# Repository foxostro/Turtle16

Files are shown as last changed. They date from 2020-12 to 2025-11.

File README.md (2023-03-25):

# Turtle16

Turtle16 is a sixteen-bit microcomputer built from discrete logic ICs and other simple parts. This repo contains the Kicad project, and other files necesary to build the hardware, as well as the simulator, assembler, and compiler.

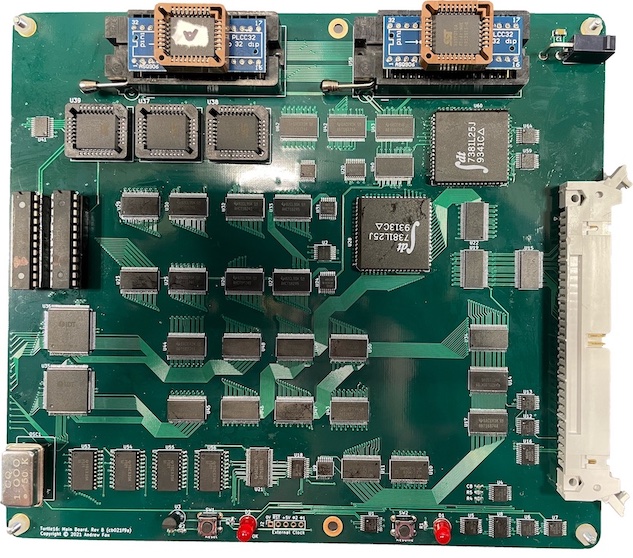
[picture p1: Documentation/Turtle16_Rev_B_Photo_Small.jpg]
Photo of Turtle16 CPU


## Computer Specifications

* Sixteen-bit homebrew CPU
* Five stage classic RISC pipeline, executing one instruction per clock cycle
* Eight general-purpose registers
* Operand forwarding to automatically resolve read-after-write hazards
* Pipeline stalls to automatically resolve other sorts of hazards
* No branch delay slots
* Primitive branch prediction, always predicting the branch is not taken

## Why did you do this?

I find computer architecture to be very interesting. Having already built a couple of homebrew breadboard computers in the style of the SAP-1, I wanted to do something more advanced. This an opportunity to learn how the classic five stage RISC pipeline works. While it would also be possible to build something like this in an FPGA, or even just an HDL simulator, I appreciate the physical reality of building an actual thing. At the same time, I've been learning so much about PCB layout, circuit design, circuit assembly and construction, and debugging, much of which seems broadly applicable to any electronics project.

Careful self-imposed limitations are important for a successful project. Limitation breeds creativity. For this project, the implementation of the CPU itself has been constrained to use only simple 7400-style parts. This means sticking to discrete logic and other medium-scale integration parts. Microprocessors and advanced FPGAs have been avoided. An exception has been made for primitive GALs as these fit the retro computer aesthetic.

For the computer's peripherals, I might relax these limitations in favor of getting something working. For example, I'm considering using an Arduino to interface with a PC. The sound hardware could be built around a retro-style audio IC such as one of the Yamaha OPL series chips or the Phillips SAA1099.

The danger of relaxing limitations is that it raises the question, why not go further? If I decide it's fine to implement graphics using a retro-style chip like the TMS9918A then why not use a Raspberry Pi, or the Gameduino 3X Dazzler? Why not simply implement the entire computer in an emulator running on a Raspberry Pi? Once placed in an enclosure, it won't look any different. The answer is that the project is not about the goal of building a working computer, or the goal of playing some games. This project is centered around learning how computers work.

## Getting Started

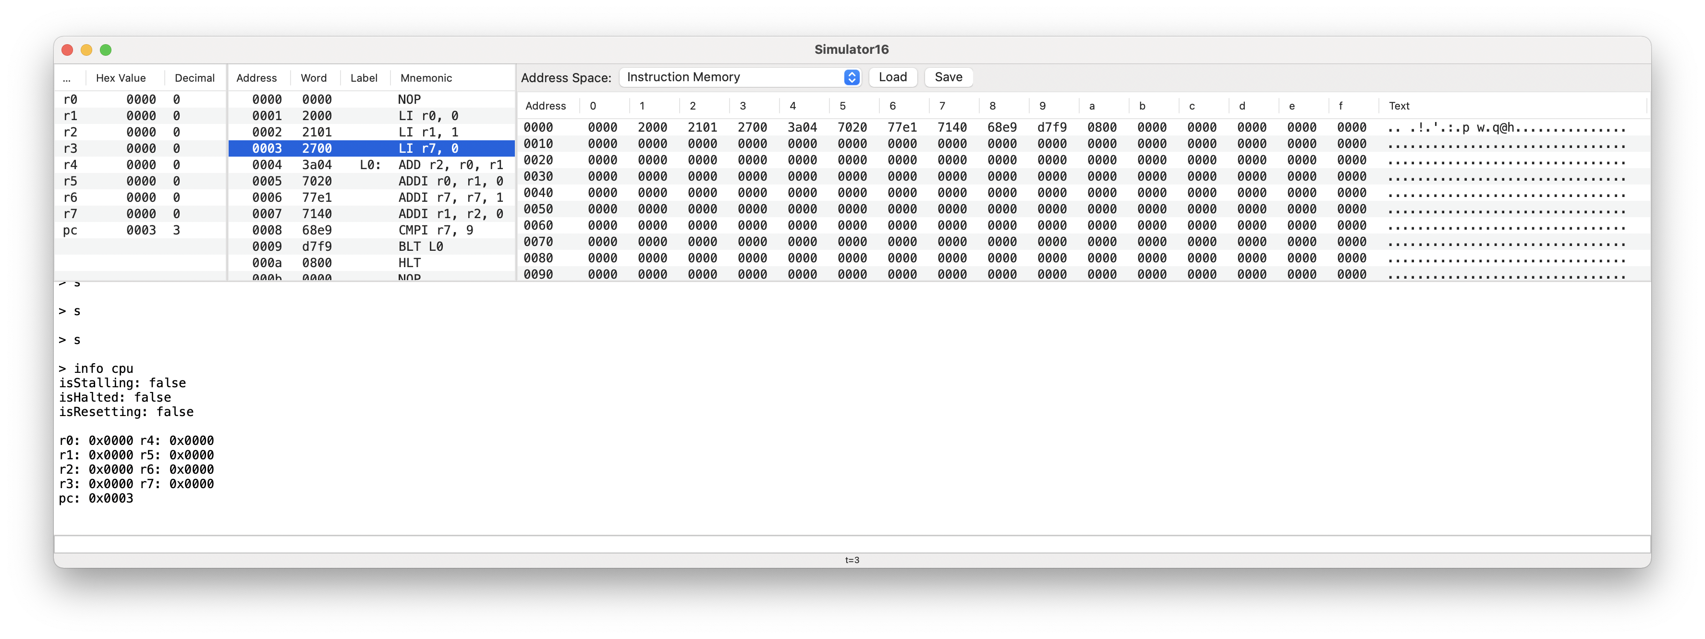
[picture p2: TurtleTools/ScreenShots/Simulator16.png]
Simulator16 Screen Shot


The simulator app can be used to simulate the computer and run example programs without having to build the hardware. The interactive debugger can be used to inspect the state of the computer. Several example saved simulator sessions are available in the TurtleTools/Examples/ directory. (At some point, I should add some better demoes. These are mostly just programs that I used in hardware verification.)

To run the simulator, open the TurtleTools Xcode project and run the Simulator16 scheme. Refer to the [Tool Chain](Documentation/TurtleTools.md) page for more details.

## Documentation

* [Architecture Overview](Documentation/Architecture.md)
* [Instruction Set Architecture](Documentation/ISA.md)
* [Programming](Documentation/Programming.md)
* [Tool Chain](Documentation/TurtleTools.md)
* [Bugs](Documentation/Bugs.md)
* [Future Work](Documentation/Future.md)

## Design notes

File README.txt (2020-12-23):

Turtle16 is a sixteen-bit microcomputer built from discrete logic ICs and other simple parts. This repo contains the Kicad project and other files necesary to build the hardware. The toolchain and software is provided in a separate repo.

Project Constraints
-------------------
Microprocessors and programmable hardware such as CPLDs and FPGAs have been avoided. An exception has been made for primitive GALs as these fit the retro computer aesthetic.

Architecture Overview
---------------------
The CPU uses a Load/Store architecture based on the classic RISC pipeline. There are eight general-purpose registers, each sixteen bits wide. The load/store unit fetches sixteen-bit words from a sixteen-bit address space. Instructions and Data are split into two separate address spaces, avoiding any possible structural hazard from accessing instructions and data simultaneously.

Pipeline Stages:
1. IF — Fetch an instruction from Instruction Memory via the Program Counter
2. ID — Decode instruction and read the register file. This also performs hazard control on decoding the instruction.
3. EX — Marshal operands and perform a computation
4. MEM — Either read or write to memory
5. WB — Write results back to the register file

The control unit implements primitive branch prediction which always predicts the branch is not taken and then flushes the pipeline when it ever actually is, thus avoiding the need for branch delay slots. A delay slot between the ALU's computation of flags and the Instruction Decode stage's use of flags is avoided by having the control unit stall the CPU for one cycle. Read-After-Write hazards are also avoided by stalling the CPU until the hazard has passed.

The register file is implemented in two dual port SRAMs operating in parallel. This allows for a triple-port register file with one write port and two read ports. With careful design, a write in the write-back stage can be assured to be committed before a register file read in the same cycle. Due to space limitations in the instruction word, only three bits can be devoted to the register index. The register can only provide eight homogeneous, general-purpose registers.

The ALU is built around an IDT 7831. This is a monolithic, sixteen-bit ALU IC that was produced in the early 90's.

Peripheral devices may halt the CPU by pulling the shared RDY signal low using an open-drain buffer such as 74AHCT07A. While halted this way, the CPU disconnects from the bus so that peripheral devices may drive the bus as they see fit. The CPU's Phi1 clock immediately drops to zero and stops. The CPU's Phi2 clock is unaffected, and this is the one exposed to peripheral devices.

The clock module ensures /RDY only takes affect on the clock edge so devices may acquire and release /RDY at any time.

The main board does not include RAM or peripherals. The intention is that these devices would be implemented on separate boards and connected to the main board through an external peripheral connector.

Control Signals
---------------
The instruction decoder in the ID stage of the CPU pipeline decode the five-bit opcode into twenty one control signals which control subsequent pipeline stages.

0. /HLT — Halt the clock
1. SelStoreOpA — Select the source of the Store operand
2. SelStoreOpB — "
3. SelRightOpA — Select the source of the Right operand
4. SelRightOpB — "
5. /FI — Update the flags register
6. ALU C0 — ALU carry-in
7. ALU I0 — ALU function bit 0
8. ALU I1 — ALU function bit 1
9. ALU I2 — ALU function bit 2
10. ALU RS0 — ALU RS0 operand mux control
11. ALU RS1 — ALU RS1 operand mux control
12. /J — Instruct the program counter to add the specified offset to itself.
13. /JABS — Absolute jump
14. /MemLoad — Drive /MemLoad onto the bus, instructing peripheral device to Load
15. /MemStore — Drive /MemStore onto the bus, instructing peripheral device to Store
16. /AssertStoreOp — Drive the Store operand onto the bus I/O lines
17. WriteBackSrc — Select the source to write back to the register file
18. /WRL — Write the lower upper byte in the register file's write port
19. /WRH — Write the upper byte in the register file's write port
20. /WBEN — Enable write back to register file

The ID stage contains hazard control logic which additionally produces signals for stalling and flushing the pipeline:

STALL_PC -- Stalls the Program Counter in the IF stage.
/STALL_IF -- Stalls the Instruction Fetch unit in the IF stage.

Opcodes
-------
The ID stage uses a ROM to decode a five-bit opcode into an array of control signals. The opcodes are as follows. Though, this is definitely something that can be redefined by flashing different data to the chips.

0. nop
1. hlt
2. load
3. store
4. li
5. lui
6. cmp
7. add
8. adc
9. sub
10. sbc
11. and
12. or
13. xor
14. not
15. cmpi
16. addi
17. subi
18. andi
19. ori
20. xori
21. noti
22. jmp
23. jr
24. jalr
25. beq
26. bne
27. blt
28. bge
29. bltu
30. bgeu
31. unused

Instruction Encoding
--------------------
At the top-level instructions have the following forms...

RRR — 0bkkkk'kccc'aaab'bbxx
RRI — 0bkkkk'kccc'aaai'iiii
RII — 0bkkkk'kccc'iiii'iiii
IRI — 0bkkkk'kiii'aaai'iiii
IRR — 0bkkkk'kiii'aaab'bbii
III — 0bkkkk'kiii'iiii'iiii
X   — 0bkkkk'kxxx'xxxx'xxxx

where 'k' is a 5-bit opcode, 'c' is the index of the register to select in the write back stage, 'a' is the index of the register to select for the ALU left operand, 'b' is the index of the register to select for the ALU right operand, and 'i' is an immediate value.

More generally, there is a field for an opcode and the fields for a, b, and c. Some instructions are able to use unused bits from the latter three fields to form an immediate value. The final two bits may also contribute to an immediate value.

NOP (X-format)
--------------
The NOP instruction specifically has all zero instruction bits. The decoded control signals do not assert any control signals at all. The instruction does nothing.

HLT (X-format)
--------------
The HLT instruction halts the CPU clock. There will be a button to resume execution.

LOAD (RRI-format)
-----------------
0bkkkk'kccc'aaai'iiii

Loads a sixteen-bit word from memory at the address given by Ra + Imm and writes that value to the register Rc.

	Rc := mem[Ra + Imm]

STORE (IRR-format)
------------------
0bkkkk'kiii'aaab'bbii

Stores the contents of the register Rc to memory at the address given by Ra + Imm.

	mem[Ra + Imm] := Rc

LI (RII-format)
---------------
0bkkkk'kccc'iiii'iiii

Takes the immediate value, sign-extends it from eight to sixteen bits, and writes it to the register Rc.

	Rc := Imm

LUI (RII-format)
----------------
0bkkkk'kccc'iiii'iiii

Takes the immediate value, shifts it left by eight, and writes it to the upper eight bits of the register Rc. (The lower eight bits are unchanged.)

	Rc[8:15] := Imm

ALU instructions (RRR-format and RRI-format)

The ALU operands are selected by an array of multiplexer circuitry.

The Store Operand may be one of the following...
1. Rb
2. Rb << 8
3. PC+1
4. Eight-bit immediate value

The Right Operand may be one of the following...
1. Rb
2. The five-bit immediate value, ins[4:0]
3. The five-bit immediate value, ins[10:8, 1:0]
4. The eight-bit immediate value, ins[10:8, 4:0]

The Left Operand is always Ra.

The instruction decode stage provides control signals to choose the ALU function and set the carry input. The result feeds back to the program counter as well as feeding into the ALU result interstage register. Condition codes produced by the ALU go into a flags register and may be latched if the appropriate control signal is asserted.

JMP (III-format)
----------------
0bkkkk'kiii'iiii'iiii

Perform an unconditional pc-relative jump by the eleven-bit offset given in Imm:

	NPC := PC + Imm

JR (IRI-format)
---------------
0bkkkk'kiii'aaai'iiii

Perform an unconditional absolute jump, computing Ra + Imm and setting PC to the result:

	NPC := Ra + Imm

JALR (RRI-format)
-----------------
0bkkkk'kccc'aaai'iiii

Perform an unconditional absolute jump, computing Ra + Imm and setting PC to the result. Store the return address in the register Rc.

	NPC := Ra + Imm
	Rc := PC+1
	
As this instruction uses a five-bit immediate value, it is expected that most procedure calls will involve a couple of instructions to fill a register with the absolute jump target. The five-bit immediate value is so small that it isn't even expected to be particularly useful, but that removing it entirely is more complicated than leaving it in.

BEQ (III-format)
----------------
0bkkkk'kiii'iiii'iiii

Perform a conditional pc-relative jump when the Z flag is set:

	NPC := PC + Imm

BNE (III-format)
----------------
0bkkkk'kiii'iiii'iiii

Perform a conditional pc-relative jump when the Z flag is not set:

	NPC := PC + Imm

BLT (III-format)
----------------
0bkkkk'kiii'iiii'iiii

Perform a conditional pc-relative jump when the OVF flag is set, performing a signed less-than comparison:

	NPC := PC + Imm

BGE (III-format)
----------------
0bkkkk'kiii'iiii'iiii

Perform a conditional pc-relative jump when the OVF flag is not set, performing a signed great-than-or-equal-to comparison:

	NPC := PC + Imm

BLTU (III-format)
-----------------
0bkkkk'kiii'iiii'iiii

Perform a conditional pc-relative jump when the Carry flag is set, performing an unsigned less-than comparison:

	NPC := PC + Imm

BGEU (III-format)
------------------
0bkkkk'kiii'iiii'iiii

Perform a conditional pc-relative jump when the Carry flag is not set, performing an unsigned great-than-or-equal-to comparison:

	NPC := PC + Imm

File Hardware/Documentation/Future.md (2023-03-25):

# Turtle16: Future Work

## Interrupts

The Turtle16 CPU lacks interrupts and exceptions entirely. While I have a plan to implement these, it does require changes across the entire CPU and will not come sooner than Rev D. It requires extensive changes to the ID stage and Register File too. In short, new CSRs can be added to record the exception cause, the PC of the interrupted instruction, the address of the exception handler, and a status register to enable/disable interrupts. New instructions can be added to store and load these registers from a program and they are intrinsically accessible within the ID stage. A new instruction must be added to return from an exception, re-enabling interrupts and jumping to the address of the exception handler. New shared, open-collector IRQ lines must be added to the system memory bus, possibly by rearranging pins and replacing some of the ground pins. The ID stage will detect that an IRQ line has been asserted and respond by interrupting the current instruction, recording CPU state in the CSRs, disabling interrupts, and jumping to the address of the exception handler.

## Virtual Memory and Larger Amounts of RAM

The The memory banking system allows different memory mappings to be applied under different banking configurations. One idea I've considered is always mapping built-in instruction RAM into the upper half of the address space, and having peripherals such as Video and Audio devices map into the lower half of the address space in different banks. It would also be possible to add a MMU peripheral where the lower half of the address space is an MMU which mediates access to peripherals by way of a page table in memory. However, 32K of address space does not leave room for many pages of memory.

One of the memory-mapped peripherals could be a large RAM. Say, a 128MB DRAM SIMM. The lower fixteen bits of the memory address are specified on the memory bus. The upper twelve bits of the address space are specified by a memory-mapped page register. A running program must be aware of the page register and many memory accesses will require several instructions. A compiler could help to make this transparent to the programmer.

## Bit Shifter

Bit shifting with the ALU today is very difficult and expensive, especially shifting right. Fortunately, this complexity can mostly be hidden by the compiler which provides LSL and LSR instructions in the intermediate representation ISA and compiles to long sequences of native instructions to implement the operation. Adding hardware support for bit shifting would provide a massive performance improvement. Even a bit shifter which only shifts one bit to the right would be a massive improvement.

With additional control lines, and additional circuitry in the EX stage, it would be possible to implement a full sixteen-bit one-cycle shifter. Though, this will require a lot of additional logic and PCB real estate.

The SelRightOp signal can expanded from two bits to three bits with one additional control signal going into the EX stage. The SelectRightOperand unit can accept the three bit input and has four unused outputs on the decoder (U40) which can be used to control shifting modes. One additional 74AHCT16245 bus transceiver in this unit can provide the ability to perform logical and arithmetic shifts to the right by one bit. This will surely provide massive imnprovements to performance with minimal additional logic and minimal additional area.

## Branch Prediction

It would be possible to implement branch prediction in the CPU. The possible benefit of this is to eliminate the two cycle stall after a branch in correctly predicted branches.

One of the simplest possible improvements would be to predict that backwards branches are taken. More complicated branch predictors are also possible but require additonal logic and a lot of PCB real estate.

## Superscalar

Quad pumped memory would allow the instruction fetch stage to fetch two instructions each cycle and perform two memory accesses in the MEM stage each cycle. The pipeline can be duplicated so that we execute two instructions at the same time. This may involve some restrictions on which instructions may be placed in the even and odd positions, similar to what we see on the original Pentium processor. This definitely will involve a lot of additional logic in the ID stage for hazard control.

## Two-address Instructions

The sixteen-bit instructions of the Turtle16 ISA do not leave many bits to encode registers. The current compromise is to support only eight GPRs. It would be possible to move to an ISA with two operands to allow for a four-bit register index and up to sixteen GPRs. This, of course, requires extensive changes across the CPU, Simulator, and tool chain.

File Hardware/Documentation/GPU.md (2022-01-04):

# Crush, a pipelined multithreaded GPU for Turtle16

## Specifications

Crush is a CPU designed for graphics applications and so will also be referred to as a GPU in this document. It has thirty-two sixteen-bit general purpose registers, a six stage pipeline, and a separate 64K address space for instruction memory and RAM. While the data memory bus and eah register is sixteen-bits wide, the instruction word itself is 32-bits wide.

An additional 64K address space is available for RAM which is shared with the controlling CPU. This is accessed with a separate set of load/store instructions. Fast copies between address spaces are possible with a special blit instruction.

The pipeline implements fine-grained multithreading. Each clock the CPU will switch to a different hardware thread, maintaining a separate register file and program counter per thread. This avoids the need for hardware interlocks and pipeline hazard control. There are no stalls. Branch prediction and branch delay slots are not necessary in this scheme. Since the register file is built from an SRAM, this may be implemented by putting the Thread ID into the upper bits of the memory's address input.

A memory-mapped control register will allow the controlling CPU to set the number of threads to execute, with a special value of zero meaning that the entire GPU is to be halted. Typically, the CPU will operate with a number of threads equal to the number of tiles in the frame buffer.

The CPU has special address decoding hardware in the MEM stage to allow each thread to retrieve it's Thread ID from a special memory-mapped register.

The EX stage of the pipeline includes a 16-bit ALU for basic arithmetic operations, and also a barrel shifter for performing a logical bit shift in one clock cycle. (Aside: the render kernel discussed below only uses left shifts by three and by eight. So we could get away with implementing a bit shifter which provides this functionality and not a full barrel shifter.)

The GPU-side memory bank swaps between two 256x256 frame buffers according to a memory-mapped control register which is used to select the current page and flip pages. The RAMDAC operates on the opposite bank of memory as the GPU at all times. The RAMDAC will generate a video signal using a 200x150 window in the frame buffer which can be moved with a pair of memory-mapped scrolling control registers. 

Image data is always assumed to be in power-of-two sizes. Images in memory and in the frame buffer are assumed to be addressable with simple bit shift and bitwise-or so as to reduce the amount of arithmetic needed to index into the bitmaps. Like so: `addr = ((y << 8) | x)`. This leads to behavior where sprites always wrap around the edges of the frame buffer. Use the scrolling registers to move this wrapping behavior off screen if this is undesirable.

The first version of Crush will probably have a single execution core. However, it seems at this stage that most pipeline stages will be able to operate twice in one clock, with the exception perhaps of control logic and the ALU. Specifically, it may be possible to perform two instruction fetches and two memory accesses (per bank) in one clock cycle. A dual-core processor implementation is therefore a possibility which would immediately double the performance of the GPU.

## Pipeline

1. IF -- Instruction Fetch
2. ID -- Instruction Decode
3. EX -- Execute
4. MEMA -- Access the first address space, shared with CPU
5. MEMB -- Access the second address space, shared with RAMDAC
6. WB -- Write back

### Instruction Formats

Instructions may take one of the following formats:

Format | Encoding scheme
------ | ------------------------------------------------
I      | `0bkkkk'kkcc'ccca'aaaa'iiii'iiii'iiii'iiii'iiii`
R      | `0bkkkk'kkcc'ccca'aaaa'bbbb'bbxx'xxxx'xxxx'xxxx`
X      | `0bkkkk'kkxx'xxxx'xxxx'xxxx'xxxx'xxxx'xxxx'xxxx`

The `k' field is a 6-bit opcode.
The `c' field is a 5-bit index to specify the destination register.
The `a' field is a 5-bit index to specify the left operand register.
The `b' field is a 5-bit index to specify the right operand register.
The `i` field is a 16-bit immediate value.

### Opcodes

0. nop
1. hlt
2. lw
3. sw
4. lw2
5. sw2
6. bitblt
7. li
8. add
9. addi
10. sub
11. subi
12. and
13. andi
14. or
15. ori
16. xor
17. xori
18. lsl
19. lsli
20. lsr
21. lsri
22. not
23. jmp
24. jr
25. jalr
26. beq
27. bne
28. blt
29. bge
30. ble
31. bgt
32. bltu
33. bgeu
34. bleu
35. bgtu

Remaining opcodes are reserved for future expansion.

#### NOP (X-format)

The NOP instruction does nothing. An instruction word which contains all zeroes is always a NOP.

#### HLT (X-format)

The HLT instruction halts the CPU clock. There will be a button to resume execution.

#### LW (R-format)

Loads a sixteen-bit word from memory address space 1 at the address given by Ra and writes that value to the register Rc. The immediate value allows the program to specify a static offset into memory.

```
Rc := mem1[Ra + Imm]
```

#### SW (I-format)

Stores the contents of the register Rc to memory in memory address space 1 at the address given by Ra. The immediate value allows the program to specify a static offset into memory.

```
mem1[Ra + Imm] := Rc
```

#### LW2 (I-format)

Loads a sixteen-bit word from memory address space 2 at the address given by Ra and writes that value to the register Rc. The immediate value allows the program to specify a static offset into memory.

```
Rc := mem2[Ra + Imm]
```

#### SW2 (I-format)

Stores the contents of the register Rc to memory in memory address space 2 at the address given by Ra. The immediate value allows the program to specify a static offset into memory.

```
mem2[Ra + Imm] := Rc
```

#### BITBLT (I-format)

Reads a value from memory address A at the address given by Ra. If the Alpha bit is set then the value is stored to memory address space B at the address given by Ra. This permits the GPU to implement screen door transparency. The immediate value allows the program to specify a static offset into memory.

```
mem2[Ra + Imm] := mem1[Ra + Imm]
```

#### LI (I-format)

Takes the 16-bit immediate value and writes it to the register Rc.

```
Rc := Imm
```

#### ADD (R-format)

Adds the values of the two register operands and writes the result to register Rc.

```
Rc := Ra + Rb
```

#### ADDI (I-format)

Adds the values of the register operand to the immediate value and writes the result to register Rc.

```
Rc := Ra + Imm
```

#### SUB (R-format)

Subtracts the values of the two register operands and writes the result to register Rc.

```
Rc := Ra + Rb
```

#### SUBI (I-format)

Subtracts the immediate value from the register operand and writes the result to register Rc.

```
Rc := Ra - Imm
```

#### AND (R-format)

Computes the bitwise AND of the values of the two register operands and writes the result to register Rc.

```
Rc := Ra & Rb
```

#### ANDI (I-format)

Computes the bitwise AND the values of the register operand and the immediate value and writes the result to register Rc.

```
Rc := Ra & Imm
```

#### OR (R-format)

Computes the bitwise OR of the values of the two register operands and writes the result to register Rc.

```
Rc := Ra | Rb
```

#### ORI (I-format)

Computes the bitwise OR the values of the register operand and the immediate value and writes the result to register Rc.

```
Rc := Ra | Imm
```

#### XOR (R-format)

Computes the bitwise XOR of the values of the two register operands and writes the result to register Rc.

```
Rc := Ra ^ Rb
```

#### XORI (I-format)

Computes the bitwise XOR the values of the register operand and the immediate value and writes the result to register Rc.

```
Rc := Ra ^ Imm
```

#### LSL (R-format)

Computes the logical left shift of the two register operands and writes the result to register Rc.

```
Rc := Ra << Rb
```

#### LSLI (I-format)

Computes the logical left shift of the register operand and the immediate value and writes the result to register Rc.

```
Rc := Ra << Imm
```

#### LSR (R-format)

Computes the logical right shift of the two register operands and writes the result to register Rc.

```
Rc := Ra >> Rb
```

#### LSRI (I-format)

Computes the logical right shift of the register operand and the immediate value and writes the result to register Rc.

```
Rc := Ra >> Imm
```

#### NOT (I-format)

Computes the bitwise negation of the register operand and writes the result to register Rc.

```
Rc := ~Ra
```

#### JMP (I-format)

Perform an unconditional pc-relative jump by the offset specified in the 16-bit immediate value.

```
NPC := PC + Imm
```

#### JR (R-format)

Perform an unconditional absolute jump, computing Ra + Imm and setting PC to the result:

```
NPC := Ra + Imm
```

#### JALR (I-format)

Perform an unconditional absolute jump to the branch target specified by Ra + Imm. Store the return address in the register Rc.

```
NPC := Ra + Imm
Rc := PC
```

#### BEQ (I-format)

Compare the values of the two register operands. If Ra == Rb then perform a pc-relative jump by the offset specified in the immediate value.

```
NPC := PC + Imm
```

#### BNE (I-format)

Compare the values of the two register operands. If Ra != Rb then perform a pc-relative jump by the offset specified in the immediate value.

```
NPC := PC + Imm
```

#### BLT (I-format)

Compare the values of the two register operands. If Ra < Rb then perform a pc-relative jump by the offset specified in the immediate value.

```
NPC := PC + Imm
```

#### BGE (I-format)

Compare the values of the two register operands. If Ra >= Rb then perform a pc-relative jump by the offset specified in the immediate value.

```
NPC := PC + Imm
```

#### BLTE (I-format)

Compare the values of the two register operands. If Ra <= Rb then perform a pc-relative jump by the offset specified in the immediate value.

```
NPC := PC + Imm
```

#### BGT (I-format)

Compare the values of the two register operands. If Ra > Rb then perform a pc-relative jump by the offset specified in the immediate value.

```
NPC := PC + Imm
```

#### BLTU (I-format)

Compare the values of the two register operands. If Ra < Rb then perform a pc-relative jump by the offset specified in the immediate value. This is an unsigned comparison.

```
NPC := PC + Imm
```

#### BGEU (I-format)

Compare the values of the two register operands. If Ra >= Rb then perform a pc-relative jump by the offset specified in the immediate value. This is an unsigned comparison.

```
NPC := PC + Imm
```

#### BLTEU (I-format)

Compare the values of the two register operands. If Ra <= Rb then perform a pc-relative jump by the offset specified in the immediate value. This is an unsigned comparison.

```
NPC := PC + Imm
```

#### BGTU (I-format)

Compare the values of the two register operands. If Ra > Rb then perform a pc-relative jump by the offset specified in the immediate value. This is an unsigned comparison.

```
NPC := PC + Imm
```

### Render Kernel

The general algorithm for rendering a tile is as follows. This assumes all sprites are 16x16 so we don’t need to consider the overhead of a dynamic loop or loading the width from memory. Also, the number of virtual sprites is fixed at compile time.

```
struct Sprite {
    srcX: u16
    srcY: u16
    dstX: u16
    dstY: u16
}

let spriteList: [numSprites ; Sprite]
let rasterY: Int = gThreadID
let dst0 = rasterY << 8

while true {
	// Draw the background tile layer
	for tileX in 0..<kTileMapWidth {
		let tileId = tileMap[rasterY + tileX]
		let tilePixel = tileImageData[tileId]
		let dst = dst0 + (tileX * 8)
		bitblit(dst, tilePixel, 0)
		bitblit(dst, tilePixel, 1)
		bitblit(dst, tilePixel, 2)
		bitblit(dst, tilePixel, 3)
		bitblit(dst, tilePixel, 4)
		bitblit(dst, tilePixel, 5)
		bitblit(dst, tilePixel, 6)
		bitblit(dst, tilePixel, 7)
	}

	for i in 0..kNumberOfSprites {
		let srcY = spriteList[i].srcY
		let y = srcY - rasterY
  	if y > 0 && y < kSpriteHeight {
	    let srcX = spriteList[i].srcX
	    let src = (y << 8) | srcX
    	let dst = dst0 | dstX

    	bitblit(dst, src, 0)
    	bitblit(dst, src, 1)
    	bitblit(dst, src, 2)
    	bitblit(dst, src, 3)
    	bitblit(dst, src, 4)
    	bitblit(dst, src, 5)
    	bitblit(dst, src, 6)
    	bitblit(dst, src, 7)
    	bitblit(dst, src, 8)
    	bitblit(dst, src, 9)
    	bitblit(dst, src, 10)
    	bitblit(dst, src, 11)
    	bitblit(dst, src, 12)
    	bitblit(dst, src, 13)
    	bitblit(dst, src, 14)
    	bitblit(dst, src, 15)
    } // if
	} // for

	if rasterY == kFrameBufferHeight-1 {
		flipPage()
	} else {
		waitForPageFlip()
	}
} // while true
```

Manually compile to assembly code. Use readable names instead of register names. There are less than 32 unique names here so there won't be any register spilling:

```
# let rasterY: Int = gThreadID
LI tid, &gThreadID

LI zero, 0
LI currentPage, &gCurrentPage

# let dst0 = rasterY << 8
LSLI dst0, rasterY, 8

LI spriteAddr, &gSpriteList

LI tileMapAddr0, &gTileMap
ADD tileMapAddr0, tileMapAddr0, rasterY

LI tileImageDataAddr, &gTileImageData

# while true {
MainLoop:

# Optimized code to draw the tile map on this row...
# This takes 12*25=300 cycles
for tileX in 0..<32 {
	LW tile, tileMapAddr0, tileX
	LSLI tile, 3
	ADD tile, tileImageDataAddr, tile
	ADDI tileDst, dst0, tileX
	BITBLIT tileDst, tile, 0
	BITBLIT tileDst, tile, 1
	BITBLIT tileDst, tile, 2
	BITBLIT tileDst, tile, 3
	BITBLIT tileDst, tile, 4
	BITBLIT tileDst, tile, 5
	BITBLIT tileDst, tile, 6
	BITBLIT tileDst, tile, 7
}

# for i in 0..<kNumberOfSprites {
SpriteLoop:
LI i, kNumberOfSprites

# let srcY = spriteList[i].srcY
LW srcY, spriteAddr, offsetof(srcY)

# var height = spriteList[i].height
LW height, spriteAddr, offsetof(height)

# let y = srcY - rasterY
SUB y, srcY, rasterY

# if y > 0 && y < height {
BLE y, zero, NotInBounds
BGE y, height, NotInBounds

# let srcX = spriteList[i].srcX
LW srcX, spriteAddr, offsetof(srcX)

# let src = (y << 8) | srcX
LSLI src, y, 8
OR src, src, srcX

# let dst = dst0 | dstX
OR dst, dst0, dstX

BITBLIT dst, src, 0
BITBLIT dst, src, 1
BITBLIT dst, src, 2
BITBLIT dst, src, 3
BITBLIT dst, src, 4
BITBLIT dst, src, 5
BITBLIT dst, src, 6
BITBLIT dst, src, 7
BITBLIT dst, src, 8
BITBLIT dst, src, 9
BITBLIT dst, src, 10
BITBLIT dst, src, 11
BITBLIT dst, src, 12
BITBLIT dst, src, 13
BITBLIT dst, src, 14
BITBLIT dst, src, 15

# } // if
NotInBounds:

# } // for
ADDI spriteAddr, sizeof(Sprite)
SUBI i, 1
BNZ SpriteLoop

# if rasterY == kFrameBufferHeight-1 {
LI10 currentPageAddr, &gCurrentPage
LI10 frameBufferHeightMinusOne, kFrameBufferHeight-1
BEQ rasterY, frameBufferHeightMinusOne, WaitForPageFlip
# Flip the page
LW currentPage, currentPageAddr
XOR currentPage, 1 # Toggle the LSB to swap the page
SW currentPageAddr, currentPage
JMP endIf
WaitForPageFlip:
LOAD nextPage, currentPageAddr
BEQ currentPage, nextPage, WaitForPageFlip
endIf:

# } // while true
JMP MainLoop
```

### Render Kernel Performance

The render kernel can operate on an unlimited number of 16x16 sprites. However, at a certain point, performance will degrade and we'll be unable to meet the frame time budget. Let's make some assumptions and then calculate a rough estimate of the time needed to render a frame.

The tile map is a 32x32 map and each tile is 8x8 in size. We only render 25 tiles because those are the ones that are visible on screen. We support three tile map layers.

Assume there are N sprites in the sprite list. Assume a 20MHz clock cycle (50ns). Assume the machine supports up to 256 threads, and that we'll be using 150 of those to render the 150 visible rows of the frame buffer.

In 32ms, there are 640,000 clock cycles. We divide those cycles between 150 threads to get a budget of 4266 cycles per thread.

Manually counting the cycles in the above program, we express the number of clock cycles in terms of the number of sprites N, considering only the main loop:

```
SpriteLoop = N * 29
PageFlip = 7
MainLoop = 300*3 + 4 + SpriteLoop + PageFlip
4266 = 300*3 + 4 + N*29 + 7
N = (4266 - (300*3 + 4 + 7)) / 19
N = 176.6
```

A maximum of 176 sprites is great! I'd probably cap it at 128 to provide some slack.

Possibly, there's enough free cycles to add additional features such as adding fine scrolling to the tile map layers.

If we add a second thread to the GPU then performance greatly improves. Each core can operate on one half of the frame buffer. Each thread would then immediately have double the amount of time to complete it's work:

```
SpriteLoop = N * 29
PageFlip = 7
MainLoop = 300*3 + 4 + SpriteLoop + PageFlip
8533 = 300*3 + 4 + N*29 + 7
N = (8533 - (300*3 + 4 + 7)) / 19
N = 401
```

A maximum of 401 sprites is more than enough. So we could consider instead adding new features such as sprites of different sizes and additional scrolling capabilities. Transparency with blending might be possible if it's used for a small number of on-screen sprites.

I'm fairly certain there isn't going to be enough cycles to implement sprite scaling or rotation.

The CPU can change the program on the GPU to change it's capabilities to suit the needs of the current app. For example, one game could use blending transparency and another uses lots of sprites. Some apps may want to proceed at a lower frame rate and use the cycles for something like line drawing, or raw pixel access, in a paint program.

Using eight bits of the register file address lines for a thread ID means we cannot use 4K x 16 dual port SRAMS here. So if 256 threads is too many then we consider chaning the kernel to have it handle multiple scanlines ever frame. (Unroll the loop at the expense of additional instruction memory.) The 4K x 16 SRAMs have 12 address lines. We need 5 for the register IDs which leaves 7 for a thread ID. That allows for up to 127 threads. So, we can run with 75 threads and have each one handle two rows.

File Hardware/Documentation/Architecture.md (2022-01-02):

# Turtle16: Architecture Overview

Turtle16 is a sixteen-bit microcomputer built from discrete logic ICs and other simple parts.

The CPU is a sixteen-bit, in-order, scalar processor that provides a five stage pipeline. It implements a custom Turtle16 ISA reminiscent of other RISC ISAs. There are eight general-purpose registers, each sixteen bits wide. The load/store unit fetches sixteen-bit words from a sixteen-bit address space. Instructions and Data are split into two separate address spaces, avoiding any possible structural hazard from accessing instructions and data simultaneously.

CPU block diagram CPU Block Diagram

Pipeline Stages:

1. IF — Fetch an instruction from Instruction Memory via the Program Counter. This stage is split into a Program Counter part and an Instruction Memory part and takes two clock cycles to complete. This is sometimes written in diagrams as two pipeline stages, PC and IF.
2. ID — Decode instruction and read the register file. This also performs hazard control on decoding the instruction, and operand forwarding / bypassing.
3. EX — Marshal operands and perform a computation
4. MEM — Either read or write to memory
5. WB — Write results back to the register file

## Clock

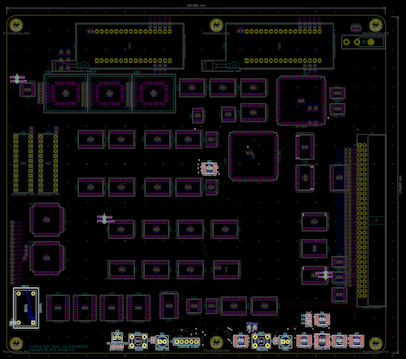
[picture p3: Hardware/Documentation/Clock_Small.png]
Clock Clock module


On paper, I estimate the CPU clock can run at speeds up to 12MHz. This has not yet been tested.

Peripheral devices may halt the CPU by pulling the shared RDY signal low using an open-drain buffer such as 74AHCT07A. While halted this way, the CPU disconnects from the bus so that peripheral devices may drive the bus as they see fit. The CPU's Phi1 and Phi2 clocks immediately drop to zero and stop. The CPU's Phi2 is exposed on the bus to peripheral devices and so these will stop operating as well.

The clock module ensures /RDY only takes affect on the clock edge so devices may acquire and release /RDY at any time.

The HLT instruction will halt the clock. Pressing the resume button permits execution for one clock cycle, giving the CPU enough time to clear the HLT and continue execution. This allows programs to have breakpoints in them for debugging.

## Instruction Fetch (IF)

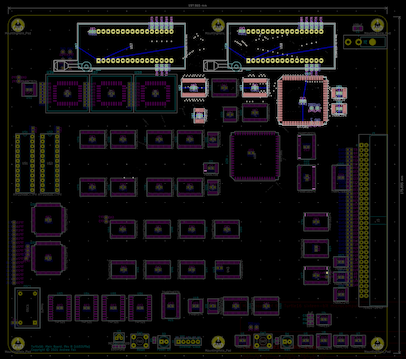
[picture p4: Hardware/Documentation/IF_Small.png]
Instruction Fetch Instruction Fetch pipeline stage


The Program Counter uses the IDT 7381. This is configured in various modes of operation to implement functionality for increment, reset, jump to an absolute branch target, or jump to a relative branch target.

## Instruction Decode (ID)

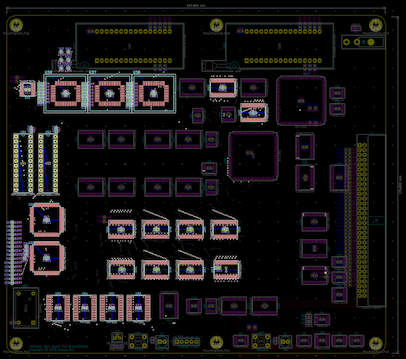
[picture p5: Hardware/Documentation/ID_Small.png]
Instruction Decode Instruction Decode pipeline stage


The ID stage uses a ROM to decode a five-bit opcode in the instruction word to a set of twenty one control signals.

Control Signals:

0. /HLT — Halt the clock
1. SelStoreOpA — Select the source of the Store operand
2. SelStoreOpB — "
3. SelRightOpA — Select the source of the Right operand
4. SelRightOpB — "
5. /FI — Update the flags register
6. ALU C0 — ALU carry-in
7. ALU I0 — ALU function bit 0
8. ALU I1 — ALU function bit 1
9. ALU I2 — ALU function bit 2
10. ALU RS0 — ALU RS0 operand mux control
11. ALU RS1 — ALU RS1 operand mux control
12. /J — Instruct the program counter to add the specified offset to itself.
13. /JABS — Absolute jump
14. /MemLoad — Drive /MemLoad onto the bus, instructing peripheral device to Load
15. /MemStore — Drive /MemStore onto the bus, instructing peripheral device to Store
16. /AssertStoreOp — Drive the Store operand onto the bus I/O lines
17. WriteBackSrc — Select the source to write back to the register file
18. /WRL — Write the lower upper byte in the register file's write port
19. /WRH — Write the upper byte in the register file's write port
20. /WBEN — Enable write back to register file

The control unit implements primitive branch prediction which always predicts the branch is not taken and then flushes the pipeline when it ever actually is, thus avoiding the need for branch delay slots.

The control unit will take care to resolve various hazards automatically. Hazards involving CPU Flags are resolved by stalling the CPU until the hazard has passed. Several types of Read-after-write hazards are resolved by forwarding the desired operand from a subsequent pipeline stage back into Instruction Decode. If the desired result is in the store operand then this is not possible and the pipeline stalls.

(Forwarding of the store operand is left as a possible improvement for a future hardware revision.)

The register file is implemented in two dual port SRAMs operating in parallel. This allows for a triple-port register file with one write port and two read ports. With careful design, a write in the write-back stage can be assured to be committed before a register file read in the same cycle. Due to space limitations in the instruction word, only three bits can be devoted to the register index. The register file can only provide eight homogeneous, general-purpose registers.

## Execute (EX)

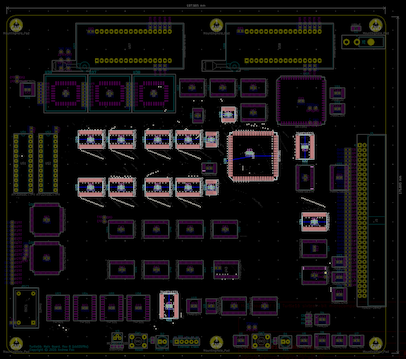
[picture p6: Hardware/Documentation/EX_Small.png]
Execute Execute pipeline stage


The ALU is built around an IDT 7381. This is a monolithic, sixteen-bit ALU IC that was produced in the early 90's. This IC is slightly easier to work with than the venerable 74x181 used in other "7400-series computer" designs.

Operand selection is implemented by using banks of bus transceivers to select one of several sources as input to the ALU. The result is latched in an inter-stage pipeline register. The flags are latched in their own register which feeds back into the ID stage.

The ALU result feeds back into the IF stage to allow it to be used by the program counter on a branch.

## Memory (MEM)

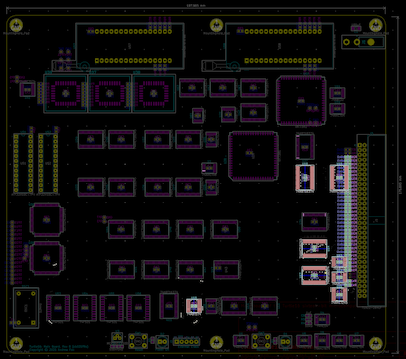
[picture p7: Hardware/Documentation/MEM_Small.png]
Memory Memory pipeline stage


The MEM stage accesses memory. If the CPU is in the halted state then it does not assert signals on the address or data lines, instead effectively disconnecting by putting a bus transceiver into a high impedence state.

## Writeback (WB)

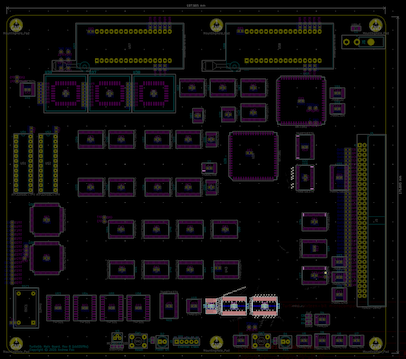
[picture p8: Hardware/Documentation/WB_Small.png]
Writeback Writeback pipeline stage


The WB stage writes a result back to the register file. This must be done in time to read that same value from the register file in the same clock cycle.

## Peripherals

The main board does not include RAM or peripherals. The intention is that these devices would be implemented on separate boards and connected to the main board through an external peripheral connector.

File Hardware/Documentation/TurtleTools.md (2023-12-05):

# Turtle16: TurtleTools

TurtleTools is a toolchain for the Turtle16 microcomputer hardware. This includes a computer Simulator, Assembler, and a Compiler for a new high-level language targeting the hardware.

# Simulator16

Simulator16 Screen Shot

The Simulator app allows simulation of program execution. The interactive debugger allows careful inspection of computer state at each clock tick. There is a view to show disassembly of code in instruction memory. There are views to display the contents of memory in the computer's various address spaces.

The current implementation of the Simulator app attempts to accurately model all the individual pieces of hardware, including compiling and emulating GAL HDL code. The implementation sacrifices performance in favor of a model which will be useful in debugging the actual hardware. A faster interpreter, or even a JIT, is a project that could be attempted in the future.

Please refer to the TurtleTools/Examples/ directory for examples of saved simulator sessions.

# TurtleAssembler

```
usage: TurtleAssembler <INPUT> <OUTPUT>
```

The TurtleAssembler command line tool compiles a single file of assembly source code to a single instruction memory image.

Example assembly program:
```
# Turtle16 program to compute fibonacci numbers.
NOP # We must start a program with a single NOP instruction.
LI r0, 0
LI r1, 1
LI r7, 0
loop:
ADD r2, r0, r1
ADDI r0, r1, 0
ADDI r7, r7, 1
ADDI r1, r2, 0
CMPI r7, 9
BLT loop
HLT
```

Please refer to the TurtleTools/Examples/ directory for more example code.

# Snap

There is also a compiler for a new high-level language called Snap which is covered in more detail [here](Snap.md). Programs written in this language are compiled to machine code which can execute in the simulator app and flashed to instruction EEPROM to be run on real hardware.

```
USAGE:
Snap [test] [options] file...

OPTIONS:
	test       Compile the program for testing and run immediately in a VM.
	-h         Display available options
	-o <file>  Specify the output filename
	-S         Output assembly code
	-ir        Output intermediate representation
	-ast-dump  Print the abstract syntax tree to stdout
	-q         Quiet. Do not print progress to stdout
	-O0        Disable optimizations
```

There is also a compiler for a new high-level language called Snap.

Example Snap program:
```
var a = 1
var b = 1
for i in 0..10 {
	var fib = b + a
	a = b
	b = fib
}
```

Another, slightly more complex example:
```
import audio
import serial

func main() {
	let noteLength = 2
	setMasterAudioGain(0x80)
	serialInit()
	serialPuts("Piano\n")
	while true {
		while serialCount() == 0 {}
		let character = serialGet()
		if character == 'a' {
			serialPuts("A3\n")
			playNote(noteA3, noteLength)
		}
		else if character == 's' {
			serialPuts("B3\n")
			playNote(noteB3, noteLength)
		}
		else if character == 'd' {
			serialPuts("C4\n")
			playNote(noteC4, noteLength)
		}
		else if character == 'f' {
			serialPuts("D4\n")
			playNote(noteD4, noteLength)
		}
		else if character == 'g' {
			serialPuts("E4\n")
			playNote(noteE4, noteLength)
		}
		else if character == 'h' {
			serialPuts("F4\n")
			playNote(noteF4, noteLength)
		}
		else if character == 'j' {
			serialPuts("G4\n")
			playNote(noteG4, noteLength)
		}
		else if character == 'k' {
			serialPuts("A4\n")
			playNote(noteA4, noteLength)
		}
		else if character == 'l' {
			serialPuts("B4\n")
			playNote(noteB4, noteLength)
		}
	}
}

```

Please refer to the TurtleTools/Examples/ directory for more example code. The [ReceiveFile.snap](../TurtleTools/Examples/ReceiveFile.snap) program show cases structs, traits, dynamic dispatch, unit tests, and other language features.

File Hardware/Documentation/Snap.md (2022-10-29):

# Introduction

Snap is a statically typed, natively compiled high-level language designed for programming the Turtle16 computer system. The Snap language draws heavy influences from Swift, Rust, Zig, C, and other languages.

# Getting Started

## Building and Installing Snap

To build the Snap command line tool, open the TurtleTools Xcode project, and from the menu select Product > Archive. This will build the simulator app and the tool chain, including the Snap compiler. Select the archive and choose Distribute Content > Build Products. Choose a directory in which to save the build products and click Export. Then, use Finder to drag Simulator16.app into /Applications.

The Snap command line tool is found at Simulator16.app/Contents/Frameworks/Snap so may be run by invoking /Applications/Simulator16.app/Contents/Frameworks/Snap on the command line. You may find it convenient to create a symlink to this tool in a directory in your $PATH.

## Hello, World!

The Snap command line tool can be used to build a program whose binary image may be flashed to to EEPROM and executed on hardware, or executed in the simulator app. The program may also be built and run locally for testing.

```
USAGE:
Snap [test] [options] file...

OPTIONS:
	run        Compile the program and run immediately in a VM.
	test       Compile the program for testing and run immediately in a VM.
	-t <test>  The test suite only runs the specified test
	-h         Display available options
	-o <file>  Specify the output filename
	-S         Output assembly code
	-ir        Output intermediate representation
	-ast-dump  Print the abstract syntax tree to stdout
	-q         Quiet. Do not print progress to stdout
	-O0        Disable optimizations
```

Save this simple Hello, World! program to a text file, hello.snap:
```
puts("Hello, World!\n")
```

Build this with the following command to compile it and produce hello.program:
```
% Snap hello.snap
```

The hello.program binary image may be executed in the simulator app by running the following commands in the debugger command line:
```
load program
reset
continue
```

Please note that while you will be able to see register and memory values changing over time, Simulator support for the serial output device is incomplete and you will not see the words "Hello, World!" appear anywhere. This is a work in progress.

The compiler can build and run the program in a VM which directs serial output to standard out: Run it on the command line like so:
```
% Snap run hello.snap
instruction words used: 646
Hello, World!
cpu is halted
```

# Syntax

## Comments
```
// Comments in Snap are preceded by "//" and end at the newline.
// There are no multi-line comments in Snap.
```

## Variables
```
// Immutable variables are declared with the let keyword.
// It is not necessary to use a semicolon to end a statement
let foo: u8 = 1

// The type annotation may be omitted and the compiler will automatically deduce
// the type.
let bar = 2

// Mutable variables are declared with the var keyword.
var baz = 3
baz = 4

// Variables may be left undefined at time of declaration. In this case, the
// type annotation is necessary.
var qux: [32]bool = undefined
```

## Primitive Types
```
// A variable with a boolean type is declared using bool. Valid values are true
// and false.
var myBool: bool = true
myBool = false

// An unsigned eight-bit integer type is provided.
let myUInt8: u8 = 255

// As is an unsigned sixteen-bit integer type matching the native word size of
// the Turtle16 CPU.
let myUInt16: u16 = 65535

// A signed eight-bit integer type is provided.
let myInt8: i8 = -128

// A signed sixteen-bit integer type is provided.
let myInt16: i16 = -32768

// Integers of larger widths are not yet implemented.
```

## Literals
### Unsigned Integer Literal
```
let a = 128
assert(a is u8)

let b = 40000
assert(b is u16)

// Hexadecimal numbers
let c = 0xabcd

// Binary numbers
let d = 0b101010
```

### Unicode Scalar Literal
```
// Unicode scalar
let a = 'a'
assert(a is u8)
assert(a == 97)

let b = '\n'
assert(b is u8)
assert(b == 10)
```

### Signed Integer Literal
```
let a = -1000
assert(a is i16)
assert(a == -1000)

let b = -1
assert(b is i8)
assert(b == -1)
```

## Operators
Overflow and underflow are well-defined for both signed and unsigned integers to wrap around the range of values for the type. For example, 0-1 is 65535 for a u16 value, and 32767+1 is -32768 for a i16 value.

Signed types are guaranteed to be implemented as twos-complement with well-defined overflow and underflow behavior.

The Snap programming language does not include in-place arithmetic operators such as +=, -=, &c found in other languages such as C. Nor does it support increment and decrement with ++ and -- operators.

### Binary Operators: u16
```
let p: u16 = 0xabab
let q: u16 = 0xcdcd
var a: u16 = undefined
a = p + q  // addition
a = p - q  // subtraction
a = p * q  // multiplication
a = p / q  // division
a = p % q  // modulus
a = p & q  // bitwise and
a = p | q  // bitwise or
a = p ^ q  // bitwise xor

var b: bool = undefined
b = p == q // equal
b = p != q // not equal
b = p > q  // greater than
b = p < q  // less than
b = p >= q // greater than or equal to
b = p <= q // less than or equal to
```

### Binary Operators: u8
```
let p: u8 = 0xab
let q: u8 = 0xcd
var a: u8 = undefined
a = p + q  // addition
a = p - q  // subtraction
a = p * q  // multiplication
a = p / q  // division
a = p % q  // modulus
a = p & q  // bitwise and
a = p | q  // bitwise or
a = p ^ q  // bitwise xor

var b: bool = undefined
b = p == q // equal
b = p != q // not equal
b = p > q  // greater than
b = p < q  // less than
b = p >= q // greater than or equal to
b = p <= q // less than or equal to
```

### Binary Operators: i16
```
let p: i16 = -1000
let q: i16 = -1000
var a: i16 = undefined
a = p + q  // addition
a = p - q  // subtraction
a = p * q  // multiplication
a = p / q  // division
a = p % q  // modulus
a = p & q  // bitwise and
a = p | q  // bitwise or
a = p ^ q  // bitwise xor

var b: bool = undefined
b = p == q // equal
b = p != q // not equal
b = p > q  // greater than
b = p < q  // less than
b = p >= q // greater than or equal to
b = p <= q // less than or equal to
```

### Binary Operators: i8
```
let p: i8 = -1
let q: i8 = -1
var a: i8 = undefined
a = p + q  // addition
a = p - q  // subtraction
a = p * q  // multiplication
a = p / q  // division
a = p % q  // modulus
a = p & q  // bitwise and
a = p | q  // bitwise or
a = p ^ q  // bitwise xor

var b: bool = undefined
b = p == q // equal
b = p != q // not equal
b = p > q  // greater than
b = p < q  // less than
b = p >= q // greater than or equal to
b = p <= q // less than or equal to
```

### Binary Operators: bool
```
let p: bool = true
let q: bool = false
var a: bool = undefined
a = p && q // and (with short-circuiting evaluation)
a = p || q // or  (with short-circuiting evaluation)
a = p == q // equal
a = p != q // not equal
```

### Unary Operators: u16
```
let p: u16 = 0xf0f0
var a: u16 = undefined
a = -p // negation
a = ~p // bitwise negation
```

### Unary Operators: u8
```
let p: u8 = 0xf0
var a: u8 = undefined
a = -p // negation
a = ~p // bitwise negation
```

### Unary Operators: i16
```
let p: i16 = -1000
var a: i16 = undefined
a = -p // negation
a = ~p // bitwise negation
```

### Unary Operators: i8
```
let p: i8 = -1
var a: i8 = undefined
a = -p // negation
a = ~p // bitwise negation
```

### Unary Operators: bool
```
let p: bool = true
var a: bool = undefined
a = !p // not
```

### Unsigned Arithmetic Overflow and Underflow
```
let a: u8 = 255
assert((a+1) == 0)

let b: u8 = 0
assert((b-1) == 255)

let c: u16 = 65535
assert((c+1) == 0)

let d: u16 = 0
assert((d-1) == 65535)
```

### Signed Arithmetic Overflow and Underflow
```
let a: i8 = 127
assert((a+1) == -128)

let b: i8 = -128
assert((b-1) == 127)

let c: i16 = 32767
assert((c+1) == -32768)

let d: i16 = -32768
assert((d-1) == 32767)
```

## Pointers
```
// The unary & operator may be used to produce a pointer.
var a: u16 = 1
let ptr = &a

// Or a pointer may be produced through automatic type conversion. The pointer
// type expression prefixes the pointee type with an asterisk.
var ptr2: *u16 = a

// Rebind the pointer by reassigning it
ptr2 = ptr

// Modify the pointee with using "pointee"
ptr2.pointee = 2

// Use const to create a pointer which cannot be used to mutate the pointee.
// This pointer may itself be mutable.
var ptr3: *const u16 = a
```

There is no pointer arithmetic in the Snap programming language. For example, the following is never permitted.
```
ptr3 = ptr3 + 1 // not valid
```

## Ranges
A range may be declared with special .. syntax. The left number is the beginning and the right is the limit. The limit must be the greater of the two, and both must be a positive u16 value. The range is defined to include all values x where begin <= x < limit. In the following example, the value 1000 is not included in the range. Ranges are commonly used in array slicing and loops.
```
// Declare a range
let range: Range = 0..1000

// It's also possible to get the begin and limit of a range like so
let rangeBegin = range.begin
let rangeLimit = range.limit
```

## Arrays
```
// Define an array with a size determined at compile time
let a = [_]u8{1, 2, 3, 4, 5, 6, 7, 8, 9}
let b = [9]u8{1, 2, 3, 4, 5, 6, 7, 8, 9}

// Copy an array
var c: [9]u8 = a

// Access a single element of an array
let c0 = c[0]
c[0] = 42

// Get the number of elements in an array
let n = a.count

// A string literal is syntax sugar for an [_]u8 array literal where the
// elements of the array are the UTF-8 encoded bytes of the string.
let s0 = "a UTF-8 string is an array of bytes"
let d: u8 = s[0]

// A multiline string literal is also possible
let s1 = """
    a UTF-8 string is an array of bytes
    """
```

Additionally, a string may contain any of several escape sequences:
* '\t' -- Tab character
* '\n' -- Newline
* '\r' -- Carriage return
* '\"' -- Double quote
* '\'' -- Single quote
* '\\' -- Backslash
* '\0' -- Nul character

## Array Slices
```
// An array slice is a pointer and a length determined at runtime. Create a
// slice from an array by subscripting the array with a value of a Range type.
let str = "Hello, World!"
let slice1 = str[0..6] // "Hello,"
let slice2 = slice1[0..5] // "Hello"

// Get the number of elements in a slice
let n = slice2.count
```

## Casting and Conversions
```
// Convert a value to a different type with the as keyword
let a: u8 = 1
let b = a as u16

// Converting an array will copy the array and convert each element individually
let c = [_]u8{1, 2, 3}
let d = c as [_]u16
```

## Automatic type conversions
Some type conversions are automatic.
```
// Automatic conversions in integer arithmetic will convert one side of a binary
// expression to the wider of the two types
let a = 1 + 50000 // a is u16

// Automatic conversions between integer types are only permitted when the
// values representable by the source type is a complete subset of the values
// representable by the destination type.
let b: u8 = 1
let c: i16 = b // permitted because all values of u8 are reprentable in i16

// The address of a value is automatically taken to convert to a pointer.
let d: *u16 = a

// Arrays are automatically converted to array slices
let arr = [_]u8{1, 2, 3}
let slice: []u8 = arr
```

## Unsafe Bitcast
```
// It's occasionally useful to perform an unsafe cast to reinterpret the
// in-memory representation of a value as a different type. For example,
// hardware may provide a memory-mapped register at an particular address and it
// would be useful to have a pointer to that address.
let ptr: *u16 = 0xabcd bitcastAs *u16
```

## Structs
```
// Declare a struct like so
struct Point {
	x: u16,
	y: u16
}

// Declare an instance of a struct
let p1 = Point {
	.x = 1,
	.y = 2
}

// Declare a struct with undefined contents and set the values of members later.
var p2: Point = undefined
p2.x = 1
p2.y = 2

// Declare a struct with some fields left undefined
let p3 = Point { .x = 1 }

// It is not necessary to use a special operator or syntax to access struct
// members through a pointer. Use the standard dot syntax.
let p4: *Point = p2
p4.x = 3
p4.y = 4
```

## Unions and Is
```
// Define a tagged union using the | operator in a type annotation.
let q: u8 | bool = false

// Test the type of a union value at runtime.
assert(!(q is u8))

// Use the "is" keyword to test the type of any other value too.
let p = true
assert(p is bool)
assert(!(p is *bool))
```

## Typealias
```
// Create a type alias to create more convenient names for awkward types.
typealias Foo = u8 | bool
let a: Foo = false
```

## If
```
// If is a statement. Parentheses are not required. The curly braces are always
// required, however.
if 1 + 1 == 2 {
	// then branch
} else {
	// else branch
}
```

## While
```
// While loops don't require parentheses either and also require curly braces.
var i = 0
while i < 10 {
	i = i + 1
}
```

## For
```
// For loops can iterate over the elements of a range
// The curly braces are always required.
let begin = 1
let limit = 3
for i in begin..limit {

}

// They can also iterate over the elements of an array
let arr = [_]u8{1, 2, 3, 4, 5, 6, 7, 8, 9}
for i in arr {

}

// Or of an array slice
for i in arr[0..3] {

}

// C-style for loops are not supported in Snap.
```

## Match
```
// The match statement allows convenient type testing of union values
var r: u8 = 0
var a: u8 | bool = 0
match a {
    (foo: u8) -> {
		r = 1
    },
    (bar: bool) -> {
		r = 2
    }
}
assert(r == 1)
```

## Functions
```
// Create a function with no return value or parameters.
func foo() {
	puts("hello")
}

// Specify the return value with an arrow at the end of the signature.
func bar() -> bool {
	return true
}

// Specify parameters in parentheses with labels and type annotations.
func baz(aa: u8, bb: u16) -> u16 {
	return aa + bb
}

// The labels are not used at the function call site.
let r1 = baz(1, 1000)
assert(r1 == 1001)

// Functions may be nested. These inner functions have access to the enclosing
// lexical scopes.
func qux(aa: u8, bb: u16) -> u16 {
	let c = 1
	func quux(aa: u8) -> u8 {
		return aa + c
	}
	return quux(aa) + bb
}
let r2 = qux(1, 1000)
assert(r2 == 1002)

// Record a function pointer and use the pointer to invoke the function later.
var fnptr: func(u8, u16) -> u16 = undefined
fnptr = &baz
let r3 = fnptr(1, 1)

// Proper closures and lambda expressions are not yet implemented.
```

## Generic Functions
```
// Declare generic functions with type arguments listed in angle brackets
// after the function name.
func myGenericFn[T](a: T) -> T {
	return a
}

// The generic function must be instantiated in order to use it. This may
// require providing explicit concrete types in angle brackets at the call
// site.
let fnptr: func(u8) -> u8 = &myGenericFn@[u8]
let r1 = fnptr(255)
assert(r1 == 255)

// These explicit type arguments can be passed in a Call expression too.
let r2: u16 = myGenericFn@[u16](1000)
assert(r2 == 1000)

// The compiler is able to infer the type arguments from context in a Call
// expression in many situations.
let r3: i16 = myGenericFn(-1000)
assert(r3 == -1000)

// Generic functions which are never instantiated are never compiled at all.
// Compiler errors in these unused functions will never be detected.
// This is a work-in-progress and there are plans to allow the type
// arguments of a generic function to include trait-based constraints so
// that it is possible to type check the function before instantiation time.
func myGenericFn2[T](a: T) -> T {
	blah // This actually will NOT cause a compile error right now.
}
```

## Struct Methods
```
struct Point {
	x: u16,
	y: u16
}

// It is possible to add methods to a struct type using the "impl" keyword.
// These are added to the namespace of the struct itself.
impl Point {
	func add(p1: *Point, p2: *Point) -> Point {
		return Point {
			.x = p1.x + p2.x,
			.y = p1.y + p2.y
		}
	}
}

// Possibly across more than one impl block.
impl Point {
	func sub(p1: *Point, p2: *Point) -> Point {
		return Point {
			.x = p1.x - p2.x,
			.y = p1.y - p2.y
		}
	}
}

let p1 = Point { .x = 1, .y = 1 }
let p2 = Point { .x = 1, .y = 1 }
let p3 = Point.add(p1, p2)
let p4 = Point.sub(p1, p2)
```

## Traits
A trait defines an abstract protocol or interface for interacting with a struct type. Currently, traits provide dynamic dispatch through a vtable. In the future, the compiler will use traits as constraints on generic type parameters.

The first parameter of each function in the interface may optionally be a pointer to the trait type. In this case, a conforming implementation method is one that has a type that's either a pointer to the trait type or has a type that's a pointer to the concrete struct instance.

TODO: This is confusing. The compiler should be changed to use a special Self keyword as a placeholder in this case.
```
// Define a trait and the collection of functions that make up its interface.
trait Serial {
	func write(self: *Serial, bytes: []u8)
	func read(self: *Serial) -> []u8
}
```

Any struct may implement a trait by defining an impl-for block with definitions of required methods.
```
struct SerialFake {
	cannedData: []u8
}

impl Serial for SerialFake {
	func write(self: *SerialFake, bytes: []u8) {
		puts(bytes)
	}

	func read(self: *SerialFake) -> []u8 {
		return self.cannedData
	}
}
```

Trait objects have their own set of rules about automatic type conversions. A concrete struct conforming to a trait may be seamlessly and automatically converted to the representing trait object.
```
let concreteObject = SerialFake {}
let traitObject: Serial = concreteObject
```

It is possible to declare a Generic Trait. This defines defines a template for an interface. The actual, concrete interface depends on type arguments which have yet to be specified.
```
trait Adder[T] {
    func add(self: *Adder@[T], amount: T) -> T
}
```

Instantiate a concrete instance of the generic trait with the @[] syntax for a generic type application. Here, MyAdder@[T] promises conforms to the trait Serial@[T] when instantiated with a concrete type "T".
```
struct MyAdder[T] {
    val: T
}

impl[T] Adder@[T] for MyAdder@[T] {
    func add(self: *MyAdder@[T], amount: T) -> T {
        self.val = self.val + amount
        return self.val
    }
}
```

There's no type argument deduction for generic traits. (TODO: yet) The program must explicitly specify a conforming concrete trait in an expression to convert to a trait object.
```
var myAdder = MyAdder@[u16] { .val = 41 }
let adder: Adder@[u16] = &myAdder
let a = adder.add(1)
assert(a == 42)
```

## Modules and Import
Code may be written across multiple source files. Use the import keyword to instruct the compiler to import another source file as a module. Public symbols found in the module are imported into the global namespace. Private symbols (the default) are not imported.
```
// Import a module defined in a file named MyModule.snap
import MyModule

// Mark a variable as public
public let myVariable = 0xabcd

// Mark a type as public
public struct MyStruct {

}

// Mark a function as public
public func foo() {

}

// It's possible to mark a symbol as private too.
// This is not often necesary as private is the default.
private let myPrivateVar = 0xbeef
```

## Assert
The assert statement asserts that an expression evaluates to true. If at runtime, the expression does not evaluate to true then the program halts with an appropriate diagnostic message.
```
assert(1 + 1 == 2) // passes
assert(2 + 2 == 5) // trips the assert
```

## Test Declarations
Unit tests may be declared using the test keyword. These tests are executed when invoking the compiler with the "test" verb. In this mode, a failed assertion produces a diagnostic message and halts the test.

A program always executes the statements in the top-level body of the main source file and then executes either the testMain() or main() function. The main() function is optional and may be omitted. The testMain() function is automatically generated by the compiler and contains the test suite runner.
```
// Declare a unit test.
test "A test name goes here" {
	assert(1 + 1 == 2)
}

// Declare a main function to execute when not running tests.
func main() {
	puts("not running for testing right now\n")
}
```

## Compiler Intrinsics
```
// Halt execution immediately
hlt()
```

## Runtime support
The `None` type is an empty placeholder that may be used in a union to form a sort of optional type. The value `none` has this type.
```
import stdlib

var maybeSerial: Serial | None = none

match maybeSerial {
    (serial: Serial) -> {
		// something
    },
    (none: None) -> {
		// something else
    }
} 
```

Put a single byte from an UTF-8 encoded string to the output device.
```
func putc(c: u8)
```

Put a a UTF-8 encoded string to the output device.
```
func puts(s: []const u8)
```

Print the specified diagnostic message and terminate the program.
```
func panic(message: []const u8)
```

It's possible to directly insert assembly code into the compiled program too. (inline assembly) This is an escape hatch which allows interacting with hardware features which are not readily exposed in the Snap programming language.
```
asm("NOP")
```

Use sizeof() to determine the size of an object. This accepts and expression. The type of the expression is evaluated and sizeof() evaluates to the size of that type.
```
let sizeOfU8 = sizeof(u8)
assert(sizeOfU8 == 1)

let sizeOfVar = sizeof(sizeOfU8)
assert(sizeOfVar == 1)

let sizeOfString = sizeof("test")
assert(sizeOfString == 4)
```

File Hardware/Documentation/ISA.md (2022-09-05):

# Turtle16 ISA

This document describes the Instruction Set Architecture of the Turtle16 CPU, a sixteen-bit RISC CPU with eight general-purpose registers. The CPU has been designed to avoid delay slots, a classic RISC pitfall.

## Opcodes

The ID stage uses a ROM to decode a five-bit opcode into an array of control signals. The opcodes are as follows.

0. nop
1. hlt
2. load
3. store
4. li
5. lui
6. cmp
7. add
8. sub
9. and
10. or
11. xor
12. not
13. cmpi
14. addi
15. subi
16. andi
17. ori
18. xori
19. *unused*
20. jmp
21. jr
22. jalr
23. *unused*
24. beq
25. bne
26. blt
27. bgt
28. bltu
29. bgtu
30. adc
31. sbc

## Condition Codes

The CPU uses an internal register to record four condition codes, used in conditional instructions BEQ, BNE, BLT, BGT, BLTU, BGTU, ADC, and SBC. The condition codes are...
* C -- Carry. The ALU computation cannot fit in the result and carries out a bit.
* Z -- Zero. The result is zero.
* V -- Overflow. The ALU computation results in twos complement signed overflow.
* N -- Negative. The most significant bit of the result is set.

## Instruction Encoding

At the top-level instructions have the following forms...

Format | Encoding scheme
------ | ---------------
RRR    | `0bkkkk'kccc'aaab'bbxx`
RRI    | `0bkkkk'kccc'aaai'iiii`
RII    | `0bkkkk'kccc'iiii'iiii`
XRI    | `0bkkkk'kxxx'aaai'iiii`
IRR    | `0bkkkk'kiii'aaab'bbii`
III    | `0bkkkk'kiii'iiii'iiii`
X      | `0bkkkk'kxxx'xxxx'xxxx`

where 'k' is a 5-bit opcode, 'c' is the index of the register to select in the write back stage, 'a' is the index of the register to select for the ALU left operand, 'b' is the index of the register to select for the ALU right operand, and 'i' is an immediate value.

More generally, there is a field for an opcode and the fields for a, b, and c. Some instructions are able to use unused bits from the latter three fields to form an immediate value. The final two bits may also contribute to an immediate value.

### NOP (X-format)

The NOP instruction specifically has all zero instruction bits. The decoded control signals do not assert any control signals at all. The instruction does nothing.

### HLT (X-format)

The HLT instruction halts the CPU clock. There will be a button to resume execution.

### LOAD (RRI-format)

`0bkkkk'kccc'aaai'iiii`

Loads a sixteen-bit word from memory at the address given by Ra + Imm and writes that value to the register Rc.

```
Rc := mem[Ra + Imm]
```

### STORE (IRR-format)

`0bkkkk'kiii'aaab'bbii`

Stores the contents of the register Rb to memory at the address given by Ra + Imm.

```
mem[Ra + Imm] := Rb
```

### LI (RII-format)

`0bkkkk'kccc'iiii'iiii`

Takes the immediate value, sign-extends it from eight to sixteen bits, and writes it to the register Rc.

```
Rc := Imm
```

### LUI (RII-format)

`0bkkkk'kccc'iiii'iiii`

Takes the immediate value, shifts it left by eight, and writes it to the upper eight bits of the register Rc. (The lower eight bits are unchanged.)

```
Rc[8:15] := Imm
```

### ALU instructions (RRR-format and RRI-format)

The ALU operands are selected by an array of multiplexer circuitry.

The Store Operand may be one of the following...
1. Rb
2. PC + 1
3. Eight-bit immediate value
4. (Eight-bit immediate value) << 8

The Right Operand may be one of the following...
1. Rb
2. The five-bit immediate value, ins[4:0]
3. The five-bit immediate value, ins[10:8, 1:0]
4. The eight-bit immediate value, ins[10:0]

The Left Operand is always Ra.

The instruction decode stage provides control signals to choose the ALU function and set the carry input. The result feeds back to the program counter as well as feeding into the ALU result interstage register. Condition codes produced by the ALU go into an internal flags register and may be latched if the appropriate control signal is asserted.

### JMP (III-format)

`0bkkkk'kiii'iiii'iiii`

Perform an unconditional pc-relative jump by the eleven-bit offset given in Imm:

```
NPC := PC + Imm
```

### JR (XRI-format)

`0bkkkk'k000'aaai'iiii`

Perform an unconditional absolute jump, computing Ra + Imm and setting PC to the result:

```
NPC := Ra + Imm
```

### JALR (RRI-format)

`0bkkkk'kccc'aaai'iiii`

Perform an unconditional absolute jump, computing Ra + Imm and setting PC to the result. Store the return address in the register Rc.

```
NPC := Ra + Imm
Rc := PC+1
```
	
As this instruction uses a five-bit immediate value, it is expected that most procedure calls will involve a couple of instructions to fill a register with the absolute jump target. The five-bit immediate value is so small that it isn't even expected to be particularly useful, but that removing it entirely is more complicated than leaving it in.

### BEQ (III-format)

`0bkkkk'kiii'iiii'iiii`

Perform a conditional pc-relative jump when Z==1:

```
NPC := PC + Imm
```

### BNE (III-format)

`0bkkkk'kiii'iiii'iiii`

Perform a conditional pc-relative jump when Z==0:

```
NPC := PC + Imm
```

### BLT (III-format)

`0bkkkk'kiii'iiii'iiii`

Perform a conditional pc-relative jump when N!=V, performing a signed less-than comparison:

```
NPC := PC + Imm
```

### BGT (III-format)

`0bkkkk'kiii'iiii'iiii`

Perform a conditional pc-relative jump when (Z==0) && (N==V), performing a signed greater-than comparison:

```
NPC := PC + Imm
```

### BLTU (III-format)

`0bkkkk'kiii'iiii'iiii`

Perform a conditional pc-relative jump when C==0, performing an unsigned less-than comparison:

```
NPC := PC + Imm
```

### BGTU (III-format)

`0bkkkk'kiii'iiii'iiii`

Perform a conditional pc-relative jump when C==1 && Z==0, performing an unsigned greater-than comparison:

```
NPC := PC + Imm
```

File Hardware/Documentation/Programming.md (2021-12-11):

# Turtle16: Programming the EEPROMs and GALs

There are three EEPROMs used for decoding instructions in the ID stage, two EEPROMs containing instruction memory for the IF stage, and two ATF22V10 GALs used in the Hazard Control unit.

Flash the contents of the EEPROMs using `minipro` like so:
```
% minipro -p 'SST39SF010A@PLCC32' -y -w contents.bin
```

Ideally, you could also program the GALs using `minipro` on Mac and Linux. Unfortunately, I've only ever been able to program an ATF22V10 with Xgpro on Windows.

## Which chips?

* Instruction Memory (Lower eight bits) --> U57
* Instruction Memory (Upper eight bits) --> U58
* OpcodeDecodeROM1.bin --> U37
* OpcodeDecodeROM2.bin --> U38
* OpcodeDecodeROM3.bin --> U39
* HazardControl1.jed --> U51
* HazardControl2.jed --> U52

## Using what firmware?

The contents of the decoder EEPROMs are included in the repo under the Generated/ directory. Ditto the .jed files for the Hazard Control GALs.

Alternatively, use the Simulator16 app to dump the contents of the simulated computer's EEPROMs to file.

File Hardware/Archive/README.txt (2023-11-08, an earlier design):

This is a collection of products archived for each PCB I've had manufactured.

So, this will include the exact Gerbers that I submitted to the PCB board house for each revision, a snapshot of the corresponding KiCad projects at that point in time, associated firmware, BOM, and other material.

I may remove articles from the archive as they lose relevance. For example, old revisions of PCBs may not be kept around if development has long since moved beyond them.

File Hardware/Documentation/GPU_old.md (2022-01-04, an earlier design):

# Crush, a GPU for Turtle16

## Specifications

Crush is a CPU designed for graphics applications and so will also be referred to as a GPU in this document. It has thirty-two sixteen-bit general purpose registers, a six stage pipeline, and a separate 64K address space for instruction memory and RAM.

An additional 64K address space is available for RAM which is shared with the controlling CPU. This is accessed with a separate set of load/store instructions. Fast copies between address spaces are possible with a special blit instruction.

The pipeline implements fine-grained multithreading. Each clock the CPU will switch to a different hardware thread, maintaining a separate register file and program counter per thread. This avoids the need for hardware interlocks and pipeline hazard control. There are no stalls. Branch prediction and branch delay slots are not necessary in this scheme. Since the register file is built from an SRAM, this may be implemented by putting the Thread ID into the upper bits of the memory's address input.

A memory-mapped control register will allow the controlling CPU to set the number of threads to execute, with a special value of zero meaning that the entire GPU is to be halted. Typically, the CPU will operate with a number of threads equal to the number of tiles in the frame buffer.

The CPU has special address decoding hardware in the MEM stage to allow each thread to retrieve it's Thread ID from a special memory-mapped register.

A RAMDAC reads the RAM simultaneously with the GPU in order to generate the video signal. It swaps between two 200x150 (30,000 words) frame buffers. This leaves 5,536 words which may be used by the GPU for memory-mapped registers and working memory.

The EX includes a 16-bit ALU for basic arithmetic operations, and also a barrel shifter for performing a logical bit shift in one clock cycle.

## Pipeline

1. IF -- Instruction Fetch
2. ID -- Instruction Decode
3. EX -- Execute
4. MEMA -- Access the first address space, shared with CPU
5. MEMB -- Access the second address space, shared with RAMDAC
6. WB -- Write back

### Intruction Formats

Instructions may take one of the following formats:

Format | Encoding scheme
------ | ---------------
RR     | `0bkkkk'kkaa'aaab'bbbb`
RI     | `0bkkkk'kkaa'aaai'iiii`
I      | `0bkkkk'kkii'iiii'iiii`

The `k' field is a always a six-bit opcode. The `a' field is both the register to use in the right operand and an implied destination register. The `b' field indicates a register to use as the left operand. Otherwise, the RI format replaces the `b' field with a 5-bit opcode. The I format replaces both the `a' and `b' fields with a 10-bit immediate field.

### Opcodes

0. nop
1. hlt
2. lw
3. sw
4. lw2
5. sw2
6. bitblt
7. li
8. li10
9. mov
10. cmp
11. add
12. sub
13. and
14. or
16. xor
17. lsl
18. lsr
19. not
20. cmpi
21. addi
22. subi
23. andi
24. ori
25. xori
26. lsli
27. lsri
28. jmp
29. jr
30. jalr
31. beq / bz
32. bne / bnz
33. blt
34. bge
35. ble
36. bgt
37. bltu
38. bgeu
39. bleu
40. bgtu

Remaining opcodes are reserved for future expansion.

#### NOP (X-format)

The NOP instruction does nothing.

#### HLT (X-format)

The HLT instruction halts the CPU clock. There will be a button to resume execution.

#### LW (RR-format)

`0bkkkk'kkaa'aaab'bbbb`

Loads a sixteen-bit word from memory address space A at the address given by Rb and writes that value to the register Ra.

```
Ra := mem[Rb]
```

#### SW (RR-format)

`0bkkkk'kkaa'aaab'bbbb`

Stores the contents of the register Rb to memory in memory address space B at the address given by Ra.

```
mem[Ra] := Rb
```

#### LW2 (RR-format)

`0bkkkk'kkaa'aaab'bbbb`

Loads a sixteen-bit word from memory address space B at the address given by Rb and writes that value to the register Ra.

```
Ra := mem[Rb]
```

#### SW2 (RR-format)

`0bkkkk'kkaa'aaab'bbbb`

Stores the contents of the register Rb to memory in memory address space B at the address given by Ra.

```
mem[Ra] := Rb
```

#### BITBLT (RR-format)

`0bkkkk'kkaa'aaab'bbbb`

Reads a value from memory address A at the address given by Rb. If the Alpha bit is set then the value us stored to memory address space B at the address given by Ra. This permits the GPU to implement a simple form of transparency.

```
mem[Ra] := Rb
```

#### LI (RI-format)

`0bkkkk'kkaa'aaai'iiii`

Takes the immediate value, sign-extends it to sixteen bits, and writes it to the register Ra.

```
Rc := Imm
```

#### LI10 (I-format)

`0bkkkk'kkii'iiii'iiii`

Takes the 10-bit immediate value, sign-extends it to sixteen bits, and writes it to the register r0.

```
r0 := Imm
```

#### MOV (RR-format)

`0bkkkk'kkaa'aaab'bbbb`

Copies the value of register Rb to register Ra.

```
Ra := Rb
```

#### ALU instructions (RR-format and RI-format)

The ALU operands are selected by an array of multiplexer circuitry.

The Store Operand may be one of the following...
1. Rb
2. PC + 1
3. 5-bit immediate value, sign-extended
4. 10-bit immediate value, sign-extended

The Right Operand may be one of the following...
1. Rb
2. The 5-bit immediate value, sign-extended
3. 10-bit immediate value, sign-extended

The Left Operand is always Ra.

The instruction decode stage provides control signals to choose the ALU function and set the carry input. The result feeds back to the program counter as well as feeding into the ALU result interstage register. Condition codes produced by the ALU go into a flags register and may be latched if the appropriate control signal is asserted.

#### JMP (I-format)

`0bkkkk'kkii'iiii'iiii`

Perform an unconditional pc-relative jump by the 10-bit offset given in Imm:

```
NPC := PC + Imm
```

#### JR (RI-format)

`0bkkkk'kkaa'aaai'iiii`

Perform an unconditional absolute jump, computing Ra + Imm and setting PC to the result:

```
NPC := Ra + Imm
```

#### JALR (RR-format)

`0bkkkk'kkaa'aaab'bbbb`

Perform an unconditional absolute jump, computing Rb + Imm and setting PC to the result. Store the return address in the register Ra.

```
NPC := Rb
Ra := PC+1
```

#### BEQ (I-format)

`0bkkkk'kkii'iiii'iiii`

Perform a conditional pc-relative jump when the Z flag is set:

```
NPC := PC + Imm
```

#### BNE (III-format)

`0bkkkk'kkii'iiii'iiii`

Perform a conditional pc-relative jump when the Z flag is not set:

```
NPC := PC + Imm
```

#### BLT (III-format)

`0bkkkk'kkii'iiii'iiii`

Perform a conditional pc-relative jump when the OVF flag is set, performing a signed less-than comparison:

```
NPC := PC + Imm
```

#### BGE (III-format)

`0bkkkk'kkii'iiii'iiii`

Perform a conditional pc-relative jump when the OVF flag is not set, performing a signed greater-than-or-equal-to comparison:

```
NPC := PC + Imm
```

#### BLTE (III-format)

`0bkkkk'kkii'iiii'iiii`

Perform a conditional pc-relative jump when ?, performing a signed less-than-or-equal-to comparison:

```
NPC := PC + Imm
```

#### BGT (III-format)

`0bkkkk'kkii'iiii'iiii`

Perform a conditional pc-relative jump when ?, performing a signed greater-than comparison:

```
NPC := PC + Imm
```

#### BLTU (III-format)

`0bkkkk'kkii'iiii'iiii`

Perform a conditional pc-relative jump when the Carry flag is set, performing an unsigned less-than comparison:

```
NPC := PC + Imm
```

#### BGEU (III-format)

`0bkkkk'kkii'iiii'iiii`

Perform a conditional pc-relative jump when the Carry flag is not set, performing an unsigned greater-than-or-equal-to comparison:

```
NPC := PC + Imm
```

#### BLTEU (III-format)

`0bkkkk'kkii'iiii'iiii`

Perform a conditional pc-relative jump when ?, performing an unsigned less-than-or-equal-to comparison:

```
NPC := PC + Imm
```

#### BGTU (III-format)

`0bkkkk'kkii'iiii'iiii`

Perform a conditional pc-relative jump when ?, performing an unsigned greater-than comparison:

```
NPC := PC + Imm
```

### Render Kernel

The general algorithm for rendering a tile is as follows. This assumes all sprites are 16x16 so we don’t need to consider the overhead of a dynamic loop or loading the width from memory. Also, the number of virtual sprites is fixed at compile time.

```
struct Sprite {
    srcX: u16
    srcY: u16
    dstX: u16
    dstY: u16
    width: u16
    height: u16
}

let spriteList: [numSprites ; Sprite]
let rasterY: Int = gThreadID

while true {
	for i in 0..kNumberOfSprites {
		// If the sprite overlaps the raster row that we're working on then copy one row of it now. The frame buffer is 256x256, all positions are in [0, 255] and sprites always wrap around the edge of the left and right edge of the frame buffer. We can hide this wrap around by setting some scroll registers on the RAMDAC.
		let srcY = spriteList[i].srcY
		var height = spriteList[i].height
		let y = srcY - rasterY
  	if y > 0 && y < height {
	    let srcX = spriteList[i].srcX
	    let dstX = spriteList[i].dstX
	    let dstY = spriteList[i].dstY
	    var width = spriteList[i].width
	    while height > 0 {
	    	let srcUpper = (srcY + height) << 8
	    	let dstUpper = (dstY + height) << 8
	      while width > 0 {
	        let src: *u16 = srcUpper | (srcX + width)
	        let dst: *u16 = dstUpper | (dstX + width)
	        bitblit(dst, src)
	        width -= 1
	      }
	      height -= 1
	    }
	} // for

	if rasterY == kFrameBufferHeight-1 {
		flipPage()
	} else {
		waitForPageFlip()
	}
} // while true
```

Manually compiling to assembly code, using readable names instead of register names:
```
# let rasterY: Int = gThreadID
LI10 r0, &gThreadID
LOAD tid, r0

LI10 r0, &gCurrentPage
LOAD currentPage, r0

# while true {
MainLoop:

# for i in 0..kNumberOfSprites {
LI10 r0, &spriteList
MOV spriteAddr, r0
SpriteLoop:
LI10 i, kNumberOfSprites

# let srcY = spriteList[i].srcY

LOAD srcY, spriteAddr

		var height = spriteList[i].height
		let y = srcY - rasterY
  	if y > 0 && y < height {
	    let srcX = spriteList[i].srcX
	    let dstX = spriteList[i].dstX
	    let dstY = spriteList[i].dstY
	    var width = spriteList[i].width
	    while height > 0 {
	    	let srcUpper = (srcY + height) << 8
	    	let dstUpper = (dstY + height) << 8
	      while width > 0 {
	        let src: *u16 = srcUpper | (srcX + width)
	        let dst: *u16 = dstUpper | (dstX + width)
	        bitblit(dst, src)
	        width -= 1
	      }
	      height -= 1
	    }

# } // for
ADDI spriteAddr, sizeof(Sprite)
SUBI i, 1
BNZ SpriteLoop

# if rasterY == kFrameBufferHeight-1 {
LI10 r0, kFrameBufferHeight-1
CMP rasterY, r0
BNZ WaitForPageFlip
# Flip the page
LI10 r0, &gCurrentPage
LOAD currentPage, r0
XOR currentPage, 1 # Toggle the LSB to swap the page
STORE r0, currentPage
JMP endIf
WaitForPageFlip:
LI10 r0, &gCurrentPage
LOAD nextPage, r0
CMP currentPage, nextPage
BEQ WaitForPageFlip
endIf:

# } // while true
JMP MainLoop
```

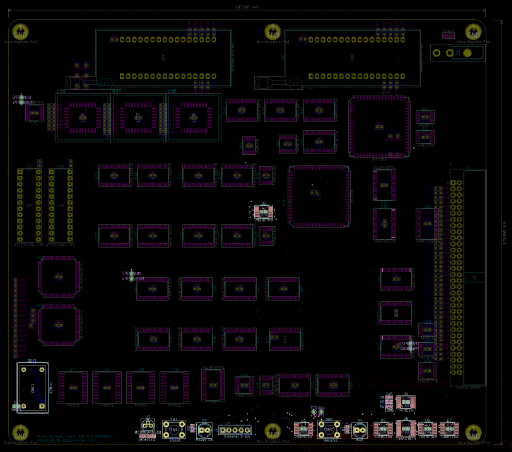
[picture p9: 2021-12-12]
Hardware/Documentation/CPU PCB Modules.pxd/QuickLook/Thumbnail.tiff

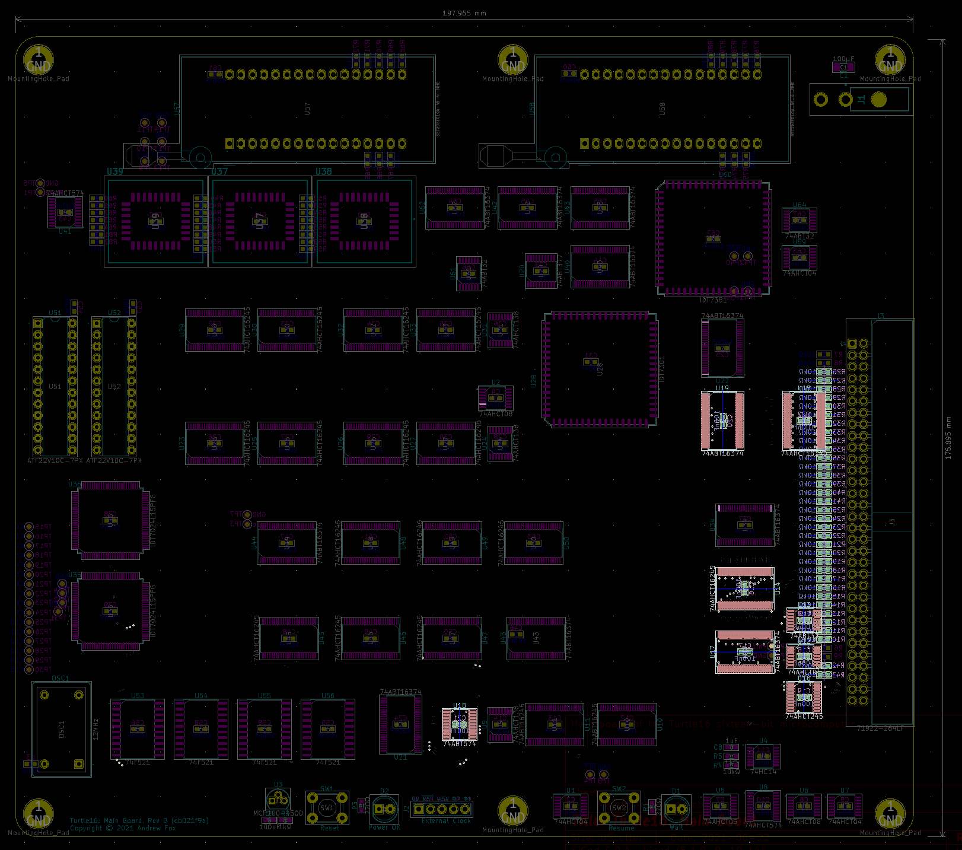
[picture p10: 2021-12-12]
Hardware/Documentation/MEM.png

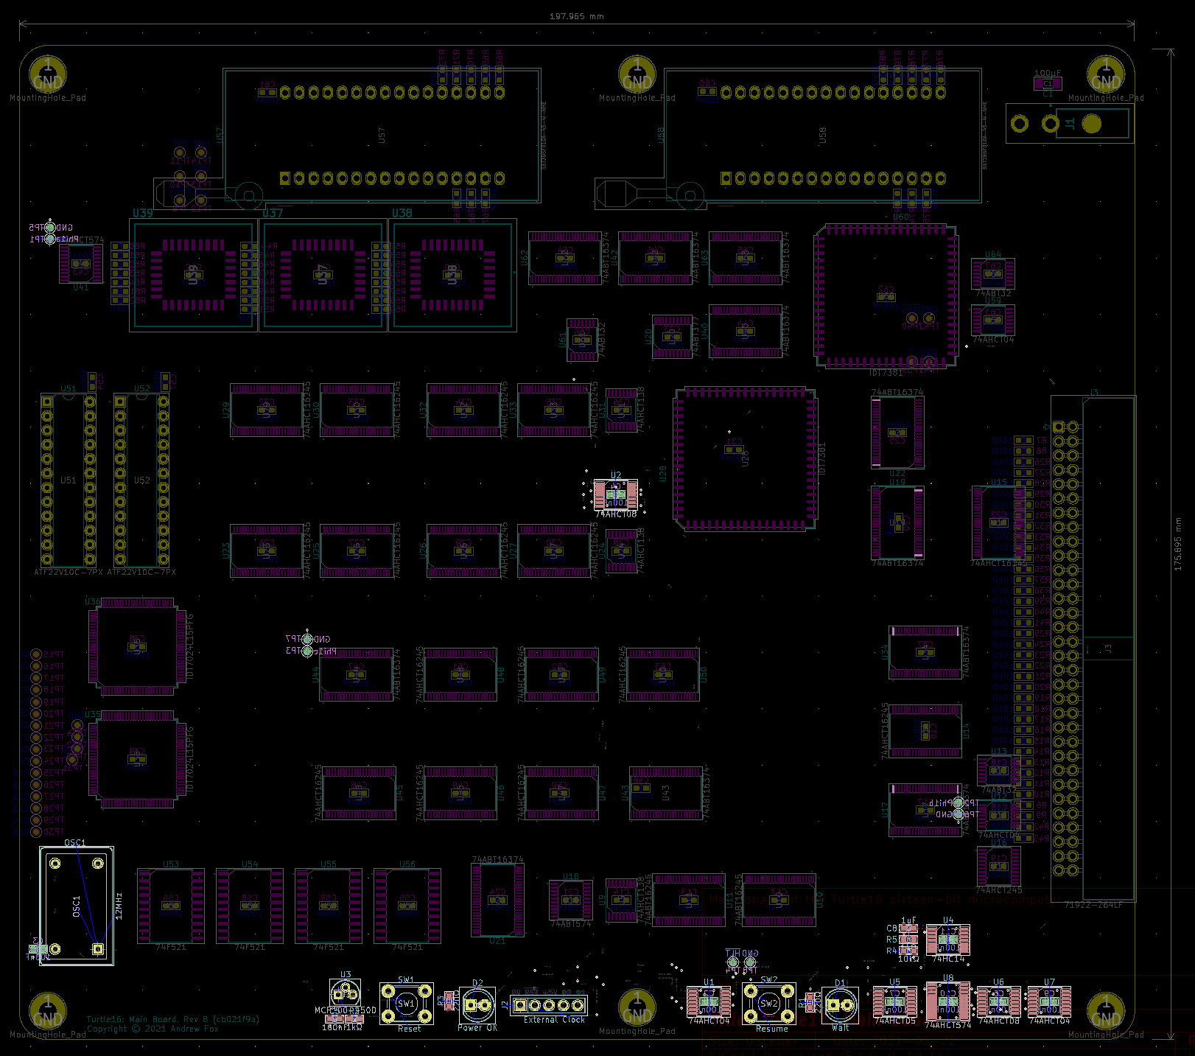
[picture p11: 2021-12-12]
Hardware/Documentation/Clock.png

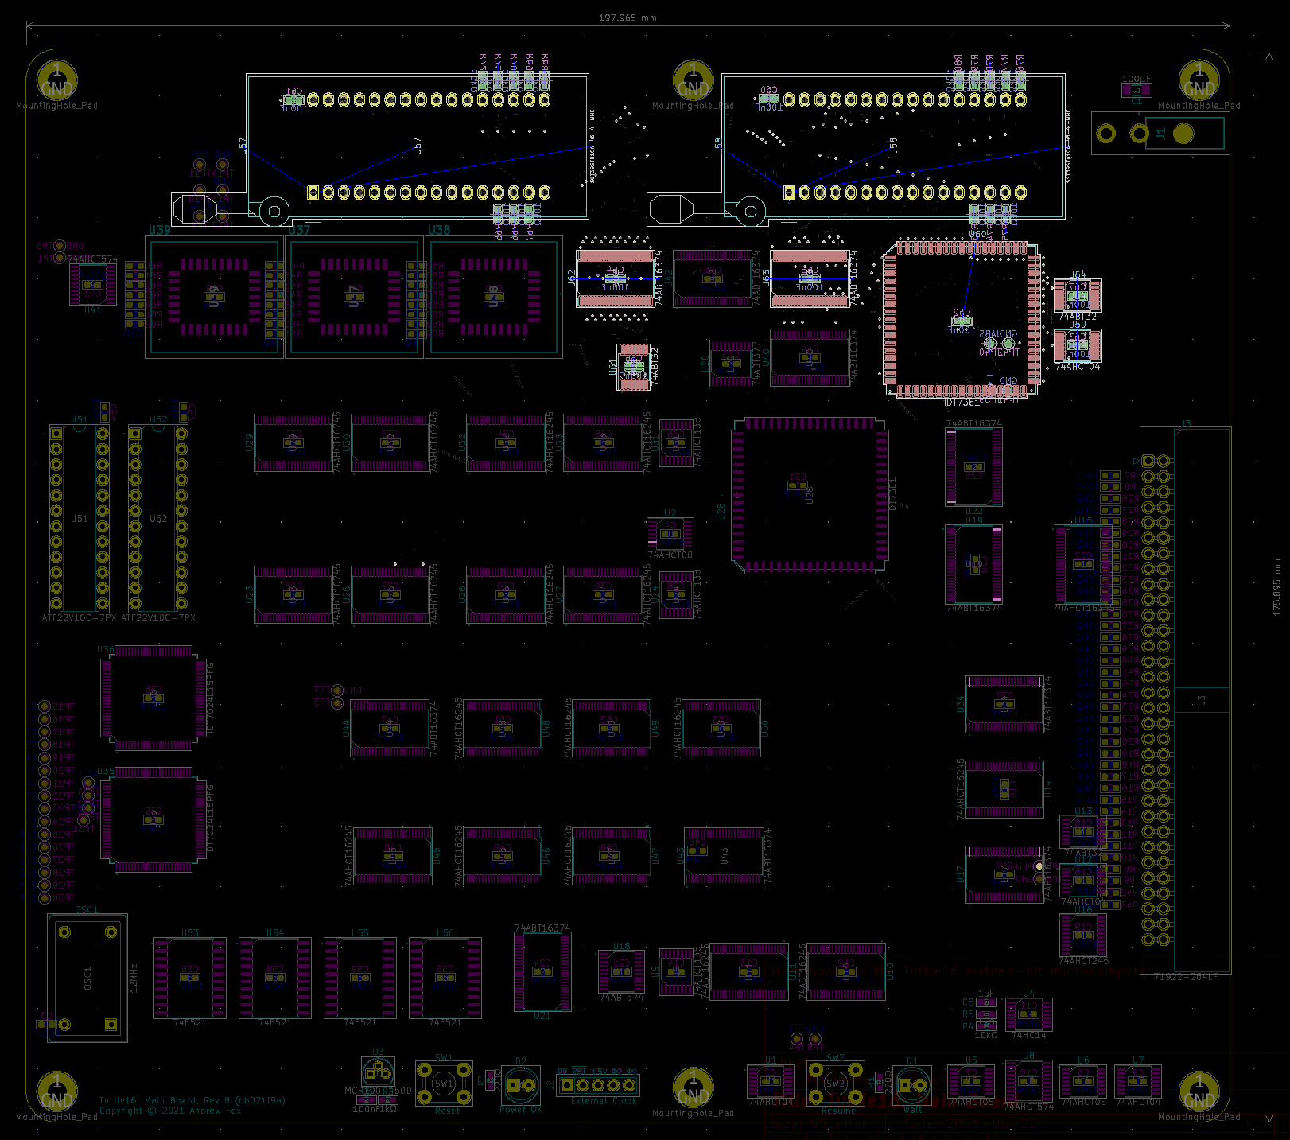
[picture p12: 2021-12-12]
Hardware/Documentation/IF.png

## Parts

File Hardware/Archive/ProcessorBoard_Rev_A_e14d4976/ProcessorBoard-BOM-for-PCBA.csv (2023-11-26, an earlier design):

ProcessorBoard
Qty | Reference(s) | Value | Footprint | Datasheet | Manufacturer | Manufacturer# | Mouser# | Digikey# | Comment
1 | C1 | 100uF | Capacitor_SMD:C_1206_3216Metric | https://www.yuden.co.jp/productdata/catalog/mlcc06_e.pdf | Taiyo Yuden | AMK316ABJ107ML-T | 963-AMK316ABJ107ML-T | 587-AMK316ABJ107ML-TCT-ND | May be replaced by any equivalent capacitor. 20% tolerance. 25V
64 | C2, C3, C4, C5, C6, C7, C8, C9, C10, C11, C12, C13, C14, C15, C16, C17, C18, C19, C20, C21, C22, C23, C26, C27, C28, C29, C30, C31, C32, C33, C34, C35, C36, C37, C38, C39, C40, C41, C42, C43, C45, C46, C47, C48, C49, C50, C51, C52, C53, C54, C56, C57, C58, C59, C60, C61, C62, C63, C64, C65 | 0.1uF | Capacitor_SMD:C_0603_1608Metric | https://www.mouser.com/datasheet/2/396/taiyo_yuden_12132018_mlcc11_hq_e-1510082.pdf | Taiyo Yuden | EMK107B7104KAHT | 963-EMK107B7104KAHT | 587-6004-1-ND | May be replaced by any equivalent capacitor. 20% tolerance. 25V
53 | R1, R2, R3, R4, R5, R6, R7, R8, R9, R10, R11, R12, R13, R14, R15, R16, R17, R18, R19, R20, R21, R22, R23, R24, R25, R26, R27, R28, R29, R30, R31, R32, R33, R34, R35, R36, R37, R38, R39, R41, R42, R44, R45, R46, R47, R48, R49, R50, R51, R52, R53, R54, R55 | 10K | Resistor_SMD:R_0603_1608Metric | https://www.mouser.com/datasheet/2/54/cr-1858361.pdf | Bourns | CR0603-FX-1002ELF | 652-CR0603FX-1002ELF | CR0603-FX-1002ELFCT-N | May be replaced by any equivalent resistor. 10% tolerance
2 | R40, R43 | 1K | Resistor_SMD:R_0603_1608Metric | https://www.mouser.com/datasheet/2/54/cr-1858361.pdf | Bourns | CR0603-FX-1002ELF | 652-CR0603FX-1002ELF | CR0603-FX-1002ELFCT-ND | May be replaced by any equivalent resistor. 10% tolerance
3 | U1, U5, U7 | 74ABT245 | Package_SO:TSSOP-20_4.4x6.5mm_P0.65mm | https://www.ti.com/general/docs/suppproductinfo.tsp?distId=26&gotoUrl=https://www.ti.com/lit/gpn/sn74abt245b | Texas Instruments | SN74ABT245BPWR | 595-SN74ABT245BPWR | 296-3971-1-ND
20 | U2, U3, U6, U8, U25, U26, U31, U32, U34, U35, U36, U38, U39, U40, U45, U46, U47, U48, U49, U50 | 74ABT16245 | Package_SO:TSSOP-48_6.1x12.5mm_P0.5mm | https://www.ti.com/general/docs/suppproductinfo.tsp?distId=26&gotoUrl=https://www.ti.com/lit/gpn/sn74abth16245 | Texas Instruments | SN74ABTH16245DGGR | 595-SNABTH16245DGGR | 296-4124-1-ND
2 | U4, U22 | 74ABT574 | Package_SO:TSSOP-20_4.4x6.5mm_P0.65mm | https://www.ti.com/general/docs/suppproductinfo.tsp?distId=26&gotoUrl=https://www.ti.com/lit/gpn/sn74abt574a | Texas Instruments | SN74ABT574APW | 595-SN74ABT574APW | 296-33631-5-ND
11 | U9, U10, U20, U21, U42, U43, U44, U55, U56, U57, U58 | 74ABT16374 | Package_SO:TSSOP-48_6.1x12.5mm_P0.5mm | https://www.ti.com/general/docs/suppproductinfo.tsp?distId=26&gotoUrl=https://www.ti.com/lit/gpn/sn74abt16374a | Texas Instruments | SN74ABT16374ADGGR | 595-SNABT16374ADGGR | 296-3900-1-ND
4 | U16, U17, U18, U19 | 74F521 | Package_SO:SOIC-20W_7.5x12.8mm_P1.27mm | https://www.ti.com/general/docs/suppproductinfo.tsp?distId=26&gotoUrl=https://www.ti.com/lit/gpn/sn74f521 | Texas Instruments | SN74F521DWR | 595-SN74F521DWR | 296-14819-1-ND
1 | U23 | 74AHCT245 | Package_SO:TSSOP-20_4.4x6.5mm_P0.65mm | https://www.ti.com/general/docs/suppproductinfo.tsp?distId=26&gotoUrl=https://www.ti.com/lit/gpn/sn74ahct245 | Texas Instruments | SN74AHCT245PWR | 595-SN74AHCT245PWR | 296-1118-1-ND
3 | U24, U33, U37 | 74AHCT138 | Package_SO:TSSOP-16_4.4x5mm_P0.65mm | https://www.ti.com/general/docs/suppproductinfo.tsp?distId=26&gotoUrl=https://www.ti.com/lit/gpn/sn74ahct138 | Texas Instruments | SN74AHCT138PWR | 595-SN74AHCT138PWR | 296-1109-1-ND
4 | U27, U51, U54, U59 | 74ABT32 | Package_SO:TSSOP-14_4.4x5mm_P0.65mm | https://www.mouser.com/datasheet/2/916/74ABT32-2937354.pdf | Nexperia | 74ABT32PW,118 | 771-ABT32PW118 | 1727-6509-1-ND
1 | U30 | 74ABT377 | Package_SO:TSSOP-20_4.4x6.5mm_P0.65mm | https://www.ti.com/general/docs/suppproductinfo.tsp?distId=26&gotoUrl=https://www.ti.com/lit/gpn/sn74abt377a | Texas Instruments | SN74ABT377APWR | 595-SN74ABT377APWR | 296-4011-1-ND
2 | U41, U53 | IDT7381 | Package_LCC:PLCC-68_SMD-Socket | https://www.mouser.com/datasheet/2/1/62074255ead63bd7ee299038194cccf20f500ef4-2950939.pdf | 3M | 8468-21B1-RK-TP | 517-8468-21B1-RK-TP | 3M6821B1-ND | If you cannot source the socket then either use an equivalent replacement, or leave it unpopulated.
2 | U52, U60 | 74AHCT04 | Package_SO:TSSOP-14_4.4x5mm_P0.65mm | https://assets.nexperia.com/documents/data-sheet/74AHC_AHCT04.pdf | Nexperia | 74AHCT04APWJ | 771-74AHCT04APWJ | 1727-74AHCT04APWJCT-ND
1 | U62 | CD74HC173PWR | Package_SO:TSSOP-16_4.4x5mm_P0.65mm | https://www.ti.com/general/docs/suppproductinfo.tsp?distId=26&gotoUrl=https://www.ti.com/lit/gpn/cd74hc173 | Texas Instruments | CD74HC173PWR | 595-CD74HC173PWR | 296-12792-1-ND

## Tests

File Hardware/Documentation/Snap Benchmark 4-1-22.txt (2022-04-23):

Turtle16 with u8:
Compiling the benchmark program 1000 times now...
Compile took an average of 0.00516347 seconds
Running fibonacci program now...
Program runtime benchmark completed in 61,368 cycles. This took 0.067331 seconds
Program ended with exit code: 0

Turtle16 with u16:
Compiling the benchmark program 1000 times now...
Compile took an average of 0.00499475 seconds
Running fibonacci program now...
Program runtime benchmark completed in 53,472 cycles. This took 0.0575761 seconds
Program ended with exit code: 0

TurtleTTL with u8:
Compiling the benchmark program 1000 times now...
Compile took an average of 0.0149253 seconds
Running fibonacci program now...
Program runtime benchmark completed in 471,323 cycles. This took 2.03358 seconds
Program ended with exit code: 0

TurtleTTL with u16:
Compiling the benchmark program 1000 times now...
Compile took an average of 0.0156867 seconds
Running fibonacci program now...
Program runtime benchmark completed in 522,515 cycles. This took 2.23672 seconds
Program ended with exit code: 0

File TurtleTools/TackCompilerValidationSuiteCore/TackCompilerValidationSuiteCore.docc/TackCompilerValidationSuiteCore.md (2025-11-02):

# ``TackCompilerValidationSuiteCore``

<!--@START_MENU_TOKEN@-->Summary<!--@END_MENU_TOKEN@-->

## Overview

<!--@START_MENU_TOKEN@-->Text<!--@END_MENU_TOKEN@-->

## Topics

### <!--@START_MENU_TOKEN@-->Group<!--@END_MENU_TOKEN@-->

- <!--@START_MENU_TOKEN@-->``Symbol``<!--@END_MENU_TOKEN@-->

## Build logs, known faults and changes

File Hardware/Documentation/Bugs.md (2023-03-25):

# Turtle16: Hardware Bugs, Limitations, and Weaknesses

In Rev C, several hardware changes have been to the Simulator made which necessitate corresponding changes to schematics and PCB layouts. This has not yet been done. The new N condition code must be routed through the CPU. The instruction decoder needs changes to accomodate changes to the pinout of the ATF22V10 made when the N condition code was added.

The computer is not self-programming. Instruction memory is stored entirely in a pair of ROMs. The memory must be reprogrammed using a device like the TL866ii+. This could be improved by replacing the instruction ROM ZIF sockets with a dual port memory where one port is connected to the Instruction Decoder and the other port is connected to the system memory bus. This dual port memory could be a true dual port SRAM, or it could be a time-shared SRAM. Some method would need to be introduced to fill the contents of this RAM when the computer first powers on.
* This is a work-in-progress for Rev C where instruction ROM will be completed by a bit of dual-port memory, accessible for read/write from the memory bus.

The CPU is not capable of forwarding the Store Operand. The Hazard Control Unit works around this limitation by introducing a pipeline stall whenever a Read-After-Write hazard involves the Store Operand.

The implementation of the register file is one of the weaker points of the CPU design. The 7024L15PFG dual port SRAMs are currently difficult to source and can be expensive. A different design based on time-shared multiplexed SRAM would be a better solution, providing equivalent performance at a lower cost.

Possibly, the instruction decoder ROMs could be replaced with a set of three ATF22V10 to allow instruction decoding in 7ns instead of 45ns. Combine this with changes to instruction memory and the computer will be capable of much higher clock speeds.
* This is a work-in-progress for Rev C where this change is being made.

While not a bug, a weakness of the CPU is the limited number of general-purpose registers. There is space for three three-bit fields in the instruction word. It would also be possible to have the instruction use two operands, where one operand is used as an implicit destination register, as is done in some other ISAs. Taking this approach, the two register fields could both be five bits wide, allowing the number of registers to expand from eight to thirty two. In practical terms, this will greatly reduce register spilling, which is always quite slow.

Another weakness of the CPU is that it does not include a hardware shifter. This means, unintuitively, that left and right shift are very slow operations implemented in terms of addition and bitwise logical operations. The addition of a one cycle barrel shifter would greatly improve performance.

There was a hardware bug on Rev A where a program must begin with a single leading NOP at address zero to ensure correct operation during the reset cycle. I'm not sure yet that I've completely solved this problem on Rev B.

The data sheet for the '245 and '374 recommend a pull-up resistor on OE to ensure high impedance state during power up. I should look for places on the PCB, e.g. EX stage, which could benefit from such a change.

The PCB could benefit from many more test points. For example, a test point for the raw clock signal, and test points for the program counter.
* This is being implemented on Rev C.

Test points should have been placed on the front side of the PCB for convenience during debugging. Flipping the PCB to touch a probe to a test point is a very awkward thing to do.
* This is being implemented on Rev C.

For that matter, all components should have been placed on the front side of the PCB. This would greatly simplify assembly.
* This is being implemented on Rev C.

There's not enough space around the two 7381 ICs and the two ZIF sockets. This makes rework and debugging difficult. There's not enough room for PLCC-68 sockets either, for example.
* The ZIF sockets have been removed on Rev C which makes this point partially moot.

The SMD PLCC-32 sockets are a pain to install. Can I do anything differently to make this easier next time? Also, it's really hard to remove chips from these PLCC-32 sockets with the extractor. Use different sockets next time?
* NOTE: Is this actually a problem? I don't know if this is something that needs to be addressed at all.

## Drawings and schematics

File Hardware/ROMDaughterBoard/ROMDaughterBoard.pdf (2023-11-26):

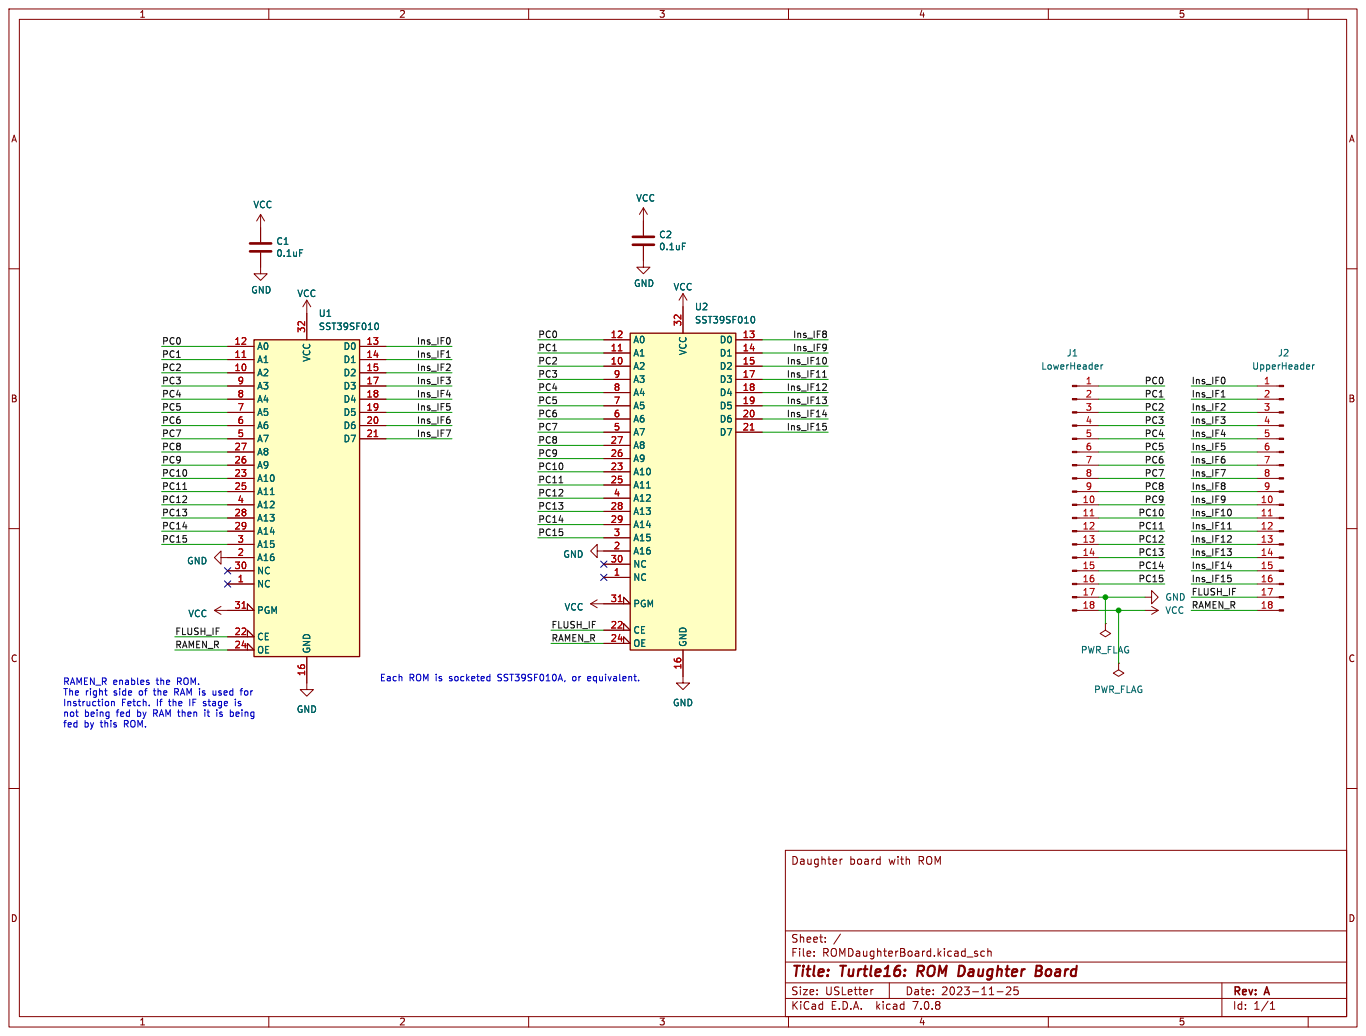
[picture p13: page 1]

Each ROM is socketed SST39SF010A, or equivalent. RAMEN_R enables the ROM. The right side of the RAM is used for

Id: 1/1 Title: Turtle16: ROM Daughter Board

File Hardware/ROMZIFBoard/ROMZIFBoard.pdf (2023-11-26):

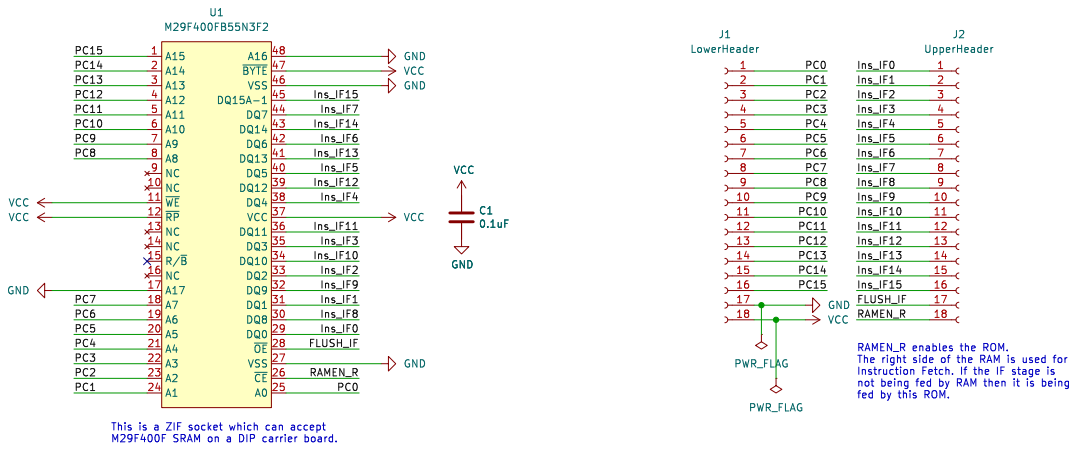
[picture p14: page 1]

fed by this ROM. C1

Id: 1/1 Title: Turtle16: ROM ZIF Daughter Board

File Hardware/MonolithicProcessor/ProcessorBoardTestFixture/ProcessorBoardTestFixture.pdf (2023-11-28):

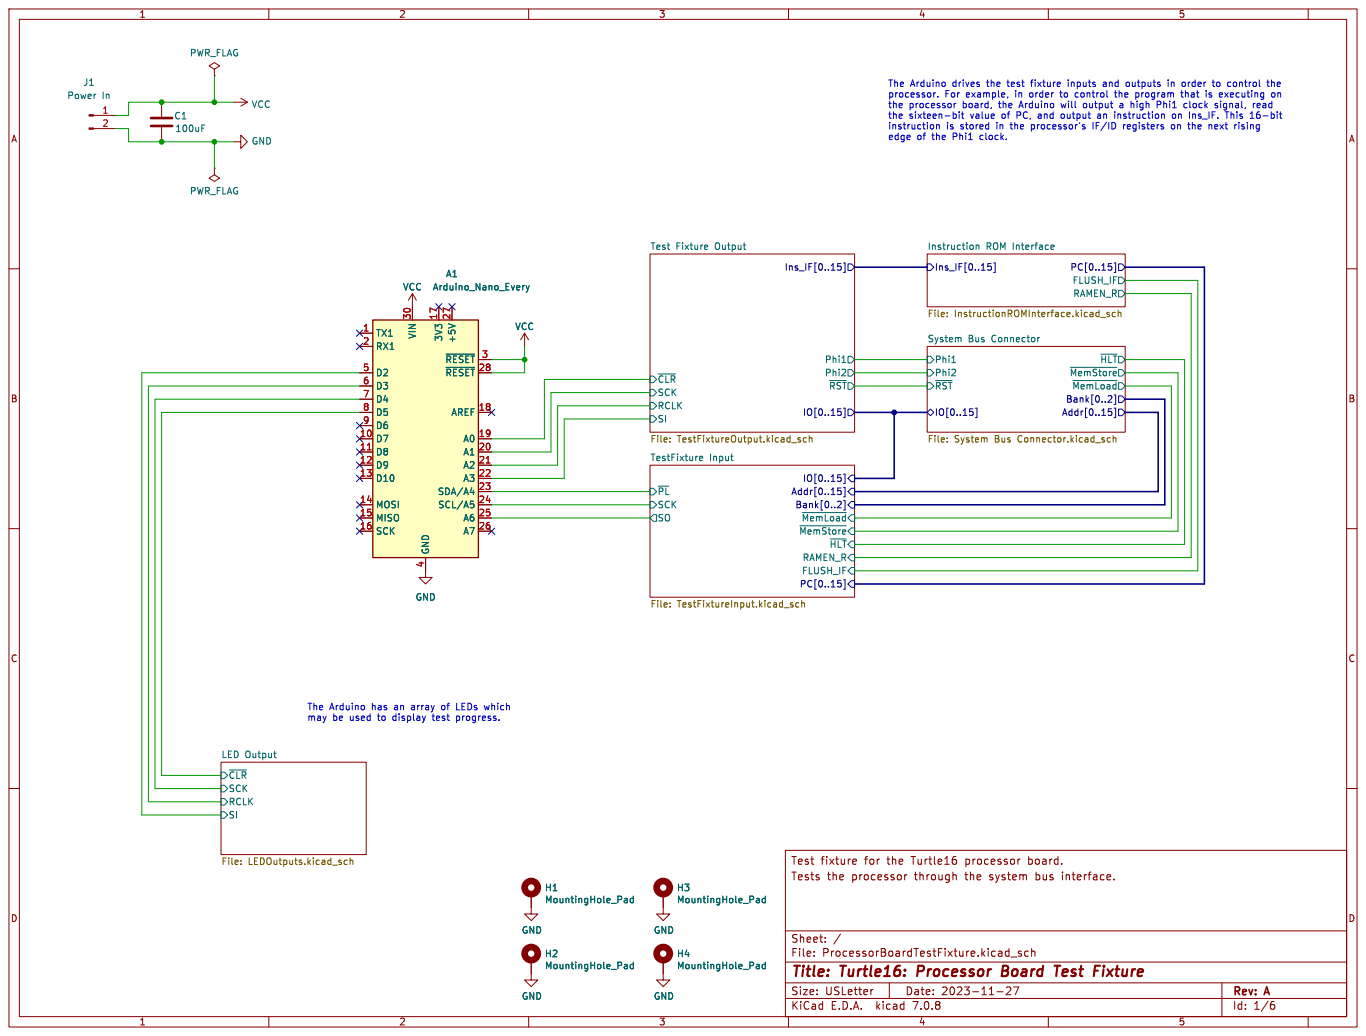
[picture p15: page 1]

Ins_IF[0..15] Test Fixture Output File: TestFixtureOutput.kicad_sch SI SCK

4 D2 5 D3 6 D4 7 D5 8 D6 9 VCC GND GND GND

System Bus Connector File: System Bus Connector.kicad_sch ~{CLR} SCK RCLK

The Arduino has an array of LEDs which may be used to display test progress.

LED Output File: LEDOutputs.kicad_sch

Id: 1/6 Title: Turtle16: Processor Board Test Fixture

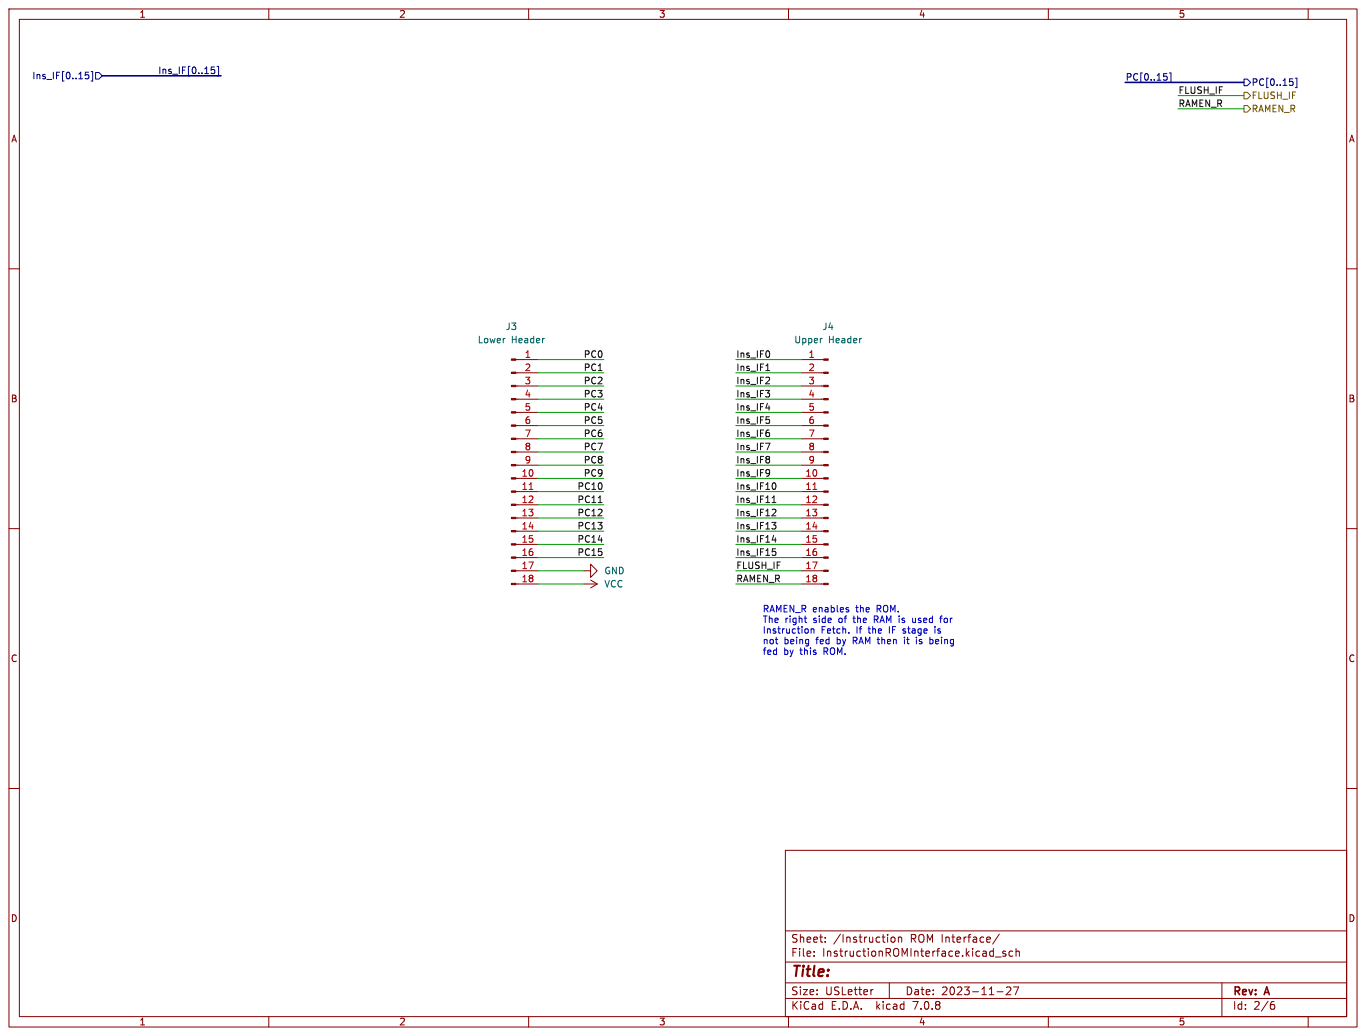
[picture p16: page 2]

fed by this ROM.

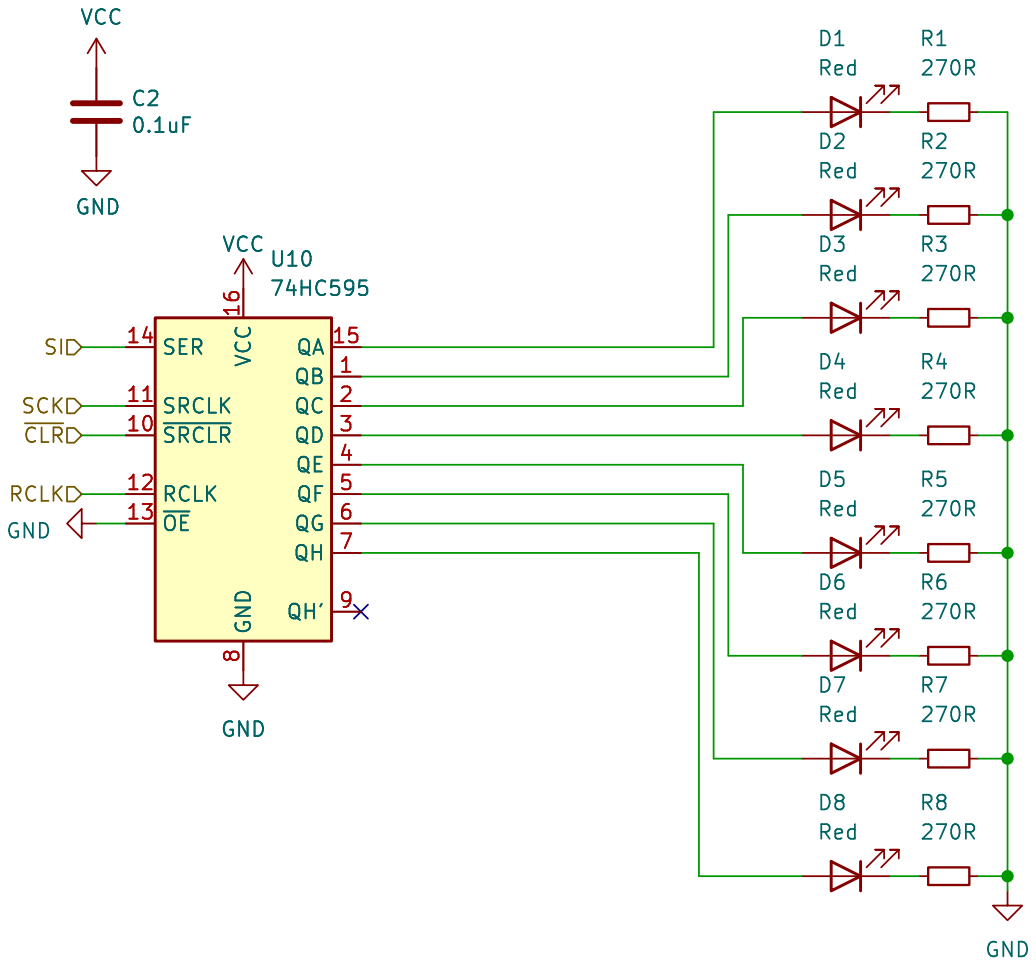
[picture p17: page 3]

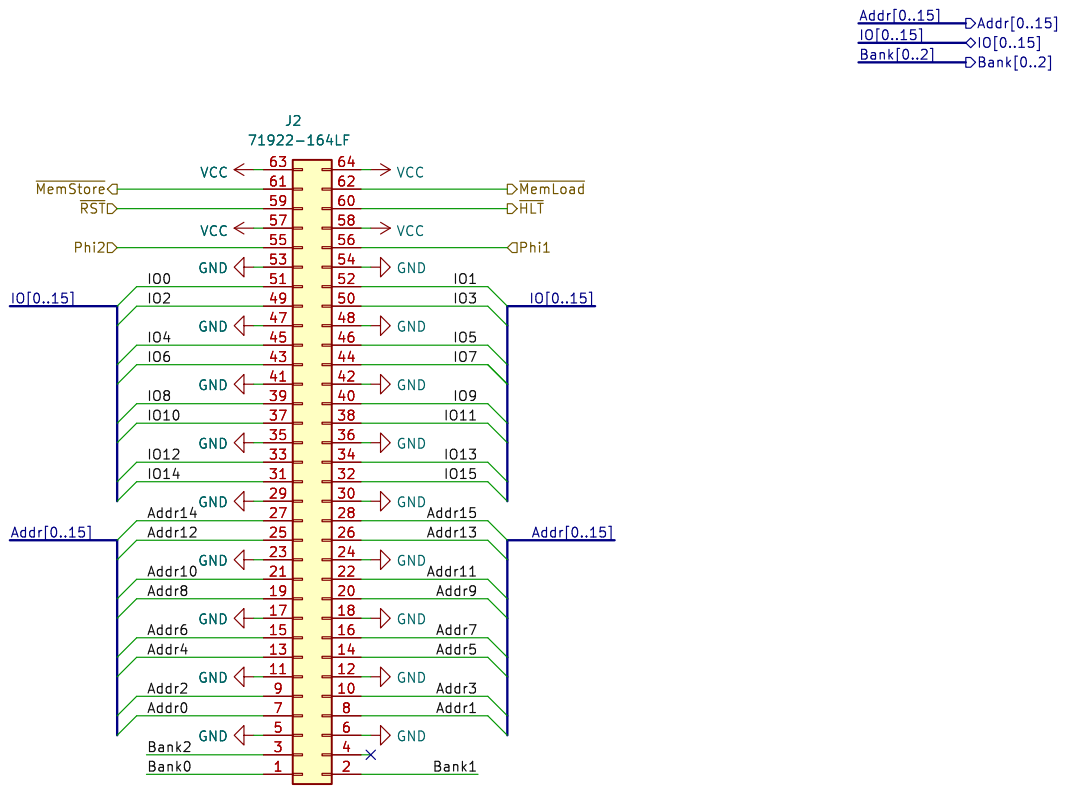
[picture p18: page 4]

VCC GND GND GND GND GND
9 VCC GND

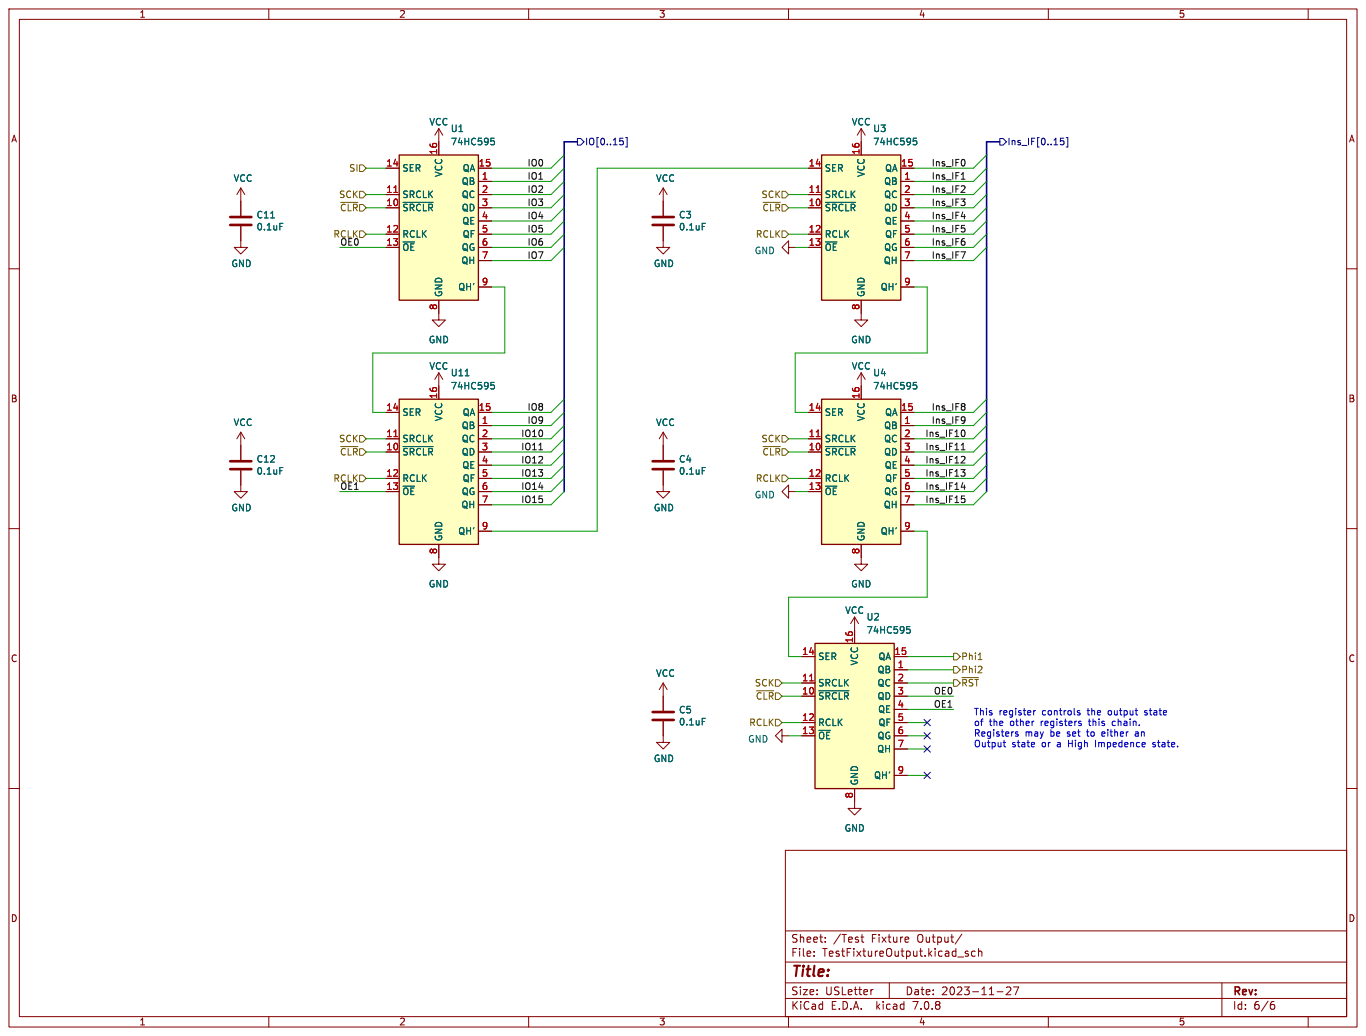
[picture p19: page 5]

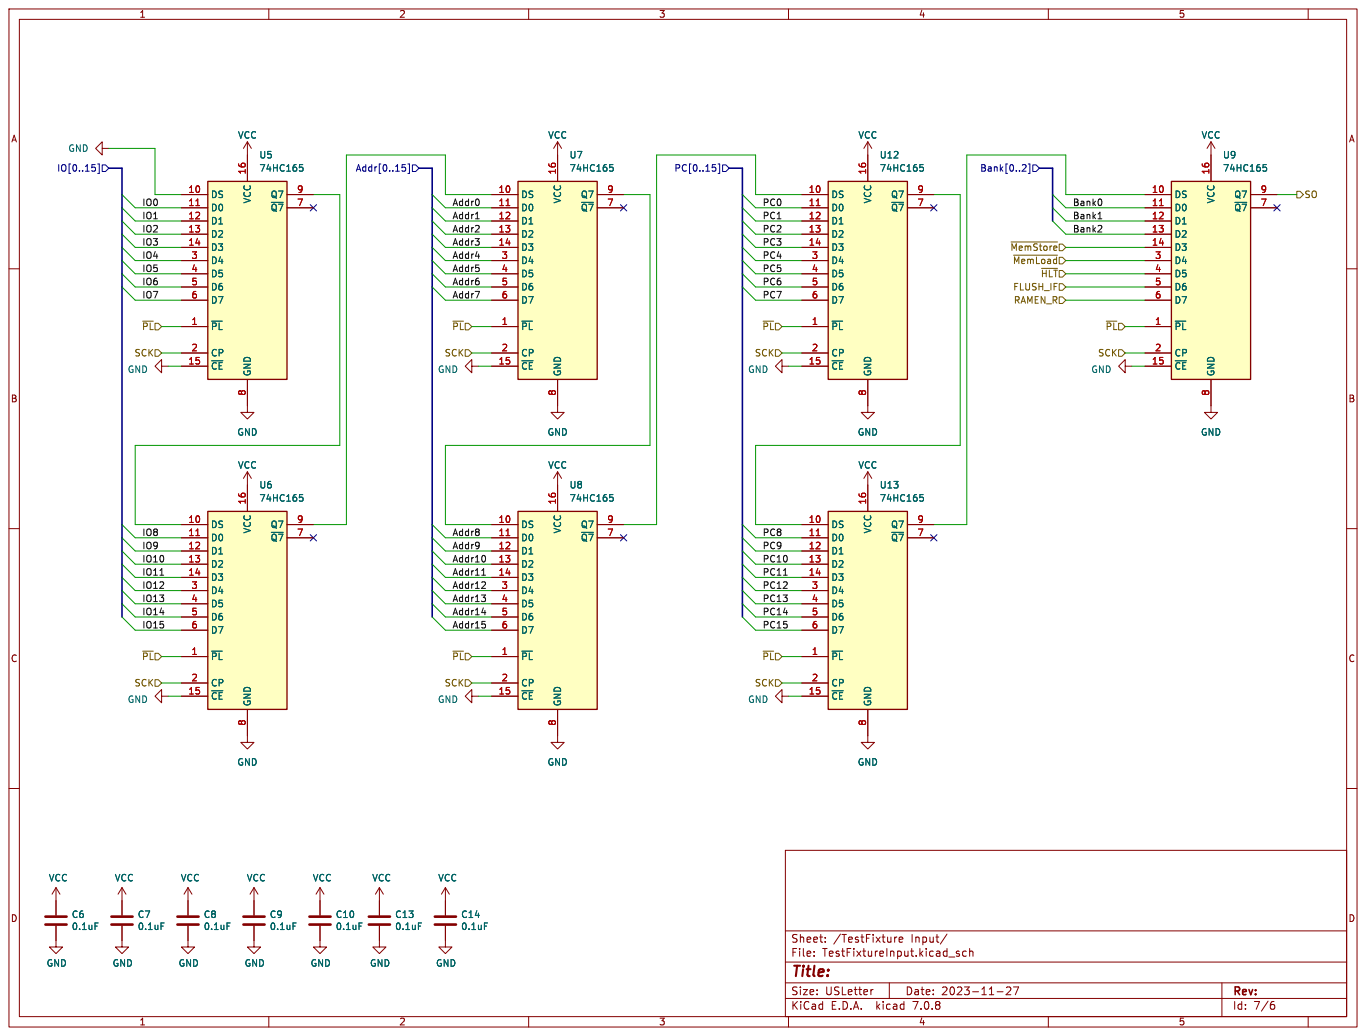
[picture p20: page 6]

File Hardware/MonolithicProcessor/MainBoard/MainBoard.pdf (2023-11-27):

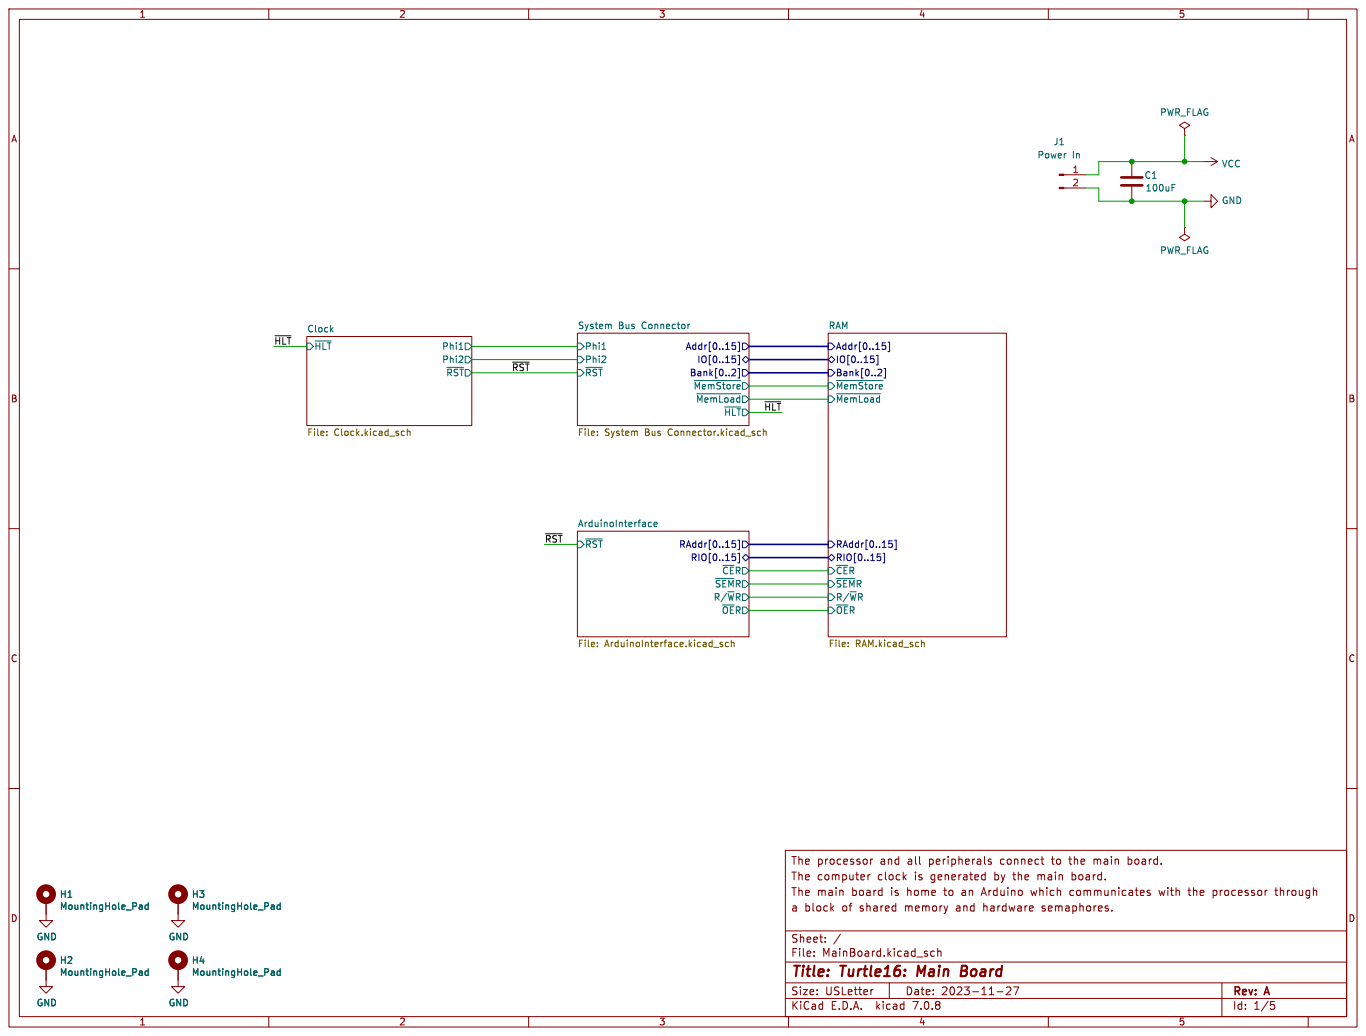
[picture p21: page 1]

Id: 1/5 Title: Turtle16: Main Board

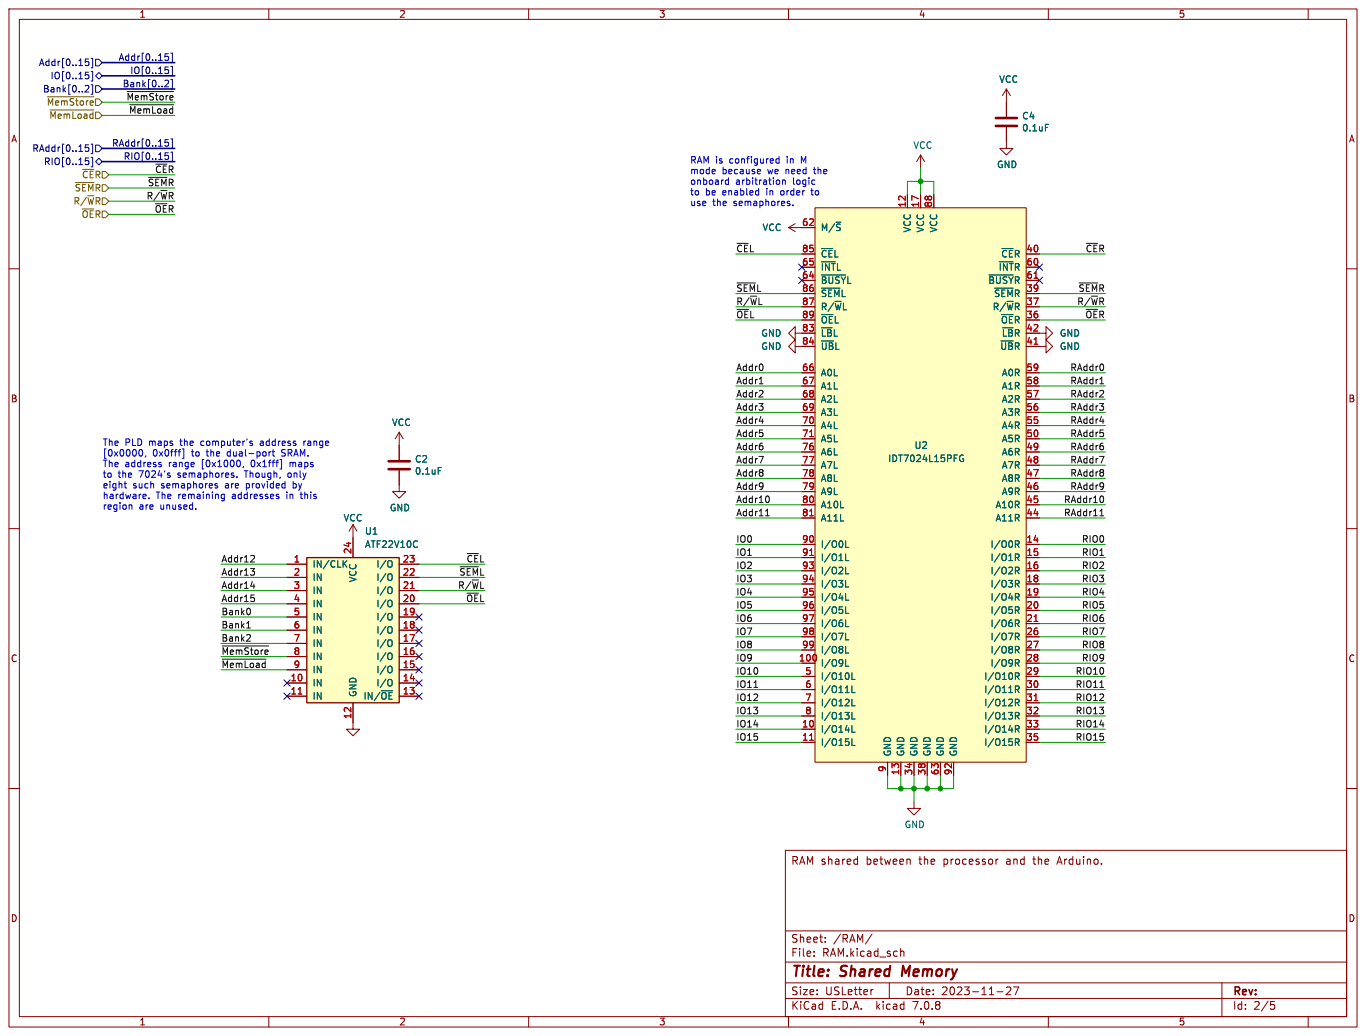
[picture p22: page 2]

mode because we need the
to be enabled in order to

Id: 2/5 Title: Shared Memory

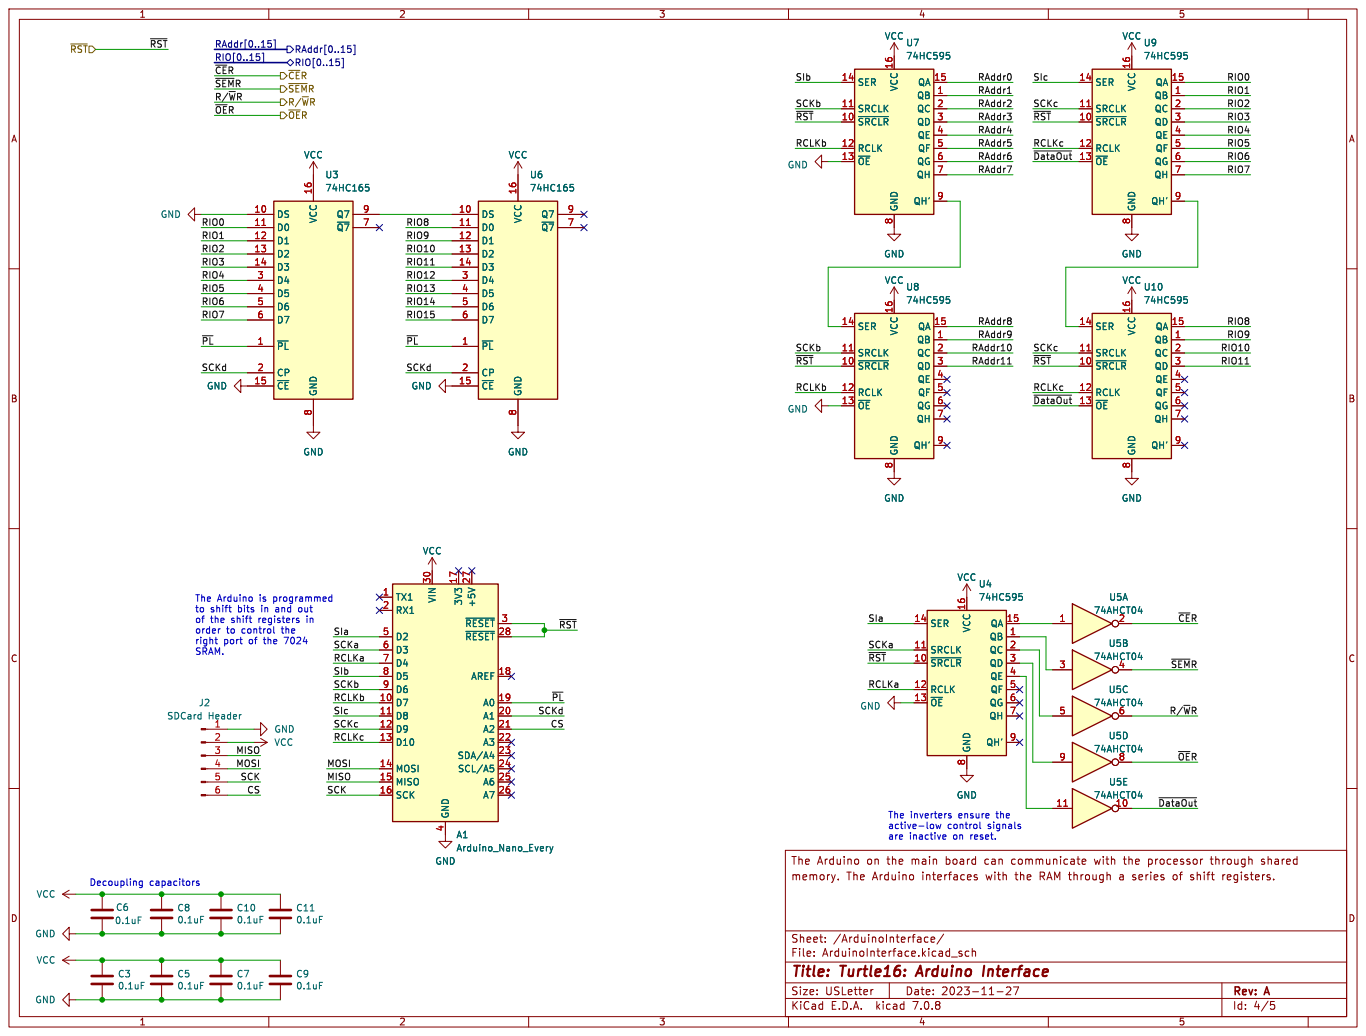
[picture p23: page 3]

~{RST} RCLKb SCKb The Arduino is programmed

Id: 4/5 Title: Turtle16: Arduino Interface

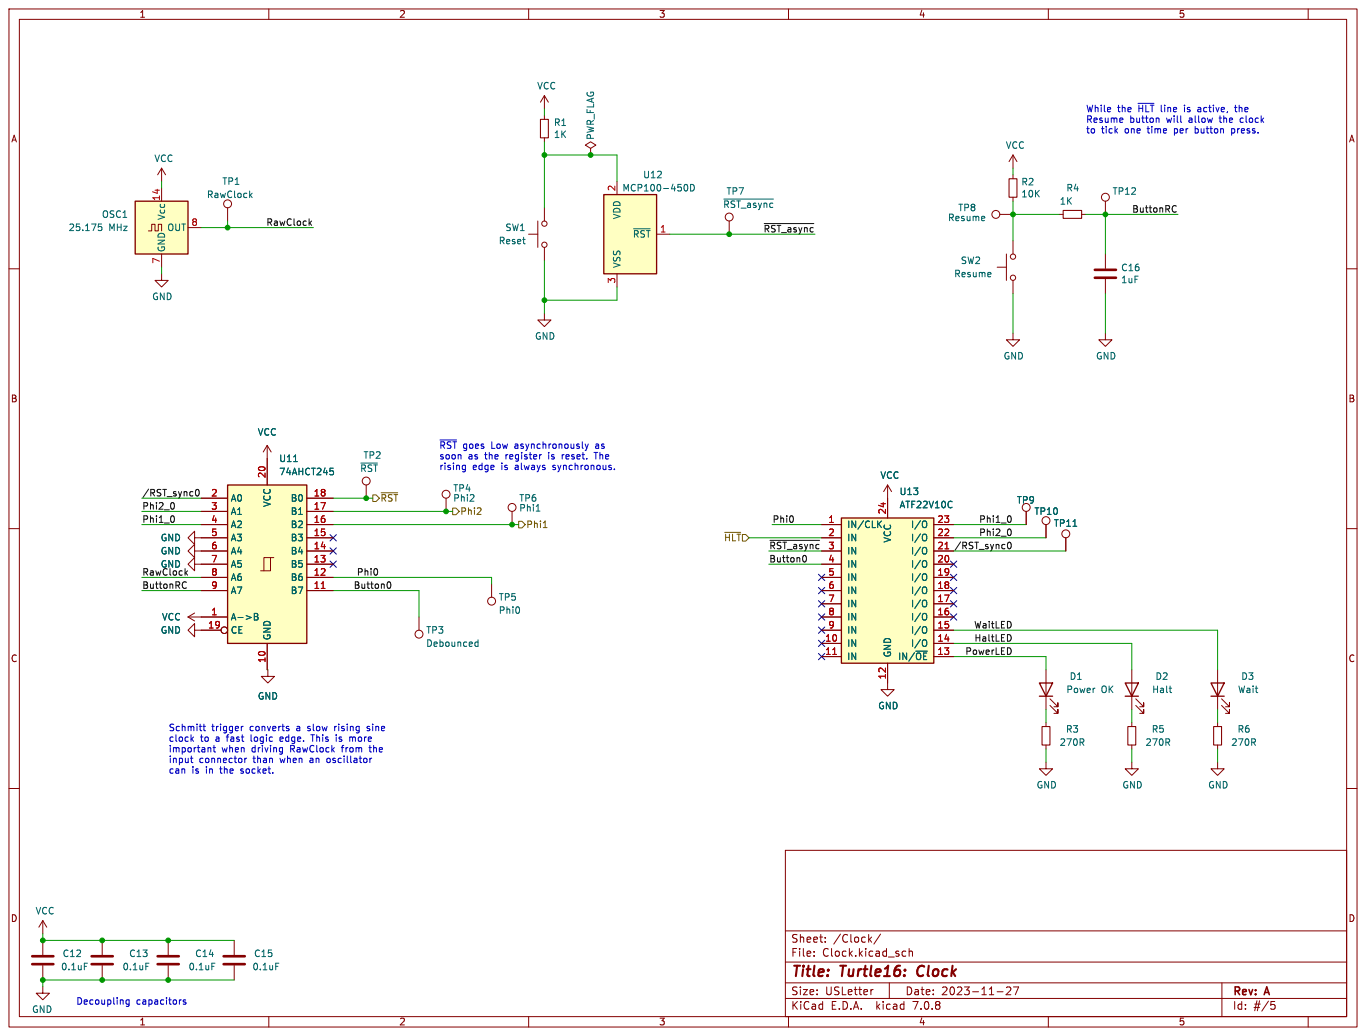
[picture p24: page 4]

rising edge is always synchronous. Schmitt trigger converts a slow rising sine
74AHCT245 GND GND GND

/RST_sync0 Button0 ~{RST_async} Phi0 RawClock ButtonRC
VCC GND GND GND

clock to a fast logic edge. This is more

File: Clock.kicad_sch Sheet: /Clock/ VCC


VCC GND GND GND GND GND GND GND
9 GND GND

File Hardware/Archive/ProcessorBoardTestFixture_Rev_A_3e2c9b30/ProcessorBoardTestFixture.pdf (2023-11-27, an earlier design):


System Bus Connector File: System Bus Connector.kicad_sch SI SCK

IO[0..15] Phi1 ~{RST} Phi2 System Memory Bus Output File: SystemMemoryBusOutput.kicad_sch

4 D2 5 D3 6 D4 7 D5 8 D6 9 A1 VCC Arduino_Nano_Every H1 MountingHole_Pad GND GND GND

System Memory Bus Input File: SystemMemoryBusInput.kicad_sch

LED Output File: LEDOutputs.kicad_sch

Id: 1/5 Title: Turtle16: Processor Board Test Fixture


Id: 3/5 Title: File: LEDOutputs.kicad_sch Sheet: /LED Output/ R6


VCC GND GND GND GND GND
9 VCC GND



8 Q7 9 GND GND GND GND

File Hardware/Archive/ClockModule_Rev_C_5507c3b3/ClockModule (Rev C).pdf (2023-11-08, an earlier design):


~{SINGLE} Clock File: Clock.kicad_sch

File: ClockModule.kicad_sch Sheet: /
Id: 1/2 Title: Turtle16: Clock Module


is low, or when RDY is high. Schmitt trigger converts a slow rising sine
clock to a fast logic edge. This is more

the reset cycle when ~{RST_sync}

The Phi1 clock is split into four clock outputs to allow clock line

the signal rises from Low to High
quickly.

File: Clock.kicad_sch Sheet: /Clock/ GNDVCC 14 GND

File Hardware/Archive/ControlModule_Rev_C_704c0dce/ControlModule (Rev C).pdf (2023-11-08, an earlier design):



the second half of the clock period before the interstage




ID Flush File: IDFlush.kicad_sch Carry OVF

Description
þÿ         Halt Clock Select Store Operand 0 Select Store Operand 1 Select Right Operand 1 Select Right Operand 2 Flags Register In ALU Carry input ALU I0 input ALU I1 input ALU I2 input ALU RS0 input ALU RS1 input

Left operand is unused Right operand is unused



same time, the ID and IF stages must both be flushed.

Hazard Control Comparators File: HazardControlComparators.kicad_sch VCC



Id: 33/10 Title: File: ID_EX_InstructionWord.kicad_sch Sheet: /ID/sheet60693B99/


Id: 34/10 Title: ID/EX Control Register File: ID_EX_ControlWord.kicad_sch Sheet: /ID/sheet60693B98/

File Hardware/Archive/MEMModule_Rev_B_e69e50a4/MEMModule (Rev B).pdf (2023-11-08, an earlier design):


Id: 1/14 Title: Turtle16: MEM, RAM, ROM


If all bus devices are ready then they allow the line to remain high.
If any bus device is not ready then it drives the line low. When RDY is driven low, the CPU Phi1 clock stops and the CPU

VCC GND GND GND GND
9 GND GND GND GND

GND GND


~{RDY} Buffer Memory Control Signals File: BufferMemoryControlSignals.kicad_sch

~{Assert} Buffer StoreOp As Bus I/O


74AHCT245 VCC GND GND GND


Id: 5/14 Title: MEM: Buffer StoreOp



Id: 7/14 Title: MEM/WB: Control Word Register File: Ctl_15_23_Register.kicad_sch Sheet: /MEM/sheet5FD643DA/



VCC GND VCC GND GND GND GND

If the IF stage is not being fed by ROM then it is being fed by RAM.

File: RAM.kicad_sch Sheet: /Memory/RAM/
Id: 9/14 Title: Turtle16: RAM


File: ALUResultRegister_MEM_WB.kicad_sch Sheet: /MEM/Sheet5FD9EFDA/ GND

Id: 10/14 Title: ALU Result Register MEM/WB


Id: 11/14 Title: Turtle16: MEM Prototype Inputs


Id: 12/14 Title: Turtle16: MEM Prototype Outputs


the memory bus. This mapping may be
devices added to the bus. If there are
no other devices on the bus then a

Id: 13/14 Title: File: Memory.kicad_sch Sheet: /Memory/


If the IF stage is not being fed by RAM then it is being fed by this ROM.

Id: 14/14 Title: File: ROM.kicad_sch Sheet: /Memory/ROM/



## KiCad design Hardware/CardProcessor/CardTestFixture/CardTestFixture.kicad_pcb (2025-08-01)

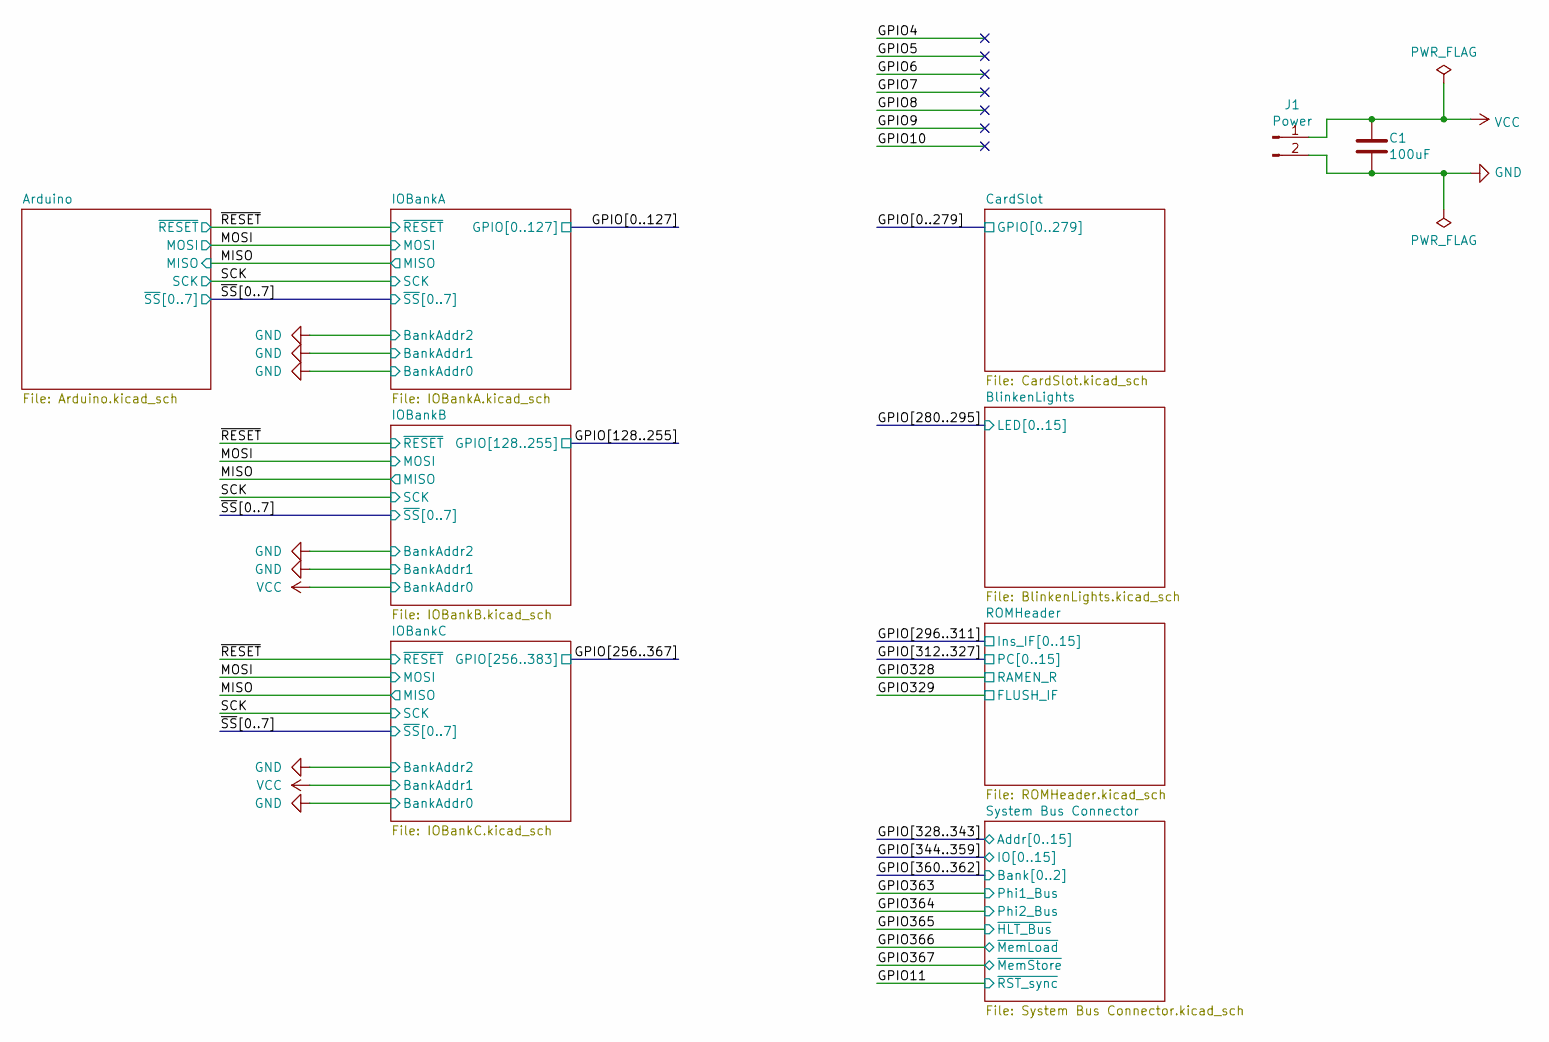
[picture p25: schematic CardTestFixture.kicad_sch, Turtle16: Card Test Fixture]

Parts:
C1: 100uF; C_1206_3216Metric; Manufacturer# AMK316ABJ107ML-T; Mouser# 963-AMK316ABJ107ML-T
J1: Power; 172448-0002; Manufacturer# 172448-0002; Mouser# 538-172448-0002

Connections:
GND: C1.2, J1.2; also elsewhere on the board
VCC: C1.1, J1.1; also elsewhere on the board

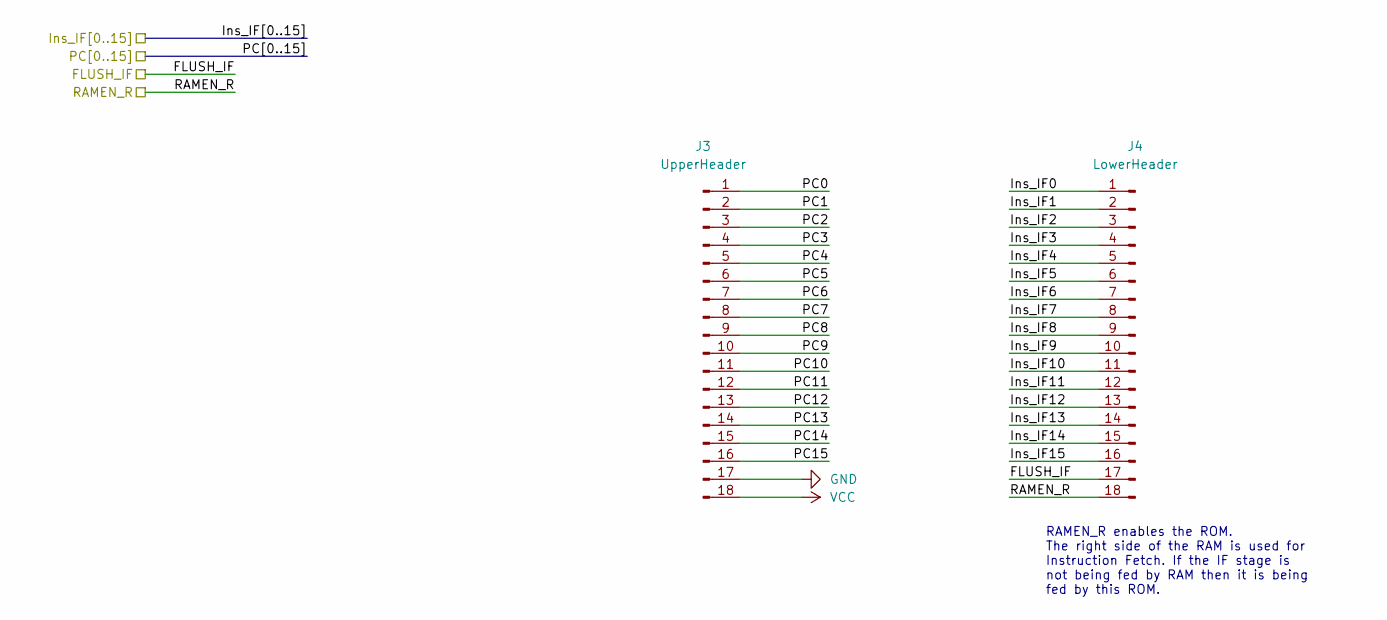
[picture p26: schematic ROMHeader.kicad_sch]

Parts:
J3: UpperHeader; PinHeader_1x18_P2.54mm_Vertical
J4: LowerHeader; PinHeader_1x18_P2.54mm_Vertical

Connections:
/GPIO296: J4.1; also elsewhere on the board
/GPIO297: J4.2; also elsewhere on the board
/GPIO298: J4.3; also elsewhere on the board
/GPIO299: J4.4; also elsewhere on the board
/GPIO300: J4.5; also elsewhere on the board
/GPIO301: J4.6; also elsewhere on the board
/GPIO302: J4.7; also elsewhere on the board
/GPIO303: J4.8; also elsewhere on the board
/GPIO304: J4.9; also elsewhere on the board
/GPIO305: J4.10; also elsewhere on the board
/GPIO306: J4.11; also elsewhere on the board
/GPIO307: J4.12; also elsewhere on the board
/GPIO308: J4.13; also elsewhere on the board
/GPIO309: J4.14; also elsewhere on the board
/GPIO310: J4.15; also elsewhere on the board
/GPIO311: J4.16; also elsewhere on the board
/GPIO312: J3.1; also elsewhere on the board
/GPIO313: J3.2; also elsewhere on the board
/GPIO314: J3.3; also elsewhere on the board
/GPIO315: J3.4; also elsewhere on the board
/GPIO316: J3.5; also elsewhere on the board
/GPIO317: J3.6; also elsewhere on the board
/GPIO318: J3.7; also elsewhere on the board
/GPIO319: J3.8; also elsewhere on the board
/GPIO320: J3.9; also elsewhere on the board
/GPIO321: J3.10; also elsewhere on the board
/GPIO322: J3.11; also elsewhere on the board
/GPIO323: J3.12; also elsewhere on the board
/GPIO324: J3.13; also elsewhere on the board
/GPIO325: J3.14; also elsewhere on the board
/GPIO326: J3.15; also elsewhere on the board
/GPIO327: J3.16; also elsewhere on the board
/GPIO328: J4.18; also elsewhere on the board
/GPIO329: J4.17; also elsewhere on the board
GND: J3.17; also elsewhere on the board
VCC: J3.18; also elsewhere on the board

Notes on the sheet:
RAMEN_R enables the ROM. The right side of the RAM is used for Instruction Fetch. If the IF stage is not being fed by RAM then it is being fed by this ROM.

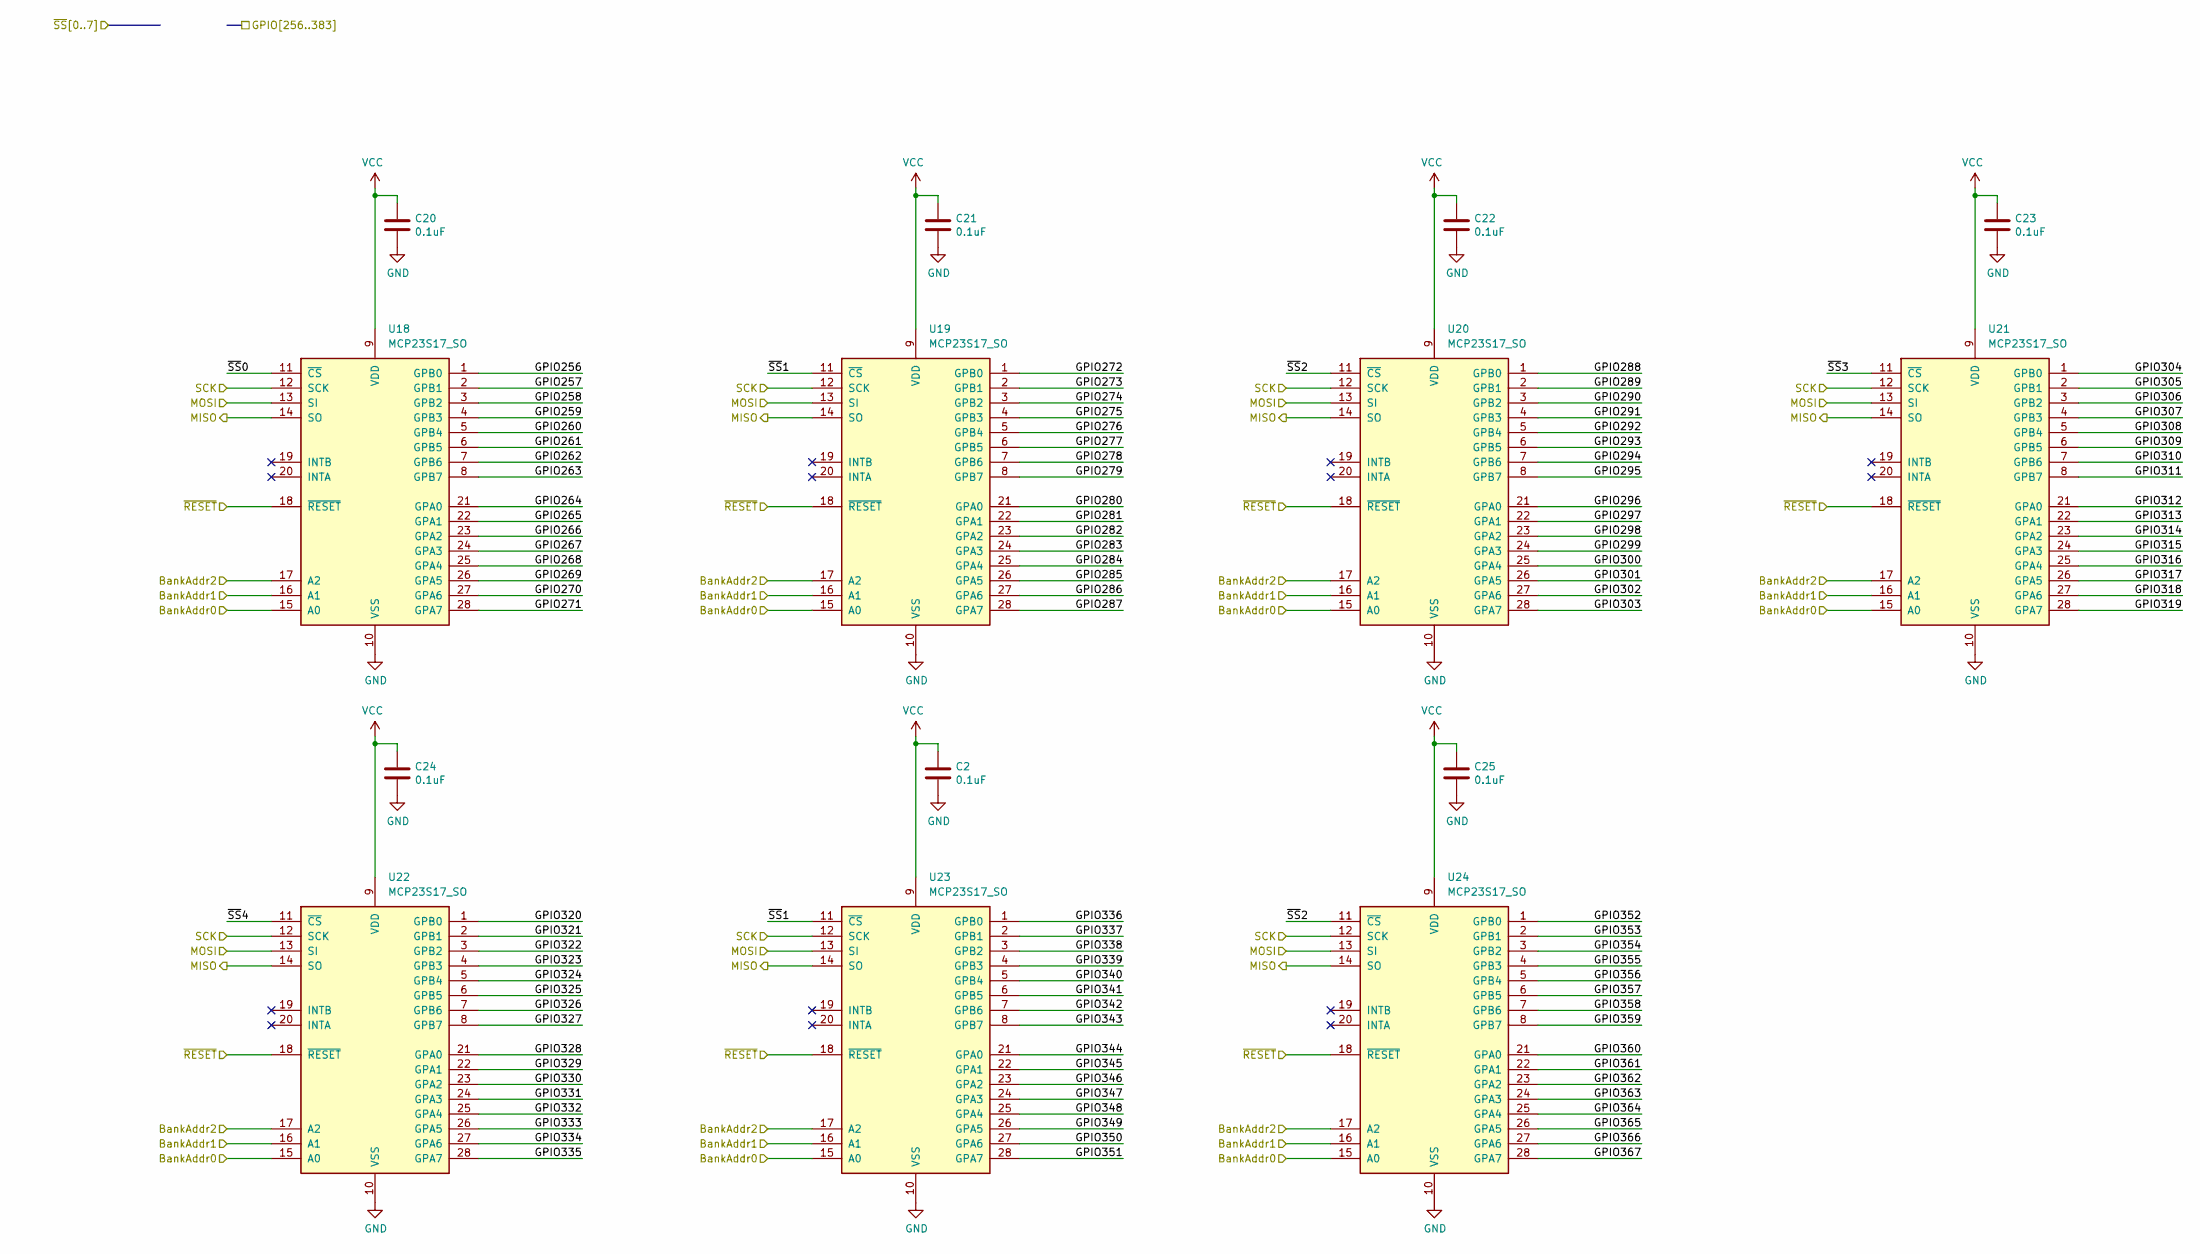
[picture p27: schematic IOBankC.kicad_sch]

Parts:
C2, C20, C21, C22, C23, C24, C25: 0.1uF; C_0603_1608Metric; Manufacturer# EMK107B7104KAHT; Mouser# 963-EMK107B7104KAHT
U18, U19, U20, U21, U22, U23, U24: MCP23S17_SO; SOIC-28W_7.5x17.9mm_P1.27mm

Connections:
/GPIO256: U18.1 (GPB0); also elsewhere on the board
/GPIO257: U18.2 (GPB1); also elsewhere on the board
/GPIO258: U18.3 (GPB2); also elsewhere on the board
/GPIO259: U18.4 (GPB3); also elsewhere on the board
/GPIO260: U18.5 (GPB4); also elsewhere on the board
/GPIO261: U18.6 (GPB5); also elsewhere on the board
/GPIO262: U18.7 (GPB6); also elsewhere on the board
/GPIO263: U18.8 (GPB7); also elsewhere on the board
/GPIO264: U18.21 (GPA0); also elsewhere on the board
/GPIO265: U18.22 (GPA1); also elsewhere on the board
/GPIO266: U18.23 (GPA2); also elsewhere on the board
/GPIO267: U18.24 (GPA3); also elsewhere on the board
/GPIO268: U18.25 (GPA4); also elsewhere on the board
/GPIO269: U18.26 (GPA5); also elsewhere on the board
/GPIO270: U18.27 (GPA6); also elsewhere on the board
/GPIO271: U18.28 (GPA7); also elsewhere on the board
/GPIO272: U19.1 (GPB0); also elsewhere on the board
/GPIO273: U19.2 (GPB1); also elsewhere on the board
/GPIO274: U19.3 (GPB2); also elsewhere on the board
/GPIO275: U19.4 (GPB3); also elsewhere on the board
/GPIO276: U19.5 (GPB4); also elsewhere on the board
/GPIO277: U19.6 (GPB5); also elsewhere on the board
/GPIO278: U19.7 (GPB6); also elsewhere on the board
/GPIO279: U19.8 (GPB7); also elsewhere on the board
/GPIO280: U19.21 (GPA0); also elsewhere on the board
/GPIO281: U19.22 (GPA1); also elsewhere on the board
/GPIO282: U19.23 (GPA2); also elsewhere on the board
/GPIO283: U19.24 (GPA3); also elsewhere on the board
/GPIO284: U19.25 (GPA4); also elsewhere on the board
/GPIO285: U19.26 (GPA5); also elsewhere on the board
/GPIO286: U19.27 (GPA6); also elsewhere on the board
/GPIO287: U19.28 (GPA7); also elsewhere on the board
/GPIO288: U20.1 (GPB0); also elsewhere on the board
/GPIO289: U20.2 (GPB1); also elsewhere on the board
/GPIO290: U20.3 (GPB2); also elsewhere on the board
/GPIO291: U20.4 (GPB3); also elsewhere on the board
/GPIO292: U20.5 (GPB4); also elsewhere on the board
/GPIO293: U20.6 (GPB5); also elsewhere on the board
/GPIO294: U20.7 (GPB6); also elsewhere on the board
/GPIO295: U20.8 (GPB7); also elsewhere on the board
/GPIO296: U20.21 (GPA0); also elsewhere on the board
/GPIO297: U20.22 (GPA1); also elsewhere on the board
/GPIO298: U20.23 (GPA2); also elsewhere on the board
/GPIO299: U20.24 (GPA3); also elsewhere on the board
/GPIO300: U20.25 (GPA4); also elsewhere on the board
/GPIO301: U20.26 (GPA5); also elsewhere on the board
/GPIO302: U20.27 (GPA6); also elsewhere on the board
/GPIO303: U20.28 (GPA7); also elsewhere on the board
/GPIO304: U21.1 (GPB0); also elsewhere on the board
/GPIO305: U21.2 (GPB1); also elsewhere on the board
/GPIO306: U21.3 (GPB2); also elsewhere on the board
/GPIO307: U21.4 (GPB3); also elsewhere on the board
/GPIO308: U21.5 (GPB4); also elsewhere on the board
/GPIO309: U21.6 (GPB5); also elsewhere on the board
/GPIO310: U21.7 (GPB6); also elsewhere on the board
/GPIO311: U21.8 (GPB7); also elsewhere on the board
/GPIO312: U21.21 (GPA0); also elsewhere on the board
/GPIO313: U21.22 (GPA1); also elsewhere on the board
/GPIO314: U21.23 (GPA2); also elsewhere on the board
/GPIO315: U21.24 (GPA3); also elsewhere on the board
/GPIO316: U21.25 (GPA4); also elsewhere on the board
/GPIO317: U21.26 (GPA5); also elsewhere on the board
/GPIO318: U21.27 (GPA6); also elsewhere on the board
/GPIO319: U21.28 (GPA7); also elsewhere on the board
/GPIO320: U22.1 (GPB0); also elsewhere on the board
/GPIO321: U22.2 (GPB1); also elsewhere on the board
/GPIO322: U22.3 (GPB2); also elsewhere on the board
/GPIO323: U22.4 (GPB3); also elsewhere on the board
/GPIO324: U22.5 (GPB4); also elsewhere on the board
/GPIO325: U22.6 (GPB5); also elsewhere on the board
/GPIO326: U22.7 (GPB6); also elsewhere on the board
/GPIO327: U22.8 (GPB7); also elsewhere on the board
/GPIO328: U22.21 (GPA0); also elsewhere on the board
/GPIO329: U22.22 (GPA1); also elsewhere on the board
/GPIO330: U22.23 (GPA2); also elsewhere on the board
/GPIO331: U22.24 (GPA3); also elsewhere on the board
/GPIO332: U22.25 (GPA4); also elsewhere on the board
/GPIO333: U22.26 (GPA5); also elsewhere on the board
/GPIO334: U22.27 (GPA6); also elsewhere on the board
/GPIO335: U22.28 (GPA7); also elsewhere on the board
/GPIO336: U23.1 (GPB0); also elsewhere on the board
/GPIO337: U23.2 (GPB1); also elsewhere on the board
/GPIO338: U23.3 (GPB2); also elsewhere on the board
/GPIO339: U23.4 (GPB3); also elsewhere on the board
/GPIO340: U23.5 (GPB4); also elsewhere on the board
/GPIO341: U23.6 (GPB5); also elsewhere on the board
/GPIO342: U23.7 (GPB6); also elsewhere on the board
/GPIO343: U23.8 (GPB7); also elsewhere on the board
/GPIO344: U23.21 (GPA0); also elsewhere on the board
/GPIO345: U23.22 (GPA1); also elsewhere on the board
/GPIO346: U23.23 (GPA2); also elsewhere on the board
/GPIO347: U23.24 (GPA3); also elsewhere on the board
/GPIO348: U23.25 (GPA4); also elsewhere on the board
/GPIO349: U23.26 (GPA5); also elsewhere on the board
/GPIO350: U23.27 (GPA6); also elsewhere on the board
/GPIO351: U23.28 (GPA7); also elsewhere on the board
/GPIO352: U24.1 (GPB0); also elsewhere on the board
/GPIO353: U24.2 (GPB1); also elsewhere on the board
/GPIO354: U24.3 (GPB2); also elsewhere on the board
/GPIO355: U24.4 (GPB3); also elsewhere on the board
/GPIO356: U24.5 (GPB4); also elsewhere on the board
/GPIO357: U24.6 (GPB5); also elsewhere on the board
/GPIO358: U24.7 (GPB6); also elsewhere on the board
/GPIO359: U24.8 (GPB7); also elsewhere on the board
/GPIO360: U24.21 (GPA0); also elsewhere on the board
/GPIO361: U24.22 (GPA1); also elsewhere on the board
/GPIO362: U24.23 (GPA2); also elsewhere on the board
/GPIO363: U24.24 (GPA3); also elsewhere on the board
/GPIO364: U24.25 (GPA4); also elsewhere on the board
/GPIO365: U24.26 (GPA5); also elsewhere on the board
/GPIO366: U24.27 (GPA6); also elsewhere on the board
/GPIO367: U24.28 (GPA7); also elsewhere on the board
/MISO: U18.14 (SO), U19.14 (SO), U20.14 (SO), U21.14 (SO), U22.14 (SO), U23.14 (SO), U24.14 (SO); also elsewhere on the board
/MOSI: U18.13 (SI), U19.13 (SI), U20.13 (SI), U21.13 (SI), U22.13 (SI), U23.13 (SI), U24.13 (SI); also elsewhere on the board
/SCK: U18.12 (SCK), U19.12 (SCK), U20.12 (SCK), U21.12 (SCK), U22.12 (SCK), U23.12 (SCK), U24.12 (SCK); also elsewhere on the board
/~RESET: U18.18 (~RESET), U19.18 (~RESET), U20.18 (~RESET), U21.18 (~RESET), U22.18 (~RESET), U23.18 (~RESET), U24.18 (~RESET); also elsewhere on the board
/~SS0: U18.11 (~CS); also elsewhere on the board
/~SS1: U19.11 (~CS), U23.11 (~CS); also elsewhere on the board
/~SS2: U20.11 (~CS), U24.11 (~CS); also elsewhere on the board
/~SS3: U21.11 (~CS); also elsewhere on the board
/~SS4: U22.11 (~CS); also elsewhere on the board
GND: C2.2, C20.2, C21.2, C22.2, C23.2, C24.2, C25.2, U18.10 (VSS), U18.15 (A0), U18.17 (A2), U19.10 (VSS), U19.15 (A0), U19.17 (A2), U20.10 (VSS), U20.15 (A0), U20.17 (A2), U21.10 (VSS), U21.15 (A0), U21.17 (A2), U22.10 (VSS), U22.15 (A0), U22.17 (A2), U23.10 (VSS), U23.15 (A0), U23.17 (A2), U24.10 (VSS), U24.15 (A0), U24.17 (A2); also elsewhere on the board
VCC: C2.1, C20.1, C21.1, C22.1, C23.1, C24.1, C25.1, U18.9 (VDD), U18.16 (A1), U19.9 (VDD), U19.16 (A1), U20.9 (VDD), U20.16 (A1), U21.9 (VDD), U21.16 (A1), U22.9 (VDD), U22.16 (A1), U23.9 (VDD), U23.16 (A1), U24.9 (VDD), U24.16 (A1); also elsewhere on the board

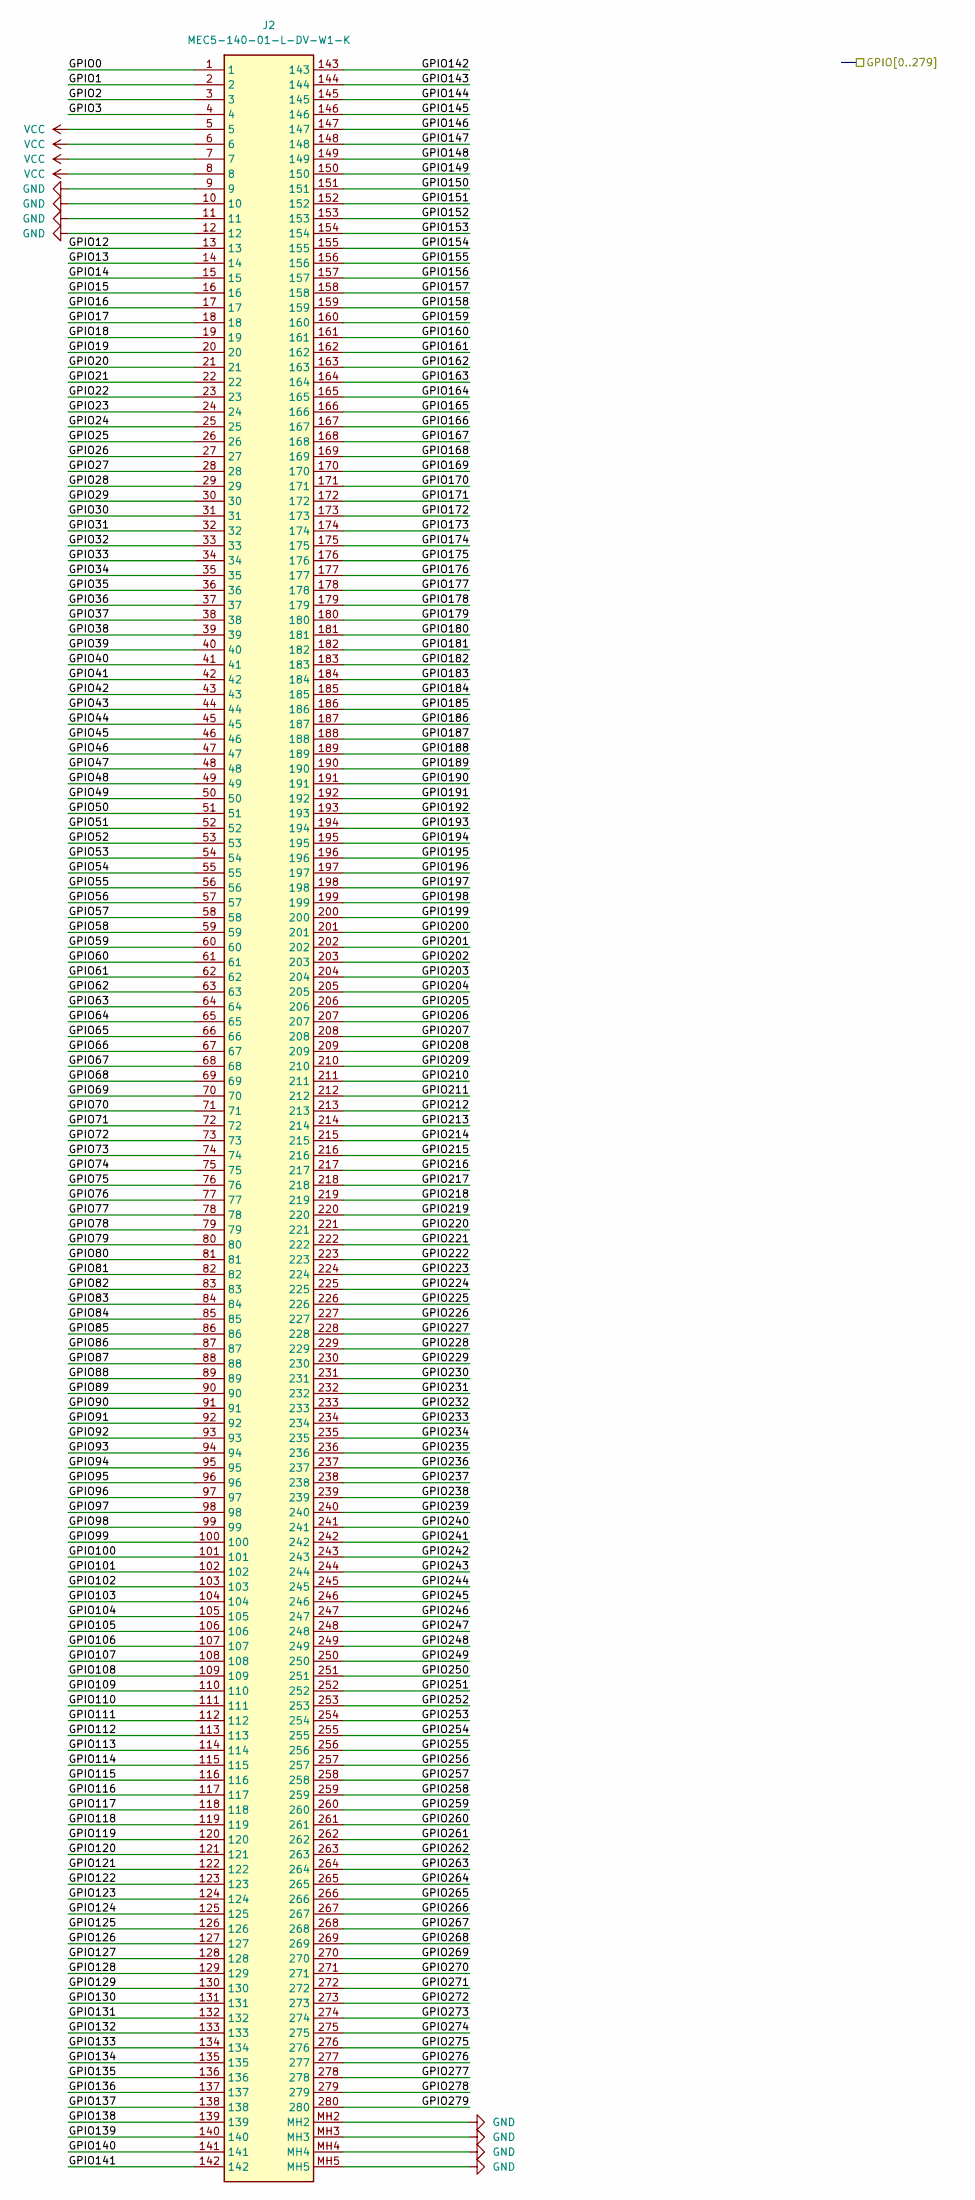
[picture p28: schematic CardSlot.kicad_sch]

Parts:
J2: MEC5-140-01-L-DV-W1-K; MEC514001LDVW1K; Mouser Part Number 200-MEC514001LDVW1K

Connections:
/GPIO0: J2.1; also elsewhere on the board
/GPIO1: J2.2; also elsewhere on the board
/GPIO2: J2.3; also elsewhere on the board
/GPIO3: J2.4; also elsewhere on the board
/GPIO12: J2.13; also elsewhere on the board
/GPIO13: J2.14; also elsewhere on the board
/GPIO14: J2.15; also elsewhere on the board
/GPIO15: J2.16; also elsewhere on the board
/GPIO16: J2.17; also elsewhere on the board
/GPIO17: J2.18; also elsewhere on the board
/GPIO18: J2.19; also elsewhere on the board
/GPIO19: J2.20; also elsewhere on the board
/GPIO20: J2.21; also elsewhere on the board
/GPIO21: J2.22; also elsewhere on the board
/GPIO22: J2.23; also elsewhere on the board
/GPIO23: J2.24; also elsewhere on the board
/GPIO24: J2.25; also elsewhere on the board
/GPIO25: J2.26; also elsewhere on the board
/GPIO26: J2.27; also elsewhere on the board
/GPIO27: J2.28; also elsewhere on the board
/GPIO28: J2.29; also elsewhere on the board
/GPIO29: J2.30; also elsewhere on the board
/GPIO30: J2.31; also elsewhere on the board
/GPIO31: J2.32; also elsewhere on the board
/GPIO32: J2.33; also elsewhere on the board
/GPIO33: J2.34; also elsewhere on the board
/GPIO34: J2.35; also elsewhere on the board
/GPIO35: J2.36; also elsewhere on the board
/GPIO36: J2.37; also elsewhere on the board
/GPIO37: J2.38; also elsewhere on the board
/GPIO38: J2.39; also elsewhere on the board
/GPIO39: J2.40; also elsewhere on the board
/GPIO40: J2.41; also elsewhere on the board
/GPIO41: J2.42; also elsewhere on the board
/GPIO42: J2.43; also elsewhere on the board
/GPIO43: J2.44; also elsewhere on the board
/GPIO44: J2.45; also elsewhere on the board
/GPIO45: J2.46; also elsewhere on the board
/GPIO46: J2.47; also elsewhere on the board
/GPIO47: J2.48; also elsewhere on the board
/GPIO48: J2.49; also elsewhere on the board
/GPIO49: J2.50; also elsewhere on the board
/GPIO50: J2.51; also elsewhere on the board
/GPIO51: J2.52; also elsewhere on the board
/GPIO52: J2.53; also elsewhere on the board
/GPIO53: J2.54; also elsewhere on the board
/GPIO54: J2.55; also elsewhere on the board
/GPIO55: J2.56; also elsewhere on the board
/GPIO56: J2.57; also elsewhere on the board
/GPIO57: J2.58; also elsewhere on the board
/GPIO58: J2.59; also elsewhere on the board
/GPIO59: J2.60; also elsewhere on the board
/GPIO60: J2.61; also elsewhere on the board
/GPIO61: J2.62; also elsewhere on the board
/GPIO62: J2.63; also elsewhere on the board
/GPIO63: J2.64; also elsewhere on the board
/GPIO64: J2.65; also elsewhere on the board
/GPIO65: J2.66; also elsewhere on the board
/GPIO66: J2.67; also elsewhere on the board
/GPIO67: J2.68; also elsewhere on the board
/GPIO68: J2.69; also elsewhere on the board
/GPIO69: J2.70; also elsewhere on the board
/GPIO70: J2.71; also elsewhere on the board
/GPIO71: J2.72; also elsewhere on the board
/GPIO72: J2.73; also elsewhere on the board
/GPIO73: J2.74; also elsewhere on the board
/GPIO74: J2.75; also elsewhere on the board
/GPIO75: J2.76; also elsewhere on the board
/GPIO76: J2.77; also elsewhere on the board
/GPIO77: J2.78; also elsewhere on the board
/GPIO78: J2.79; also elsewhere on the board
/GPIO79: J2.80; also elsewhere on the board
/GPIO80: J2.81; also elsewhere on the board
/GPIO81: J2.82; also elsewhere on the board
/GPIO82: J2.83; also elsewhere on the board
/GPIO83: J2.84; also elsewhere on the board
/GPIO84: J2.85; also elsewhere on the board
/GPIO85: J2.86; also elsewhere on the board
/GPIO86: J2.87; also elsewhere on the board
/GPIO87: J2.88; also elsewhere on the board
/GPIO88: J2.89; also elsewhere on the board
/GPIO89: J2.90; also elsewhere on the board
/GPIO90: J2.91; also elsewhere on the board
/GPIO91: J2.92; also elsewhere on the board
/GPIO92: J2.93; also elsewhere on the board
/GPIO93: J2.94; also elsewhere on the board
/GPIO94: J2.95; also elsewhere on the board
/GPIO95: J2.96; also elsewhere on the board
/GPIO96: J2.97; also elsewhere on the board
/GPIO97: J2.98; also elsewhere on the board
/GPIO98: J2.99; also elsewhere on the board
/GPIO99: J2.100; also elsewhere on the board
/GPIO100: J2.101; also elsewhere on the board
/GPIO101: J2.102; also elsewhere on the board
/GPIO102: J2.103; also elsewhere on the board
/GPIO103: J2.104; also elsewhere on the board
/GPIO104: J2.105; also elsewhere on the board
/GPIO105: J2.106; also elsewhere on the board
/GPIO106: J2.107; also elsewhere on the board
/GPIO107: J2.108; also elsewhere on the board
/GPIO108: J2.109; also elsewhere on the board
/GPIO109: J2.110; also elsewhere on the board
/GPIO110: J2.111; also elsewhere on the board
/GPIO111: J2.112; also elsewhere on the board
/GPIO112: J2.113; also elsewhere on the board
/GPIO113: J2.114; also elsewhere on the board
/GPIO114: J2.115; also elsewhere on the board
/GPIO115: J2.116; also elsewhere on the board
/GPIO116: J2.117; also elsewhere on the board
/GPIO117: J2.118; also elsewhere on the board
/GPIO118: J2.119; also elsewhere on the board
/GPIO119: J2.120; also elsewhere on the board
/GPIO120: J2.121; also elsewhere on the board
/GPIO121: J2.122; also elsewhere on the board
/GPIO122: J2.123; also elsewhere on the board
/GPIO123: J2.124; also elsewhere on the board
/GPIO124: J2.125; also elsewhere on the board
/GPIO125: J2.126; also elsewhere on the board
/GPIO126: J2.127; also elsewhere on the board
/GPIO127: J2.128; also elsewhere on the board
/GPIO128: J2.129; also elsewhere on the board
/GPIO129: J2.130; also elsewhere on the board
/GPIO130: J2.131; also elsewhere on the board
/GPIO131: J2.132; also elsewhere on the board
/GPIO132: J2.133; also elsewhere on the board
/GPIO133: J2.134; also elsewhere on the board
/GPIO134: J2.135; also elsewhere on the board
/GPIO135: J2.136; also elsewhere on the board
/GPIO136: J2.137; also elsewhere on the board
/GPIO137: J2.138; also elsewhere on the board
/GPIO138: J2.139; also elsewhere on the board
/GPIO139: J2.140; also elsewhere on the board
/GPIO140: J2.141; also elsewhere on the board
/GPIO141: J2.142; also elsewhere on the board
/GPIO142: J2.143; also elsewhere on the board
/GPIO143: J2.144; also elsewhere on the board
/GPIO144: J2.145; also elsewhere on the board
/GPIO145: J2.146; also elsewhere on the board
/GPIO146: J2.147; also elsewhere on the board
/GPIO147: J2.148; also elsewhere on the board
/GPIO148: J2.149; also elsewhere on the board
/GPIO149: J2.150; also elsewhere on the board
/GPIO150: J2.151; also elsewhere on the board
/GPIO151: J2.152; also elsewhere on the board
/GPIO152: J2.153; also elsewhere on the board
/GPIO153: J2.154; also elsewhere on the board
/GPIO154: J2.155; also elsewhere on the board
/GPIO155: J2.156; also elsewhere on the board
/GPIO156: J2.157; also elsewhere on the board
/GPIO157: J2.158; also elsewhere on the board
/GPIO158: J2.159; also elsewhere on the board
/GPIO159: J2.160; also elsewhere on the board
/GPIO160: J2.161; also elsewhere on the board
/GPIO161: J2.162; also elsewhere on the board
/GPIO162: J2.163; also elsewhere on the board
/GPIO163: J2.164; also elsewhere on the board
/GPIO164: J2.165; also elsewhere on the board
/GPIO165: J2.166; also elsewhere on the board
/GPIO166: J2.167; also elsewhere on the board
/GPIO167: J2.168; also elsewhere on the board
/GPIO168: J2.169; also elsewhere on the board
/GPIO169: J2.170; also elsewhere on the board
/GPIO170: J2.171; also elsewhere on the board
/GPIO171: J2.172; also elsewhere on the board
/GPIO172: J2.173; also elsewhere on the board
/GPIO173: J2.174; also elsewhere on the board
/GPIO174: J2.175; also elsewhere on the board
/GPIO175: J2.176; also elsewhere on the board
/GPIO176: J2.177; also elsewhere on the board
/GPIO177: J2.178; also elsewhere on the board
/GPIO178: J2.179; also elsewhere on the board
/GPIO179: J2.180; also elsewhere on the board
/GPIO180: J2.181; also elsewhere on the board
/GPIO181: J2.182; also elsewhere on the board
/GPIO182: J2.183; also elsewhere on the board
/GPIO183: J2.184; also elsewhere on the board
/GPIO184: J2.185; also elsewhere on the board
/GPIO185: J2.186; also elsewhere on the board
/GPIO186: J2.187; also elsewhere on the board
/GPIO187: J2.188; also elsewhere on the board
/GPIO188: J2.189; also elsewhere on the board
/GPIO189: J2.190; also elsewhere on the board
/GPIO190: J2.191; also elsewhere on the board
/GPIO191: J2.192; also elsewhere on the board
/GPIO192: J2.193; also elsewhere on the board
/GPIO193: J2.194; also elsewhere on the board
/GPIO194: J2.195; also elsewhere on the board
/GPIO195: J2.196; also elsewhere on the board
/GPIO196: J2.197; also elsewhere on the board
/GPIO197: J2.198; also elsewhere on the board
/GPIO198: J2.199; also elsewhere on the board
/GPIO199: J2.200; also elsewhere on the board
/GPIO200: J2.201; also elsewhere on the board
/GPIO201: J2.202; also elsewhere on the board
/GPIO202: J2.203; also elsewhere on the board
/GPIO203: J2.204; also elsewhere on the board
/GPIO204: J2.205; also elsewhere on the board
/GPIO205: J2.206; also elsewhere on the board
/GPIO206: J2.207; also elsewhere on the board
/GPIO207: J2.208; also elsewhere on the board
/GPIO208: J2.209; also elsewhere on the board
/GPIO209: J2.210; also elsewhere on the board
/GPIO210: J2.211; also elsewhere on the board
/GPIO211: J2.212; also elsewhere on the board
/GPIO212: J2.213; also elsewhere on the board
/GPIO213: J2.214; also elsewhere on the board
/GPIO214: J2.215; also elsewhere on the board
/GPIO215: J2.216; also elsewhere on the board
/GPIO216: J2.217; also elsewhere on the board
/GPIO217: J2.218; also elsewhere on the board
/GPIO218: J2.219; also elsewhere on the board
/GPIO219: J2.220; also elsewhere on the board
/GPIO220: J2.221; also elsewhere on the board
/GPIO221: J2.222; also elsewhere on the board
/GPIO222: J2.223; also elsewhere on the board
/GPIO223: J2.224; also elsewhere on the board
/GPIO224: J2.225; also elsewhere on the board
/GPIO225: J2.226; also elsewhere on the board
/GPIO226: J2.227; also elsewhere on the board
/GPIO227: J2.228; also elsewhere on the board
/GPIO228: J2.229; also elsewhere on the board
/GPIO229: J2.230; also elsewhere on the board
/GPIO230: J2.231; also elsewhere on the board
/GPIO231: J2.232; also elsewhere on the board
/GPIO232: J2.233; also elsewhere on the board
/GPIO233: J2.234; also elsewhere on the board
/GPIO234: J2.235; also elsewhere on the board
/GPIO235: J2.236; also elsewhere on the board
/GPIO236: J2.237; also elsewhere on the board
/GPIO237: J2.238; also elsewhere on the board
/GPIO238: J2.239; also elsewhere on the board
/GPIO239: J2.240; also elsewhere on the board
/GPIO240: J2.241; also elsewhere on the board
/GPIO241: J2.242; also elsewhere on the board
/GPIO242: J2.243; also elsewhere on the board
/GPIO243: J2.244; also elsewhere on the board
/GPIO244: J2.245; also elsewhere on the board
/GPIO245: J2.246; also elsewhere on the board
/GPIO246: J2.247; also elsewhere on the board
/GPIO247: J2.248; also elsewhere on the board
/GPIO248: J2.249; also elsewhere on the board
/GPIO249: J2.250; also elsewhere on the board
/GPIO250: J2.251; also elsewhere on the board
/GPIO251: J2.252; also elsewhere on the board
/GPIO252: J2.253; also elsewhere on the board
/GPIO253: J2.254; also elsewhere on the board
/GPIO254: J2.255; also elsewhere on the board
/GPIO255: J2.256; also elsewhere on the board
/GPIO256: J2.257; also elsewhere on the board
/GPIO257: J2.258; also elsewhere on the board
/GPIO258: J2.259; also elsewhere on the board
/GPIO259: J2.260; also elsewhere on the board
/GPIO260: J2.261; also elsewhere on the board
/GPIO261: J2.262; also elsewhere on the board
/GPIO262: J2.263; also elsewhere on the board
/GPIO263: J2.264; also elsewhere on the board
/GPIO264: J2.265; also elsewhere on the board
/GPIO265: J2.266; also elsewhere on the board
/GPIO266: J2.267; also elsewhere on the board
/GPIO267: J2.268; also elsewhere on the board
/GPIO268: J2.269; also elsewhere on the board
/GPIO269: J2.270; also elsewhere on the board
/GPIO270: J2.271; also elsewhere on the board
/GPIO271: J2.272; also elsewhere on the board
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

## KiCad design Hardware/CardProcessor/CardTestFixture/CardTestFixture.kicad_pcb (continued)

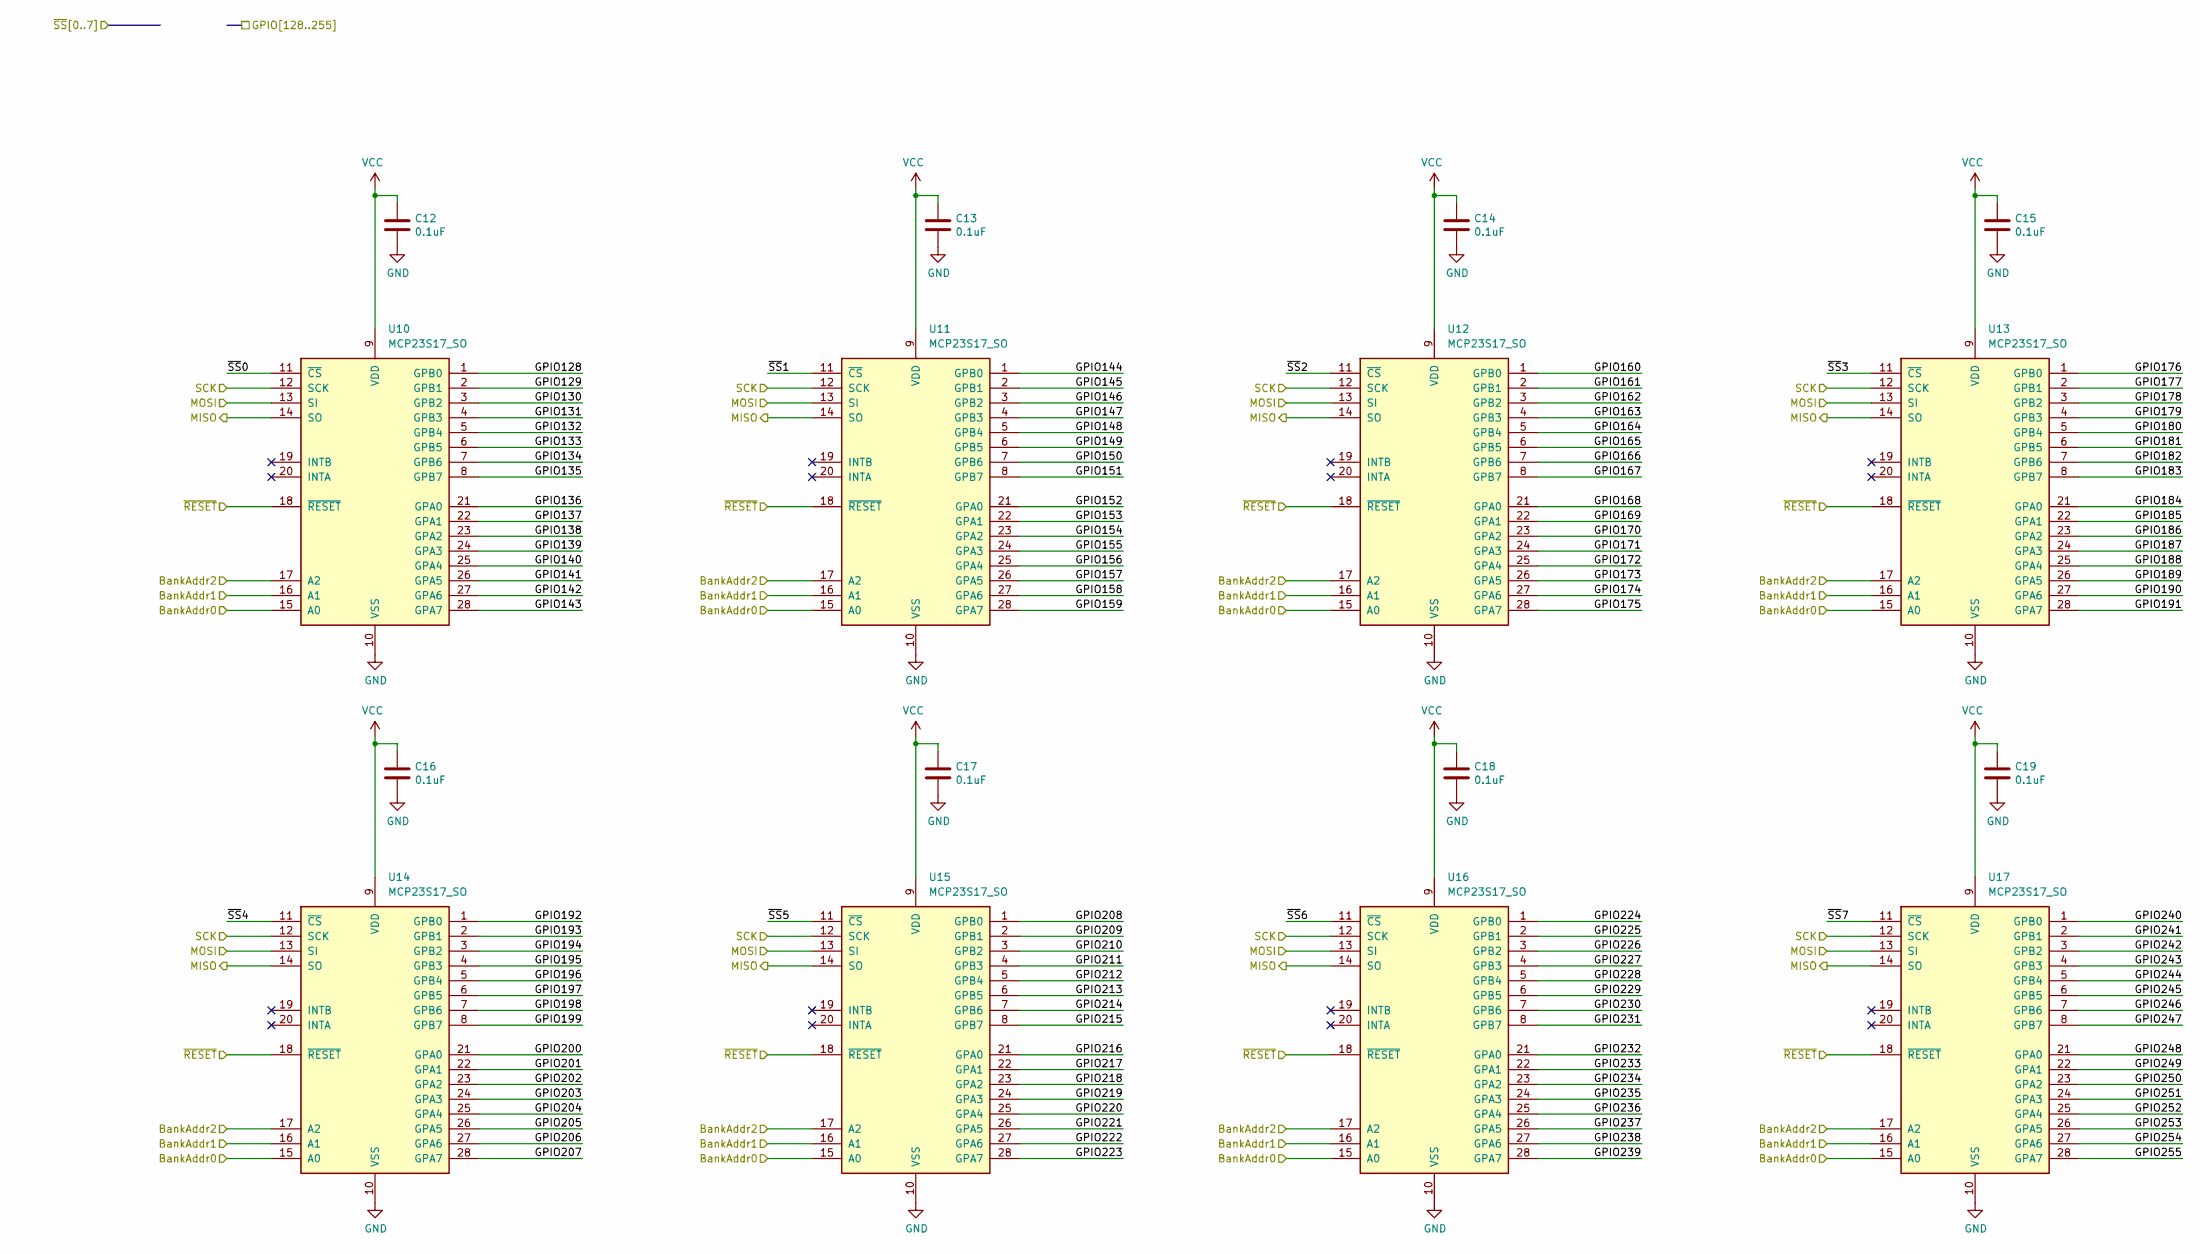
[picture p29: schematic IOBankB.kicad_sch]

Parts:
C12, C13, C14, C15, C16, C17, C18, C19: 0.1uF; C_0603_1608Metric; Manufacturer# EMK107B7104KAHT; Mouser# 963-EMK107B7104KAHT
U10, U11, U12, U13, U14, U15, U16, U17: MCP23S17_SO; SOIC-28W_7.5x17.9mm_P1.27mm

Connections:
/GPIO128: U10.1 (GPB0); also elsewhere on the board
/GPIO129: U10.2 (GPB1); also elsewhere on the board
/GPIO130: U10.3 (GPB2); also elsewhere on the board
/GPIO131: U10.4 (GPB3); also elsewhere on the board
/GPIO132: U10.5 (GPB4); also elsewhere on the board
/GPIO133: U10.6 (GPB5); also elsewhere on the board
/GPIO134: U10.7 (GPB6); also elsewhere on the board
/GPIO135: U10.8 (GPB7); also elsewhere on the board
/GPIO136: U10.21 (GPA0); also elsewhere on the board
/GPIO137: U10.22 (GPA1); also elsewhere on the board
/GPIO138: U10.23 (GPA2); also elsewhere on the board
/GPIO139: U10.24 (GPA3); also elsewhere on the board
/GPIO140: U10.25 (GPA4); also elsewhere on the board
/GPIO141: U10.26 (GPA5); also elsewhere on the board
/GPIO142: U10.27 (GPA6); also elsewhere on the board
/GPIO143: U10.28 (GPA7); also elsewhere on the board
/GPIO144: U11.1 (GPB0); also elsewhere on the board
/GPIO145: U11.2 (GPB1); also elsewhere on the board
/GPIO146: U11.3 (GPB2); also elsewhere on the board
/GPIO147: U11.4 (GPB3); also elsewhere on the board
/GPIO148: U11.5 (GPB4); also elsewhere on the board
/GPIO149: U11.6 (GPB5); also elsewhere on the board
/GPIO150: U11.7 (GPB6); also elsewhere on the board
/GPIO151: U11.8 (GPB7); also elsewhere on the board
/GPIO152: U11.21 (GPA0); also elsewhere on the board
/GPIO153: U11.22 (GPA1); also elsewhere on the board
/GPIO154: U11.23 (GPA2); also elsewhere on the board
/GPIO155: U11.24 (GPA3); also elsewhere on the board
/GPIO156: U11.25 (GPA4); also elsewhere on the board
/GPIO157: U11.26 (GPA5); also elsewhere on the board
/GPIO158: U11.27 (GPA6); also elsewhere on the board
/GPIO159: U11.28 (GPA7); also elsewhere on the board
/GPIO160: U12.1 (GPB0); also elsewhere on the board
/GPIO161: U12.2 (GPB1); also elsewhere on the board
/GPIO162: U12.3 (GPB2); also elsewhere on the board
/GPIO163: U12.4 (GPB3); also elsewhere on the board
/GPIO164: U12.5 (GPB4); also elsewhere on the board
/GPIO165: U12.6 (GPB5); also elsewhere on the board
/GPIO166: U12.7 (GPB6); also elsewhere on the board
/GPIO167: U12.8 (GPB7); also elsewhere on the board
/GPIO168: U12.21 (GPA0); also elsewhere on the board
/GPIO169: U12.22 (GPA1); also elsewhere on the board
/GPIO170: U12.23 (GPA2); also elsewhere on the board
/GPIO171: U12.24 (GPA3); also elsewhere on the board
/GPIO172: U12.25 (GPA4); also elsewhere on the board
/GPIO173: U12.26 (GPA5); also elsewhere on the board
/GPIO174: U12.27 (GPA6); also elsewhere on the board
/GPIO175: U12.28 (GPA7); also elsewhere on the board
/GPIO176: U13.1 (GPB0); also elsewhere on the board
/GPIO177: U13.2 (GPB1); also elsewhere on the board
/GPIO178: U13.3 (GPB2); also elsewhere on the board
/GPIO179: U13.4 (GPB3); also elsewhere on the board
/GPIO180: U13.5 (GPB4); also elsewhere on the board
/GPIO181: U13.6 (GPB5); also elsewhere on the board
/GPIO182: U13.7 (GPB6); also elsewhere on the board
/GPIO183: U13.8 (GPB7); also elsewhere on the board
/GPIO184: U13.21 (GPA0); also elsewhere on the board
/GPIO185: U13.22 (GPA1); also elsewhere on the board
/GPIO186: U13.23 (GPA2); also elsewhere on the board
/GPIO187: U13.24 (GPA3); also elsewhere on the board
/GPIO188: U13.25 (GPA4); also elsewhere on the board
/GPIO189: U13.26 (GPA5); also elsewhere on the board
/GPIO190: U13.27 (GPA6); also elsewhere on the board
/GPIO191: U13.28 (GPA7); also elsewhere on the board
/GPIO192: U14.1 (GPB0); also elsewhere on the board
/GPIO193: U14.2 (GPB1); also elsewhere on the board
/GPIO194: U14.3 (GPB2); also elsewhere on the board
/GPIO195: U14.4 (GPB3); also elsewhere on the board
/GPIO196: U14.5 (GPB4); also elsewhere on the board
/GPIO197: U14.6 (GPB5); also elsewhere on the board
/GPIO198: U14.7 (GPB6); also elsewhere on the board
/GPIO199: U14.8 (GPB7); also elsewhere on the board
/GPIO200: U14.21 (GPA0); also elsewhere on the board
/GPIO201: U14.22 (GPA1); also elsewhere on the board
/GPIO202: U14.23 (GPA2); also elsewhere on the board
/GPIO203: U14.24 (GPA3); also elsewhere on the board
/GPIO204: U14.25 (GPA4); also elsewhere on the board
/GPIO205: U14.26 (GPA5); also elsewhere on the board
/GPIO206: U14.27 (GPA6); also elsewhere on the board
/GPIO207: U14.28 (GPA7); also elsewhere on the board
/GPIO208: U15.1 (GPB0); also elsewhere on the board
/GPIO209: U15.2 (GPB1); also elsewhere on the board
/GPIO210: U15.3 (GPB2); also elsewhere on the board
/GPIO211: U15.4 (GPB3); also elsewhere on the board
/GPIO212: U15.5 (GPB4); also elsewhere on the board
/GPIO213: U15.6 (GPB5); also elsewhere on the board
/GPIO214: U15.7 (GPB6); also elsewhere on the board
/GPIO215: U15.8 (GPB7); also elsewhere on the board
/GPIO216: U15.21 (GPA0); also elsewhere on the board
/GPIO217: U15.22 (GPA1); also elsewhere on the board
/GPIO218: U15.23 (GPA2); also elsewhere on the board
/GPIO219: U15.24 (GPA3); also elsewhere on the board
/GPIO220: U15.25 (GPA4); also elsewhere on the board
/GPIO221: U15.26 (GPA5); also elsewhere on the board
/GPIO222: U15.27 (GPA6); also elsewhere on the board
/GPIO223: U15.28 (GPA7); also elsewhere on the board
/GPIO224: U16.1 (GPB0); also elsewhere on the board
/GPIO225: U16.2 (GPB1); also elsewhere on the board
/GPIO226: U16.3 (GPB2); also elsewhere on the board
/GPIO227: U16.4 (GPB3); also elsewhere on the board
/GPIO228: U16.5 (GPB4); also elsewhere on the board
/GPIO229: U16.6 (GPB5); also elsewhere on the board
/GPIO230: U16.7 (GPB6); also elsewhere on the board
/GPIO231: U16.8 (GPB7); also elsewhere on the board
/GPIO232: U16.21 (GPA0); also elsewhere on the board
/GPIO233: U16.22 (GPA1); also elsewhere on the board
/GPIO234: U16.23 (GPA2); also elsewhere on the board
/GPIO235: U16.24 (GPA3); also elsewhere on the board
/GPIO236: U16.25 (GPA4); also elsewhere on the board
/GPIO237: U16.26 (GPA5); also elsewhere on the board
/GPIO238: U16.27 (GPA6); also elsewhere on the board
/GPIO239: U16.28 (GPA7); also elsewhere on the board
/GPIO240: U17.1 (GPB0); also elsewhere on the board
/GPIO241: U17.2 (GPB1); also elsewhere on the board
/GPIO242: U17.3 (GPB2); also elsewhere on the board
/GPIO243: U17.4 (GPB3); also elsewhere on the board
/GPIO244: U17.5 (GPB4); also elsewhere on the board
/GPIO245: U17.6 (GPB5); also elsewhere on the board
/GPIO246: U17.7 (GPB6); also elsewhere on the board
/GPIO247: U17.8 (GPB7); also elsewhere on the board
/GPIO248: U17.21 (GPA0); also elsewhere on the board
/GPIO249: U17.22 (GPA1); also elsewhere on the board
/GPIO250: U17.23 (GPA2); also elsewhere on the board
/GPIO251: U17.24 (GPA3); also elsewhere on the board
/GPIO252: U17.25 (GPA4); also elsewhere on the board
/GPIO253: U17.26 (GPA5); also elsewhere on the board
/GPIO254: U17.27 (GPA6); also elsewhere on the board
/GPIO255: U17.28 (GPA7); also elsewhere on the board
/MISO: U10.14 (SO), U11.14 (SO), U12.14 (SO), U13.14 (SO), U14.14 (SO), U15.14 (SO), U16.14 (SO), U17.14 (SO); also elsewhere on the board
/MOSI: U10.13 (SI), U11.13 (SI), U12.13 (SI), U13.13 (SI), U14.13 (SI), U15.13 (SI), U16.13 (SI), U17.13 (SI); also elsewhere on the board
/SCK: U10.12 (SCK), U11.12 (SCK), U12.12 (SCK), U13.12 (SCK), U14.12 (SCK), U15.12 (SCK), U16.12 (SCK), U17.12 (SCK); also elsewhere on the board
/~RESET: U10.18 (~RESET), U11.18 (~RESET), U12.18 (~RESET), U13.18 (~RESET), U14.18 (~RESET), U15.18 (~RESET), U16.18 (~RESET), U17.18 (~RESET); also elsewhere on the board
/~SS0: U10.11 (~CS); also elsewhere on the board
/~SS1: U11.11 (~CS); also elsewhere on the board
/~SS2: U12.11 (~CS); also elsewhere on the board
/~SS3: U13.11 (~CS); also elsewhere on the board
/~SS4: U14.11 (~CS); also elsewhere on the board
/~SS5: U15.11 (~CS); also elsewhere on the board
/~SS6: U16.11 (~CS); also elsewhere on the board
/~SS7: U17.11 (~CS); also elsewhere on the board
GND: C12.2, C13.2, C14.2, C15.2, C16.2, C17.2, C18.2, C19.2, U10.10 (VSS), U10.16 (A1), U10.17 (A2), U11.10 (VSS), U11.16 (A1), U11.17 (A2), U12.10 (VSS), U12.16 (A1), U12.17 (A2), U13.10 (VSS), U13.16 (A1), U13.17 (A2), U14.10 (VSS), U14.16 (A1), U14.17 (A2), U15.10 (VSS), U15.16 (A1), U15.17 (A2), U16.10 (VSS), U16.16 (A1), U16.17 (A2), U17.10 (VSS), U17.16 (A1), U17.17 (A2); also elsewhere on the board
VCC: C12.1, C13.1, C14.1, C15.1, C16.1, C17.1, C18.1, C19.1, U10.9 (VDD), U10.15 (A0), U11.9 (VDD), U11.15 (A0), U12.9 (VDD), U12.15 (A0), U13.9 (VDD), U13.15 (A0), U14.9 (VDD), U14.15 (A0), U15.9 (VDD), U15.15 (A0), U16.9 (VDD), U16.15 (A0), U17.9 (VDD), U17.15 (A0); also elsewhere on the board

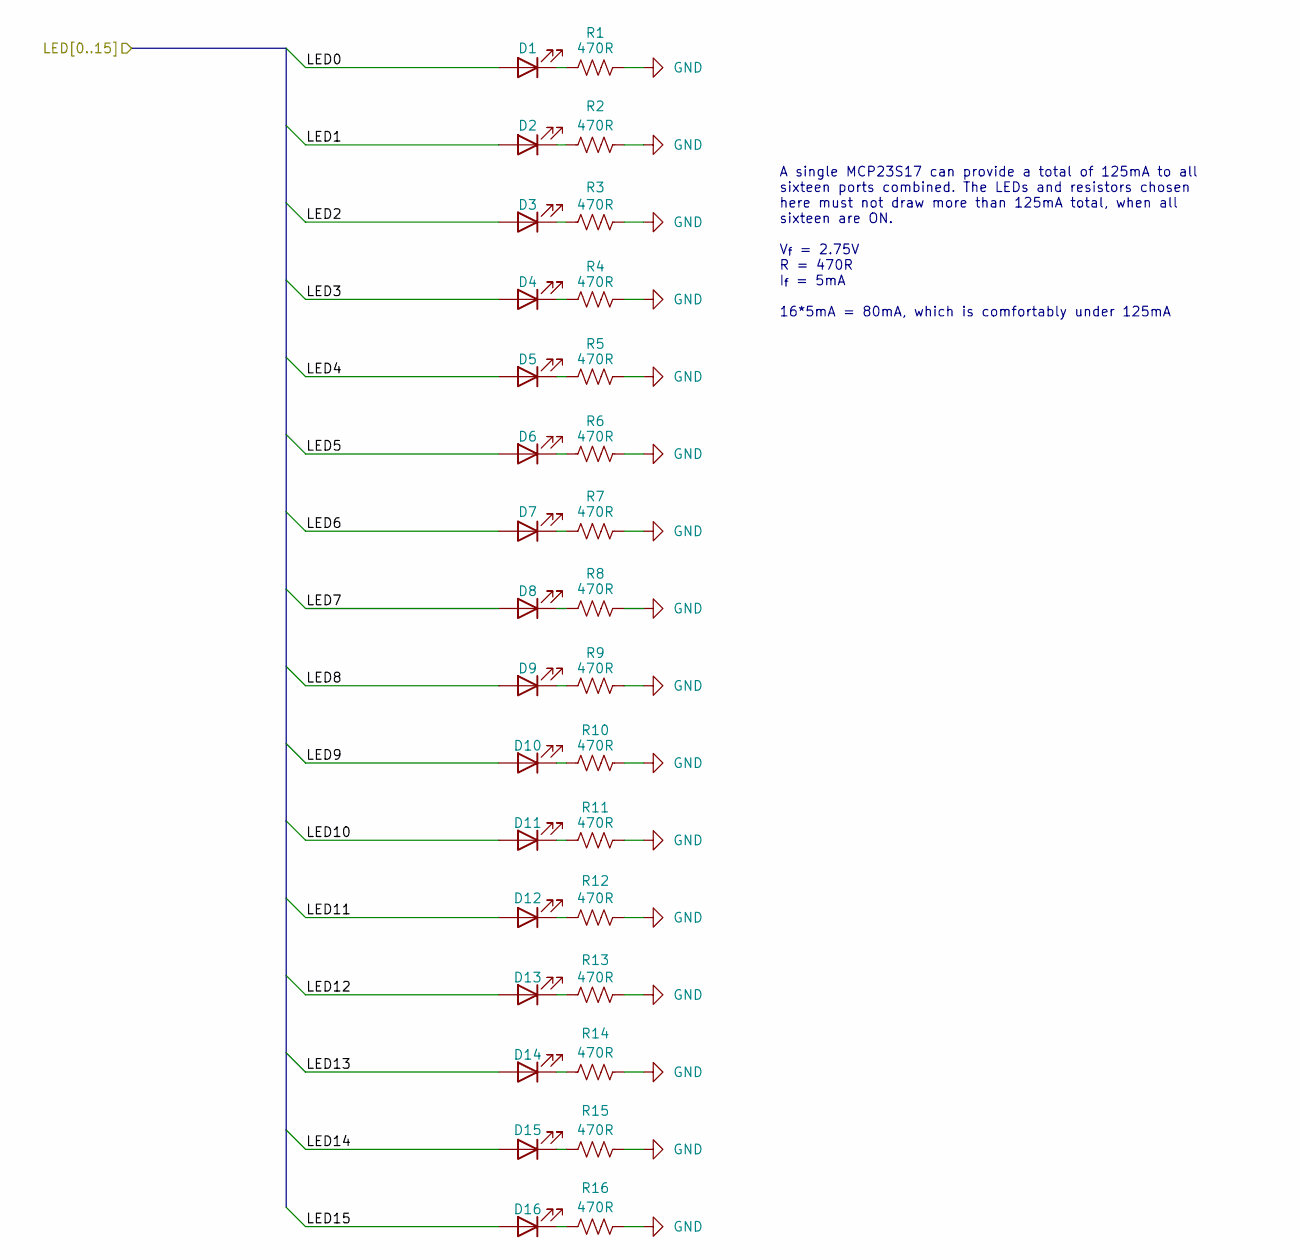
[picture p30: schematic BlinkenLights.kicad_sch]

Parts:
D1, D2, D3, D4, D5, D6, D7, D8, D9, D10, D11, D12, D13, D14, D15, D16: LED_0603_1608Metric
R1, R2, R3, R4, R5, R6, R7, R8, R9, R10, R11, R12, R13, R14, R15, R16: 470R; C_0603_1608Metric

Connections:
/GPIO280: D1.2 (A); also elsewhere on the board
/GPIO281: D2.2 (A); also elsewhere on the board
/GPIO282: D3.2 (A); also elsewhere on the board
/GPIO283: D4.2 (A); also elsewhere on the board
/GPIO284: D5.2 (A); also elsewhere on the board
/GPIO285: D6.2 (A); also elsewhere on the board
/GPIO286: D7.2 (A); also elsewhere on the board
/GPIO287: D8.2 (A); also elsewhere on the board
/GPIO288: D9.2 (A); also elsewhere on the board
/GPIO289: D10.2 (A); also elsewhere on the board
/GPIO290: D11.2 (A); also elsewhere on the board
/GPIO291: D12.2 (A); also elsewhere on the board
/GPIO292: D13.2 (A); also elsewhere on the board
/GPIO293: D14.2 (A); also elsewhere on the board
/GPIO294: D15.2 (A); also elsewhere on the board
/GPIO295: D16.2 (A); also elsewhere on the board
GND: R1.2, R2.2, R3.2, R4.2, R5.2, R6.2, R7.2, R8.2, R9.2, R10.2, R11.2, R12.2, R13.2, R14.2, R15.2, R16.2; also elsewhere on the board
unnamed: D1.1 (K), R1.1
unnamed: D2.1 (K), R2.1
unnamed: D3.1 (K), R3.1
unnamed: D4.1 (K), R4.1
unnamed: D5.1 (K), R5.1
unnamed: D6.1 (K), R6.1
unnamed: D7.1 (K), R7.1
unnamed: D8.1 (K), R8.1
unnamed: D9.1 (K), R9.1
unnamed: D10.1 (K), R10.1
unnamed: D11.1 (K), R11.1
unnamed: D12.1 (K), R12.1
unnamed: D13.1 (K), R13.1
unnamed: D14.1 (K), R14.1
unnamed: D15.1 (K), R15.1
unnamed: D16.1 (K), R16.1

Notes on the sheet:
A single MCP23S17 can provide a total of 125mA to all sixteen ports combined. The LEDs and resistors chosen here must not draw more than 125mA total, when all sixteen are ON. V_{f} = 2.75V R = 470R I_{f} = 5mA 16*5mA = 80mA, which is comfortably under 125mA

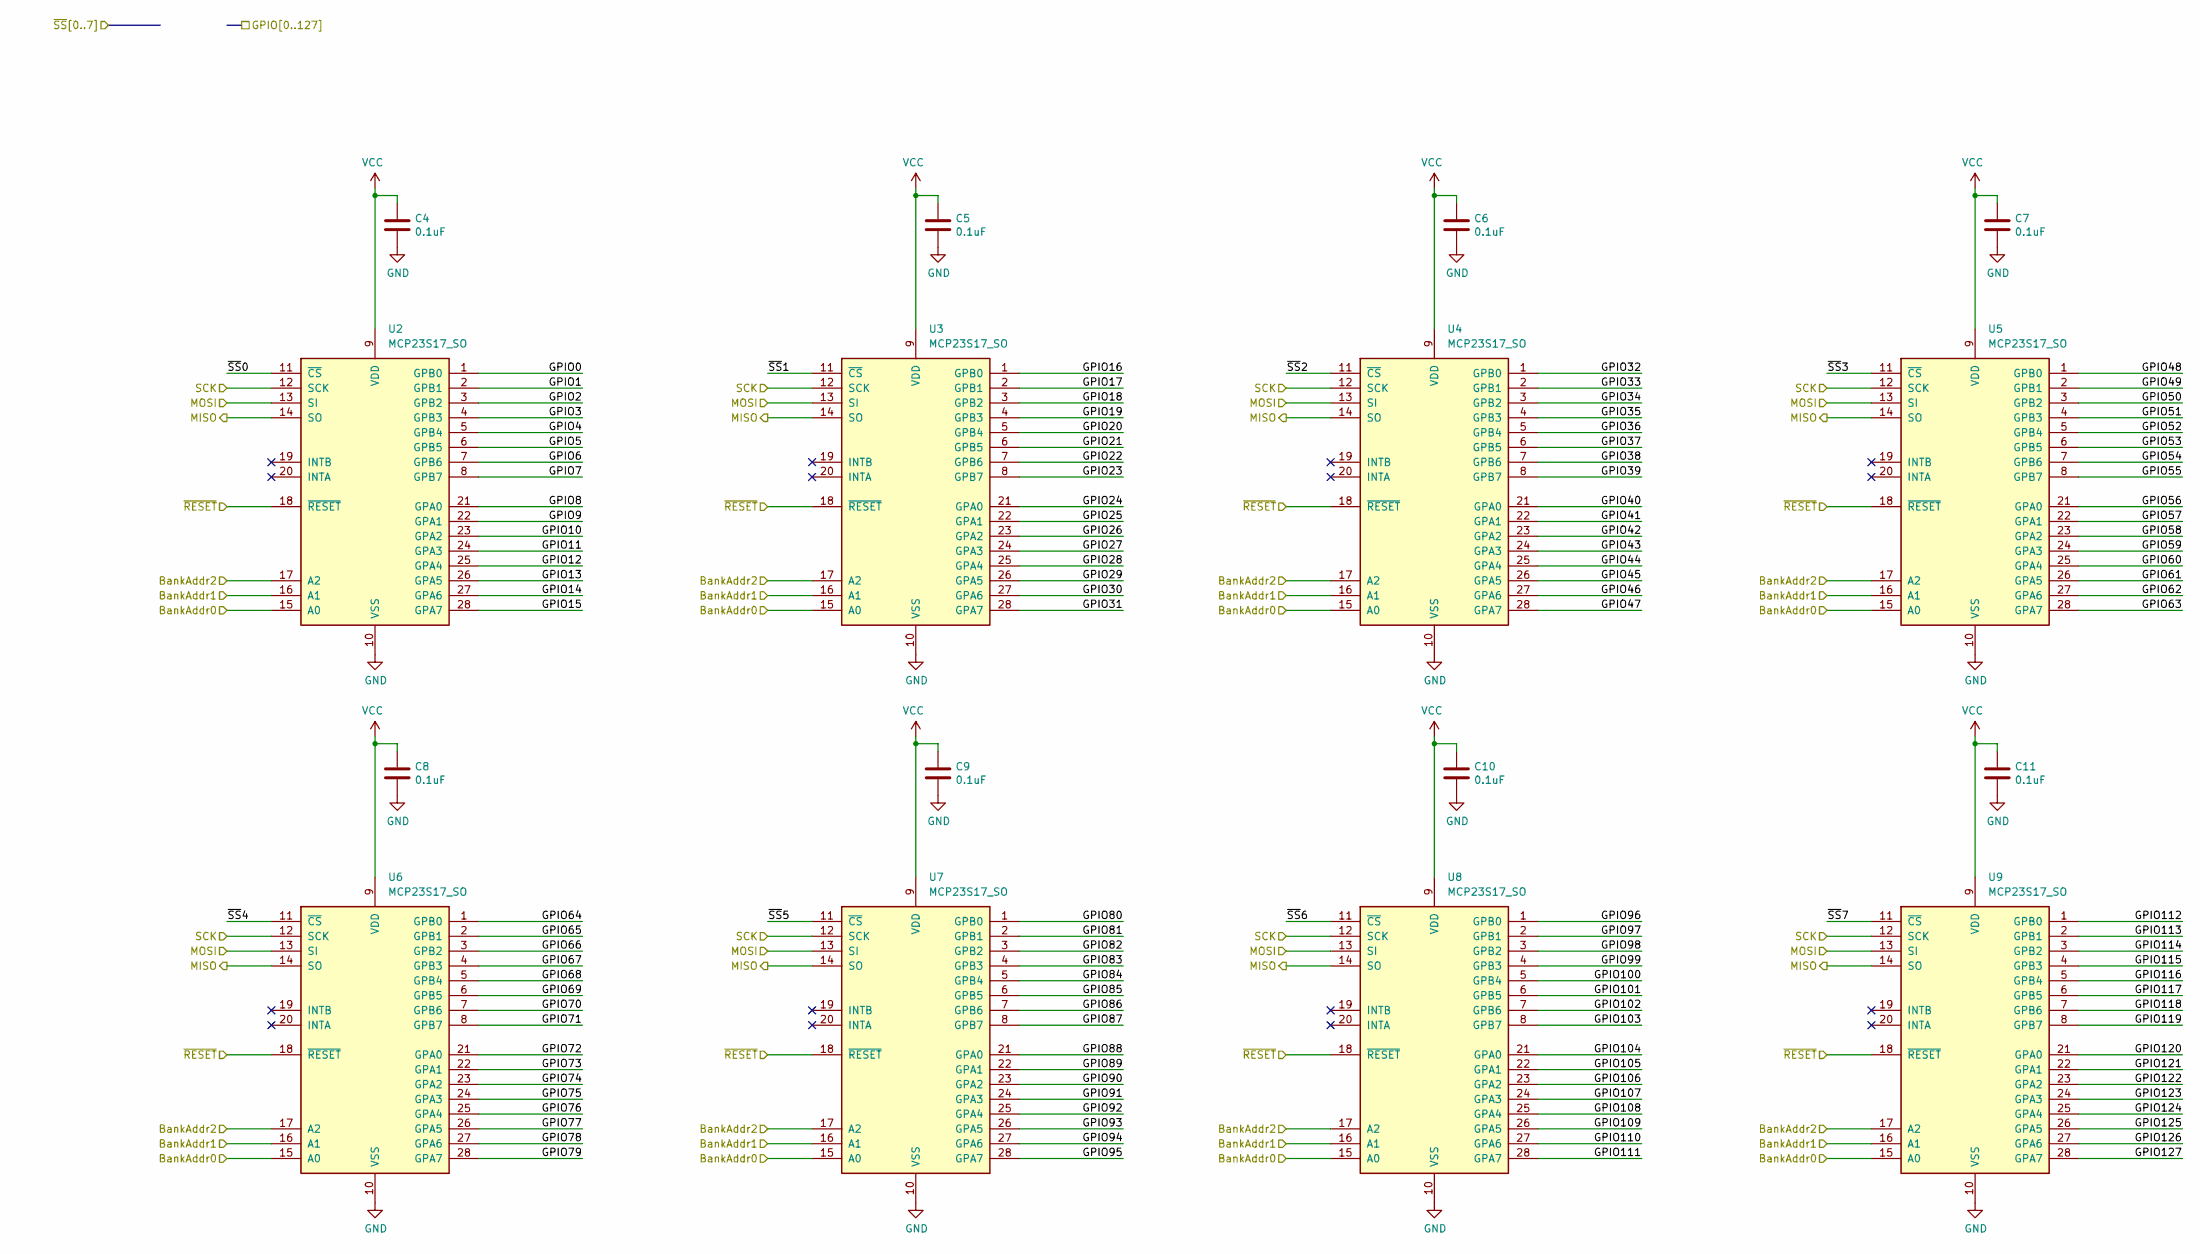
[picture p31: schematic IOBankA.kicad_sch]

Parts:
C4, C5, C6, C7, C8, C9, C10, C11: 0.1uF; C_0603_1608Metric; Manufacturer# EMK107B7104KAHT; Mouser# 963-EMK107B7104KAHT
U2, U3, U4, U5, U6, U7, U8, U9: MCP23S17_SO; SOIC-28W_7.5x17.9mm_P1.27mm

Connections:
/GPIO0: U2.1 (GPB0); also elsewhere on the board
/GPIO1: U2.2 (GPB1); also elsewhere on the board
/GPIO2: U2.3 (GPB2); also elsewhere on the board
/GPIO3: U2.4 (GPB3); also elsewhere on the board
/GPIO4: U2.5 (GPB4)
/GPIO5: U2.6 (GPB5)
/GPIO6: U2.7 (GPB6)
/GPIO7: U2.8 (GPB7)
/GPIO8: U2.21 (GPA0)
/GPIO9: U2.22 (GPA1)
/GPIO10: U2.23 (GPA2)
/GPIO11: U2.24 (GPA3); also elsewhere on the board
/GPIO12: U2.25 (GPA4); also elsewhere on the board
/GPIO13: U2.26 (GPA5); also elsewhere on the board
/GPIO14: U2.27 (GPA6); also elsewhere on the board
/GPIO15: U2.28 (GPA7); also elsewhere on the board
/GPIO16: U3.1 (GPB0); also elsewhere on the board
/GPIO17: U3.2 (GPB1); also elsewhere on the board
/GPIO18: U3.3 (GPB2); also elsewhere on the board
/GPIO19: U3.4 (GPB3); also elsewhere on the board
/GPIO20: U3.5 (GPB4); also elsewhere on the board
/GPIO21: U3.6 (GPB5); also elsewhere on the board
/GPIO22: U3.7 (GPB6); also elsewhere on the board
/GPIO23: U3.8 (GPB7); also elsewhere on the board
/GPIO24: U3.21 (GPA0); also elsewhere on the board
/GPIO25: U3.22 (GPA1); also elsewhere on the board
/GPIO26: U3.23 (GPA2); also elsewhere on the board
/GPIO27: U3.24 (GPA3); also elsewhere on the board
/GPIO28: U3.25 (GPA4); also elsewhere on the board
/GPIO29: U3.26 (GPA5); also elsewhere on the board
/GPIO30: U3.27 (GPA6); also elsewhere on the board
/GPIO31: U3.28 (GPA7); also elsewhere on the board
/GPIO32: U4.1 (GPB0); also elsewhere on the board
/GPIO33: U4.2 (GPB1); also elsewhere on the board
/GPIO34: U4.3 (GPB2); also elsewhere on the board
/GPIO35: U4.4 (GPB3); also elsewhere on the board
/GPIO36: U4.5 (GPB4); also elsewhere on the board
/GPIO37: U4.6 (GPB5); also elsewhere on the board
/GPIO38: U4.7 (GPB6); also elsewhere on the board
/GPIO39: U4.8 (GPB7); also elsewhere on the board
/GPIO40: U4.21 (GPA0); also elsewhere on the board
/GPIO41: U4.22 (GPA1); also elsewhere on the board
/GPIO42: U4.23 (GPA2); also elsewhere on the board
/GPIO43: U4.24 (GPA3); also elsewhere on the board
/GPIO44: U4.25 (GPA4); also elsewhere on the board
/GPIO45: U4.26 (GPA5); also elsewhere on the board
/GPIO46: U4.27 (GPA6); also elsewhere on the board
/GPIO47: U4.28 (GPA7); also elsewhere on the board
/GPIO48: U5.1 (GPB0); also elsewhere on the board
/GPIO49: U5.2 (GPB1); also elsewhere on the board
/GPIO50: U5.3 (GPB2); also elsewhere on the board
/GPIO51: U5.4 (GPB3); also elsewhere on the board
/GPIO52: U5.5 (GPB4); also elsewhere on the board
/GPIO53: U5.6 (GPB5); also elsewhere on the board
/GPIO54: U5.7 (GPB6); also elsewhere on the board
/GPIO55: U5.8 (GPB7); also elsewhere on the board
/GPIO56: U5.21 (GPA0); also elsewhere on the board
/GPIO57: U5.22 (GPA1); also elsewhere on the board
/GPIO58: U5.23 (GPA2); also elsewhere on the board
/GPIO59: U5.24 (GPA3); also elsewhere on the board
/GPIO60: U5.25 (GPA4); also elsewhere on the board
/GPIO61: U5.26 (GPA5); also elsewhere on the board
/GPIO62: U5.27 (GPA6); also elsewhere on the board
/GPIO63: U5.28 (GPA7); also elsewhere on the board
/GPIO64: U6.1 (GPB0); also elsewhere on the board
/GPIO65: U6.2 (GPB1); also elsewhere on the board
/GPIO66: U6.3 (GPB2); also elsewhere on the board
/GPIO67: U6.4 (GPB3); also elsewhere on the board
/GPIO68: U6.5 (GPB4); also elsewhere on the board
/GPIO69: U6.6 (GPB5); also elsewhere on the board
/GPIO70: U6.7 (GPB6); also elsewhere on the board
/GPIO71: U6.8 (GPB7); also elsewhere on the board
/GPIO72: U6.21 (GPA0); also elsewhere on the board
/GPIO73: U6.22 (GPA1); also elsewhere on the board
/GPIO74: U6.23 (GPA2); also elsewhere on the board
/GPIO75: U6.24 (GPA3); also elsewhere on the board
/GPIO76: U6.25 (GPA4); also elsewhere on the board
/GPIO77: U6.26 (GPA5); also elsewhere on the board
/GPIO78: U6.27 (GPA6); also elsewhere on the board
/GPIO79: U6.28 (GPA7); also elsewhere on the board
/GPIO80: U7.1 (GPB0); also elsewhere on the board
/GPIO81: U7.2 (GPB1); also elsewhere on the board
/GPIO82: U7.3 (GPB2); also elsewhere on the board
/GPIO83: U7.4 (GPB3); also elsewhere on the board
/GPIO84: U7.5 (GPB4); also elsewhere on the board
/GPIO85: U7.6 (GPB5); also elsewhere on the board
/GPIO86: U7.7 (GPB6); also elsewhere on the board
/GPIO87: U7.8 (GPB7); also elsewhere on the board
/GPIO88: U7.21 (GPA0); also elsewhere on the board
/GPIO89: U7.22 (GPA1); also elsewhere on the board
/GPIO90: U7.23 (GPA2); also elsewhere on the board
/GPIO91: U7.24 (GPA3); also elsewhere on the board
/GPIO92: U7.25 (GPA4); also elsewhere on the board
/GPIO93: U7.26 (GPA5); also elsewhere on the board
/GPIO94: U7.27 (GPA6); also elsewhere on the board
/GPIO95: U7.28 (GPA7); also elsewhere on the board
/GPIO96: U8.1 (GPB0); also elsewhere on the board
/GPIO97: U8.2 (GPB1); also elsewhere on the board
/GPIO98: U8.3 (GPB2); also elsewhere on the board
/GPIO99: U8.4 (GPB3); also elsewhere on the board
/GPIO100: U8.5 (GPB4); also elsewhere on the board
/GPIO101: U8.6 (GPB5); also elsewhere on the board
/GPIO102: U8.7 (GPB6); also elsewhere on the board
/GPIO103: U8.8 (GPB7); also elsewhere on the board
/GPIO104: U8.21 (GPA0); also elsewhere on the board
/GPIO105: U8.22 (GPA1); also elsewhere on the board
/GPIO106: U8.23 (GPA2); also elsewhere on the board
/GPIO107: U8.24 (GPA3); also elsewhere on the board
/GPIO108: U8.25 (GPA4); also elsewhere on the board
/GPIO109: U8.26 (GPA5); also elsewhere on the board
/GPIO110: U8.27 (GPA6); also elsewhere on the board
/GPIO111: U8.28 (GPA7); also elsewhere on the board
/GPIO112: U9.1 (GPB0); also elsewhere on the board
/GPIO113: U9.2 (GPB1); also elsewhere on the board
/GPIO114: U9.3 (GPB2); also elsewhere on the board
/GPIO115: U9.4 (GPB3); also elsewhere on the board
/GPIO116: U9.5 (GPB4); also elsewhere on the board
/GPIO117: U9.6 (GPB5); also elsewhere on the board
/GPIO118: U9.7 (GPB6); also elsewhere on the board
/GPIO119: U9.8 (GPB7); also elsewhere on the board
/GPIO120: U9.21 (GPA0); also elsewhere on the board
/GPIO121: U9.22 (GPA1); also elsewhere on the board
/GPIO122: U9.23 (GPA2); also elsewhere on the board
/GPIO123: U9.24 (GPA3); also elsewhere on the board
/GPIO124: U9.25 (GPA4); also elsewhere on the board
/GPIO125: U9.26 (GPA5); also elsewhere on the board
/GPIO126: U9.27 (GPA6); also elsewhere on the board
/GPIO127: U9.28 (GPA7); also elsewhere on the board
/MISO: U2.14 (SO), U3.14 (SO), U4.14 (SO), U5.14 (SO), U6.14 (SO), U7.14 (SO), U8.14 (SO), U9.14 (SO); also elsewhere on the board
/MOSI: U2.13 (SI), U3.13 (SI), U4.13 (SI), U5.13 (SI), U6.13 (SI), U7.13 (SI), U8.13 (SI), U9.13 (SI); also elsewhere on the board
/SCK: U2.12 (SCK), U3.12 (SCK), U4.12 (SCK), U5.12 (SCK), U6.12 (SCK), U7.12 (SCK), U8.12 (SCK), U9.12 (SCK); also elsewhere on the board
/~RESET: U2.18 (~RESET), U3.18 (~RESET), U4.18 (~RESET), U5.18 (~RESET), U6.18 (~RESET), U7.18 (~RESET), U8.18 (~RESET), U9.18 (~RESET); also elsewhere on the board
/~SS0: U2.11 (~CS); also elsewhere on the board
/~SS1: U3.11 (~CS); also elsewhere on the board
/~SS2: U4.11 (~CS); also elsewhere on the board
/~SS3: U5.11 (~CS); also elsewhere on the board
/~SS4: U6.11 (~CS); also elsewhere on the board
/~SS5: U7.11 (~CS); also elsewhere on the board
/~SS6: U8.11 (~CS); also elsewhere on the board
/~SS7: U9.11 (~CS); also elsewhere on the board
GND: C4.2, C5.2, C6.2, C7.2, C8.2, C9.2, C10.2, C11.2, U2.10 (VSS), U2.15 (A0), U2.16 (A1), U2.17 (A2), U3.10 (VSS), U3.15 (A0), U3.16 (A1), U3.17 (A2), U4.10 (VSS), U4.15 (A0), U4.16 (A1), U4.17 (A2), U5.10 (VSS), U5.15 (A0), U5.16 (A1), U5.17 (A2), U6.10 (VSS), U6.15 (A0), U6.16 (A1), U6.17 (A2), U7.10 (VSS), U7.15 (A0), U7.16 (A1), U7.17 (A2), U8.10 (VSS), U8.15 (A0), U8.16 (A1), U8.17 (A2), U9.10 (VSS), U9.15 (A0), U9.16 (A1), U9.17 (A2); also elsewhere on the board
VCC: C4.1, C5.1, C6.1, C7.1, C8.1, C9.1, C10.1, C11.1, U2.9 (VDD), U3.9 (VDD), U4.9 (VDD), U5.9 (VDD), U6.9 (VDD), U7.9 (VDD), U8.9 (VDD), U9.9 (VDD); also elsewhere on the board

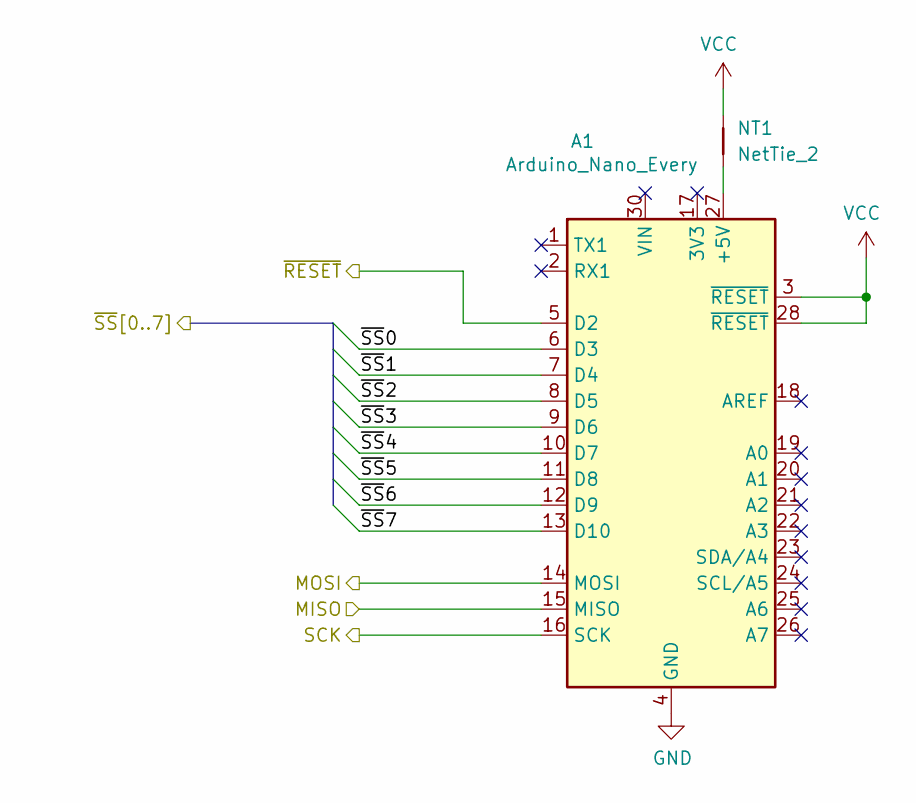
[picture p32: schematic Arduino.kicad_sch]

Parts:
A1: Arduino_Nano_Every; Arduino_Nano_Every_Castellated_Host
NT1: NetTie_2; NetTie-2_SMD_Pad0.5mm

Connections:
/MISO: A1.15 (MISO); also elsewhere on the board
/MOSI: A1.14 (MOSI); also elsewhere on the board
/SCK: A1.16 (SCK); also elsewhere on the board
/~RESET: A1.5 (D2); also elsewhere on the board
/~SS0: A1.6 (D3); also elsewhere on the board
/~SS1: A1.7 (D4); also elsewhere on the board
/~SS2: A1.8 (D5); also elsewhere on the board
/~SS3: A1.9 (D6); also elsewhere on the board
/~SS4: A1.10 (D7); also elsewhere on the board
/~SS5: A1.11 (D8); also elsewhere on the board
/~SS6: A1.12 (D9); also elsewhere on the board
/~SS7: A1.13 (D10); also elsewhere on the board
GND: A1.4 (GND), A1.29 (GND); also elsewhere on the board
unnamed: A1.27 (+5V), NT1.1
VCC: A1.3 (~RESET), A1.28 (~RESET), NT1.2; also elsewhere on the board

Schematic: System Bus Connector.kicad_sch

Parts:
J10: 71922-164LF; IDC-Header_2x32_P2.54mm_Horizontal; Manufacturer# 71922-164LF; Mouser# 649-71922-164LF

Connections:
/GPIO11: J10.59; also elsewhere on the board
/GPIO328: J10.7; also elsewhere on the board
/GPIO329: J10.8; also elsewhere on the board
/GPIO330: J10.9; also elsewhere on the board
/GPIO331: J10.10; also elsewhere on the board
/GPIO332: J10.13; also elsewhere on the board
/GPIO333: J10.14; also elsewhere on the board
/GPIO334: J10.15; also elsewhere on the board
/GPIO335: J10.16; also elsewhere on the board
/GPIO336: J10.19; also elsewhere on the board
/GPIO337: J10.20; also elsewhere on the board
/GPIO338: J10.21; also elsewhere on the board
/GPIO339: J10.22; also elsewhere on the board
/GPIO340: J10.25; also elsewhere on the board
/GPIO341: J10.26; also elsewhere on the board
/GPIO342: J10.27; also elsewhere on the board
/GPIO343: J10.28; also elsewhere on the board
/GPIO344: J10.51; also elsewhere on the board
/GPIO345: J10.52; also elsewhere on the board
/GPIO346: J10.49; also elsewhere on the board
/GPIO347: J10.50; also elsewhere on the board
/GPIO348: J10.45; also elsewhere on the board
/GPIO349: J10.46; also elsewhere on the board
/GPIO350: J10.43; also elsewhere on the board
/GPIO351: J10.44; also elsewhere on the board
/GPIO352: J10.39; also elsewhere on the board
/GPIO353: J10.40; also elsewhere on the board
/GPIO354: J10.37; also elsewhere on the board
/GPIO355: J10.38; also elsewhere on the board
/GPIO356: J10.33; also elsewhere on the board
/GPIO357: J10.34; also elsewhere on the board
/GPIO358: J10.31; also elsewhere on the board
/GPIO359: J10.32; also elsewhere on the board
/GPIO360: J10.1; also elsewhere on the board
/GPIO361: J10.2; also elsewhere on the board
/GPIO362: J10.3; also elsewhere on the board
/GPIO363: J10.56; also elsewhere on the board
/GPIO364: J10.55; also elsewhere on the board
/GPIO365: J10.60; also elsewhere on the board
/GPIO366: J10.62; also elsewhere on the board
/GPIO367: J10.61; also elsewhere on the board
GND: J10.5, J10.6, J10.11, J10.12, J10.17, J10.18, J10.23, J10.24, J10.29, J10.30, J10.35, J10.36, J10.41, J10.42, J10.47, J10.48, J10.53, J10.54; also elsewhere on the board
VCC: J10.57, J10.58, J10.63, J10.64; also elsewhere on the board

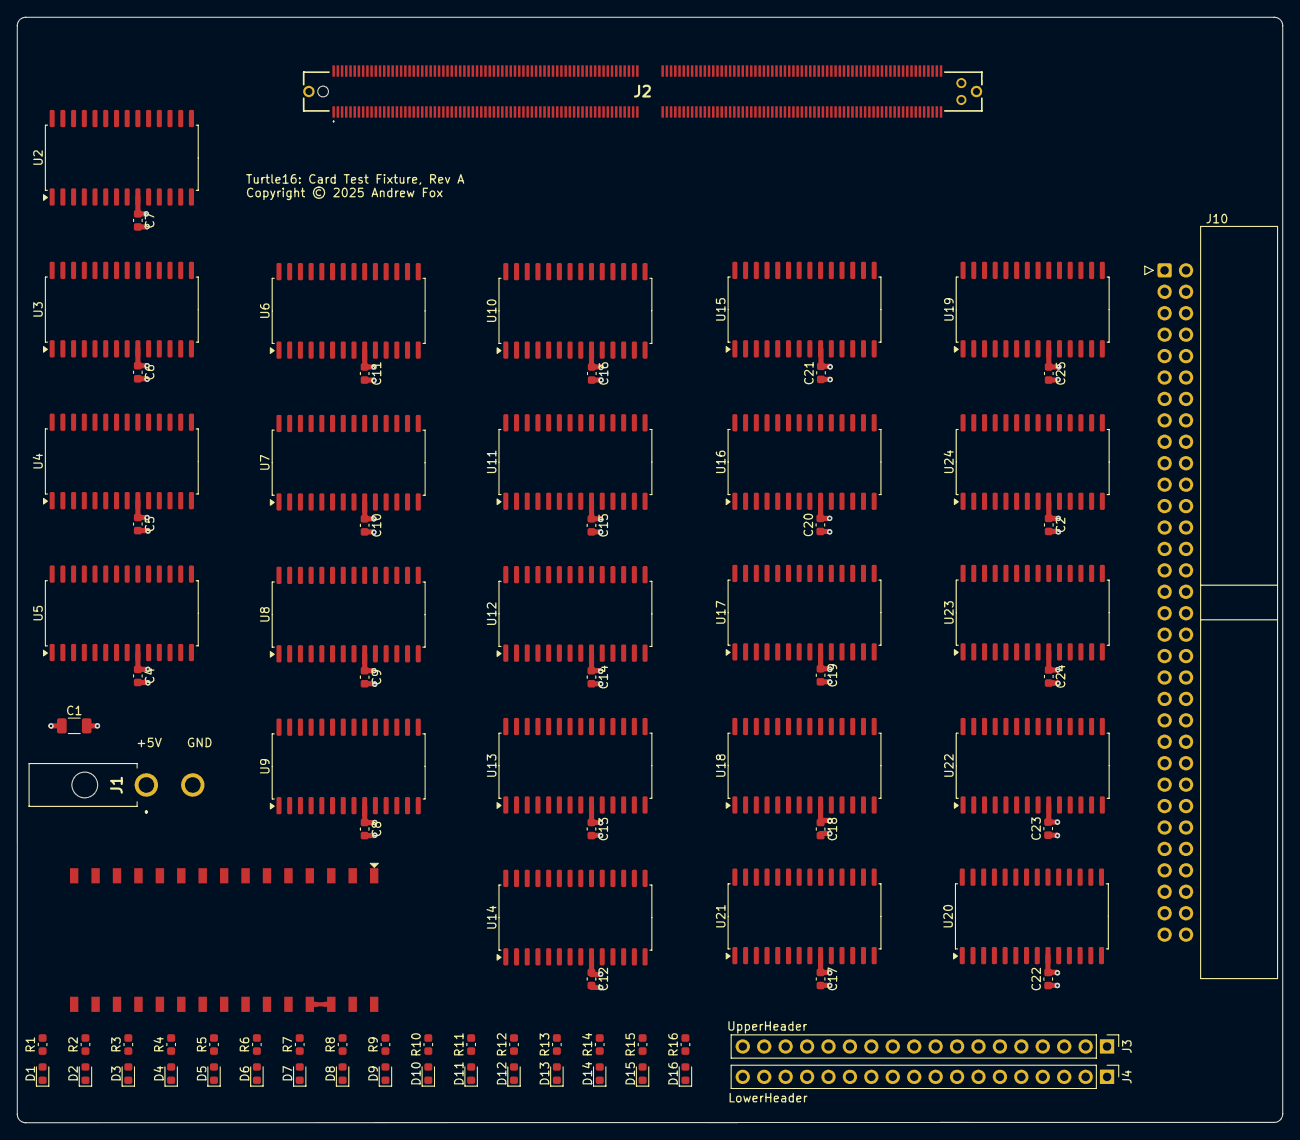
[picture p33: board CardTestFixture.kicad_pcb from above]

Board: 8 copper layers, 150.0 x 131.0 mm, 86 parts (0 on the bottom side), 392 nets.

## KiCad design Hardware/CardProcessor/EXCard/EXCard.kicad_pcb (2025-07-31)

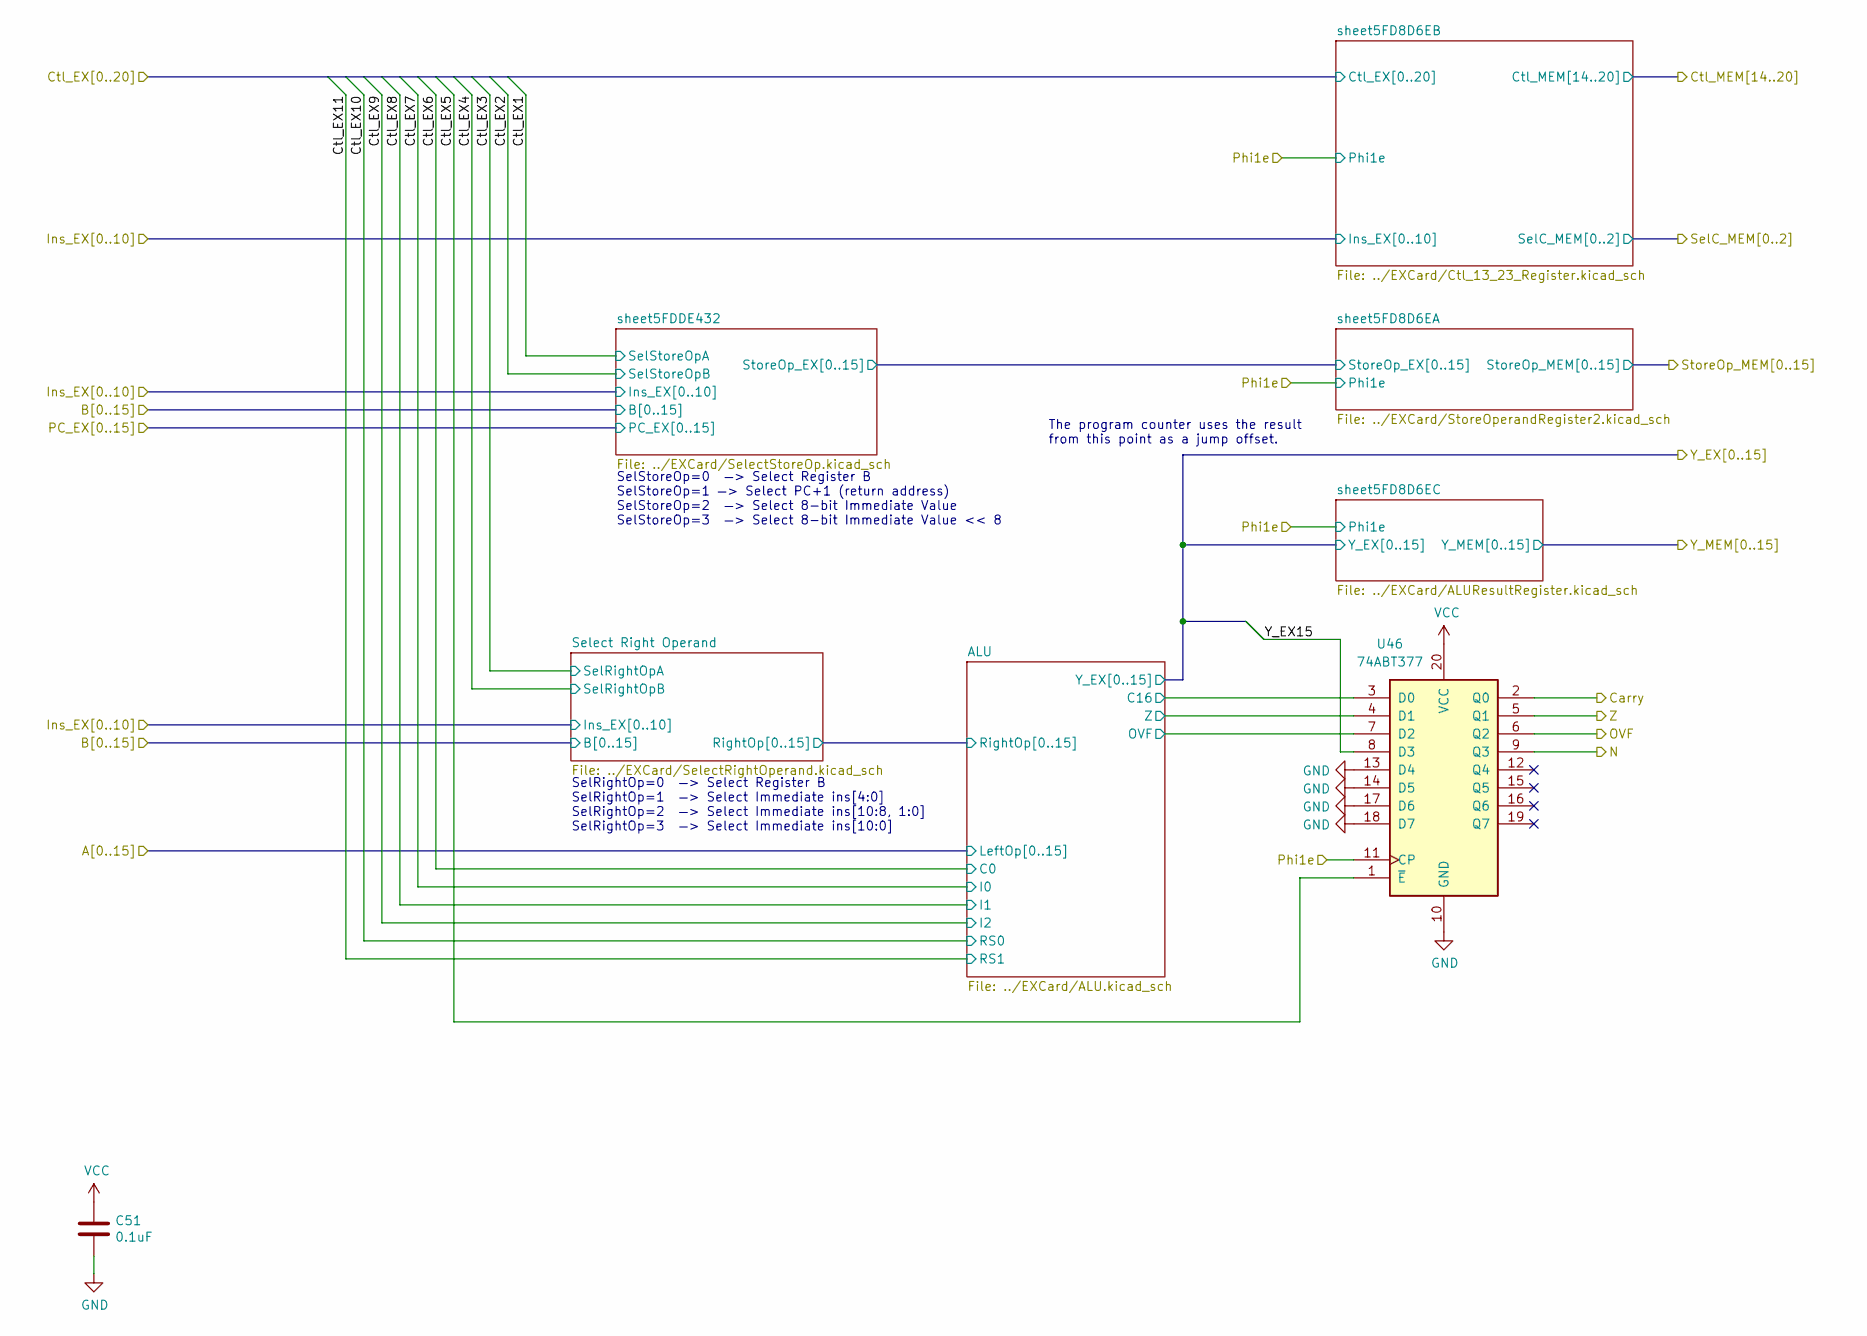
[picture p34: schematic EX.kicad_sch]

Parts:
C51: 0.1uF; C_0603_1608Metric; Manufacturer# EMK107B7104KAHT; Mouser# 963-EMK107B7104KAHT
U46: 74ABT377; TSSOP-20_4.4x6.5mm_P0.65mm; Manufacturer# SN74ABT377APWR; Mouser# 595-SN74ABT377APWR

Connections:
/Carry: U46.2 (Q0); also elsewhere on the board
/Ctl_EX5: U46.1 (~E); also elsewhere on the board
/EX/ALU/C16: U46.3 (D0); also elsewhere on the board
/EX/ALU/OVF: U46.7 (D2); also elsewhere on the board
/EX/ALU/Z: U46.4 (D1); also elsewhere on the board
/N: U46.9 (Q3); also elsewhere on the board
/OVF: U46.6 (Q2); also elsewhere on the board
/Phi1e: U46.11 (CP); also elsewhere on the board
/Y_EX15: U46.8 (D3); also elsewhere on the board
/Z: U46.5 (Q1); also elsewhere on the board
GND: C51.2, U46.10 (GND), U46.13 (D4), U46.14 (D5), U46.17 (D6), U46.18 (D7); also elsewhere on the board
VCC: C51.1, U46.20 (VCC); also elsewhere on the board

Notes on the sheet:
SelStoreOp=0 —> Select Register B SelStoreOp=1 —> Select PC+1 (return address) SelStoreOp=2 —> Select 8-bit Immediate Value SelStoreOp=3 —> Select 8-bit Immediate Value << 8
SelRightOp=0 —> Select Register B SelRightOp=1 —> Select Immediate ins[4:0] SelRightOp=2 —> Select Immediate ins[10:8, 1:0] SelRightOp=3 —> Select Immediate ins[10:0]
The program counter uses the result from this point as a jump offset.

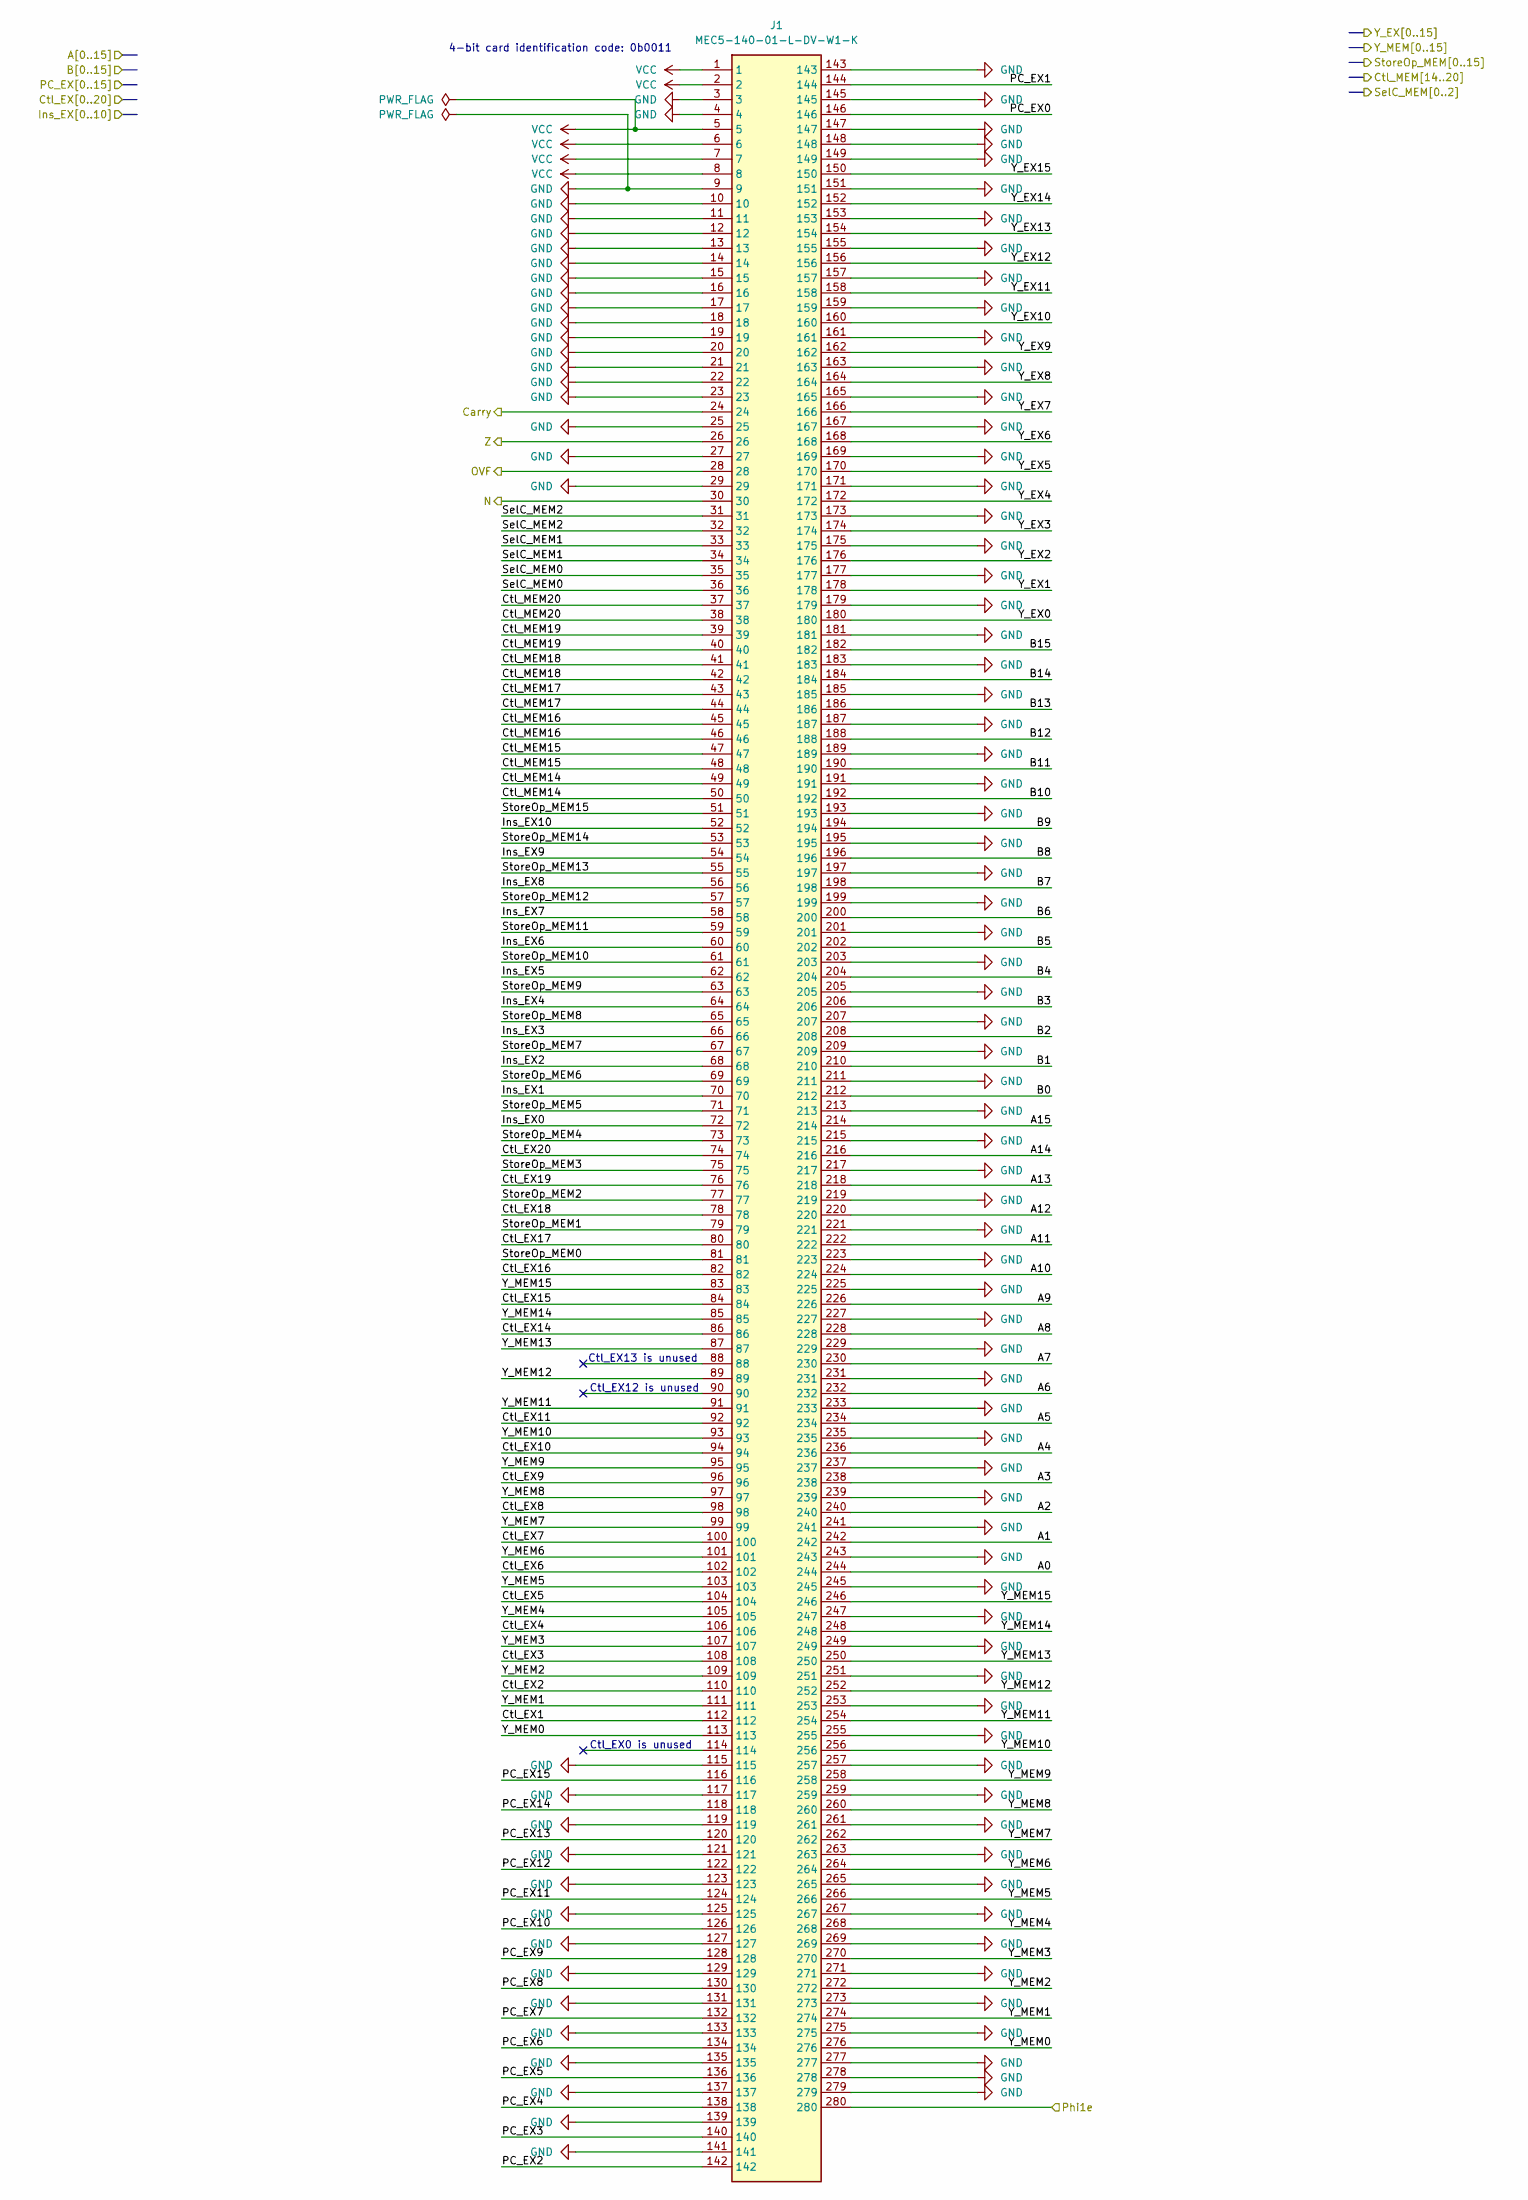
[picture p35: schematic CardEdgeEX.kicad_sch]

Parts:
J1: MEC5-140-01-L-DV-W1-K; MEC5-140-01-L-DV-W1-K_Edge; Mouser Part Number 200-MEC514001LDVW1K

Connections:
/A0: J1.244; also elsewhere on the board
/A1: J1.242; also elsewhere on the board
/A2: J1.240; also elsewhere on the board
/A3: J1.238; also elsewhere on the board
/A4: J1.236; also elsewhere on the board
/A5: J1.234; also elsewhere on the board
/A6: J1.232; also elsewhere on the board
/A7: J1.230; also elsewhere on the board
/A8: J1.228; also elsewhere on the board
/A9: J1.226; also elsewhere on the board
/A10: J1.224; also elsewhere on the board
/A11: J1.222; also elsewhere on the board
/A12: J1.220; also elsewhere on the board
/A13: J1.218; also elsewhere on the board
/A14: J1.216; also elsewhere on the board
/A15: J1.214; also elsewhere on the board
/B0: J1.212; also elsewhere on the board
/B1: J1.210; also elsewhere on the board
/B2: J1.208; also elsewhere on the board
/B3: J1.206; also elsewhere on the board
/B4: J1.204; also elsewhere on the board
/B5: J1.202; also elsewhere on the board
/B6: J1.200; also elsewhere on the board
/B7: J1.198; also elsewhere on the board
/B8: J1.196; also elsewhere on the board
/B9: J1.194; also elsewhere on the board
/B10: J1.192; also elsewhere on the board
/B11: J1.190; also elsewhere on the board
/B12: J1.188; also elsewhere on the board
/B13: J1.186; also elsewhere on the board
/B14: J1.184; also elsewhere on the board
/B15: J1.182; also elsewhere on the board
/Carry: J1.24; also elsewhere on the board
/Ctl_EX1: J1.112; also elsewhere on the board
/Ctl_EX2: J1.110; also elsewhere on the board
/Ctl_EX3: J1.108; also elsewhere on the board
/Ctl_EX4: J1.106; also elsewhere on the board
/Ctl_EX5: J1.104; also elsewhere on the board
/Ctl_EX6: J1.102; also elsewhere on the board
/Ctl_EX7: J1.100; also elsewhere on the board
/Ctl_EX8: J1.98; also elsewhere on the board
/Ctl_EX9: J1.96; also elsewhere on the board
/Ctl_EX10: J1.94; also elsewhere on the board
/Ctl_EX11: J1.92; also elsewhere on the board
/Ctl_EX14: J1.86; also elsewhere on the board
/Ctl_EX15: J1.84; also elsewhere on the board
/Ctl_EX16: J1.82; also elsewhere on the board
/Ctl_EX17: J1.80; also elsewhere on the board
/Ctl_EX18: J1.78; also elsewhere on the board
/Ctl_EX19: J1.76; also elsewhere on the board
/Ctl_EX20: J1.74; also elsewhere on the board
/Ctl_MEM14: J1.49, J1.50; also elsewhere on the board
/Ctl_MEM15: J1.47, J1.48; also elsewhere on the board
/Ctl_MEM16: J1.45, J1.46; also elsewhere on the board
/Ctl_MEM17: J1.43, J1.44; also elsewhere on the board
/Ctl_MEM18: J1.41, J1.42; also elsewhere on the board
/Ctl_MEM19: J1.39, J1.40; also elsewhere on the board
/Ctl_MEM20: J1.37, J1.38; also elsewhere on the board
/Ins_EX0: J1.72; also elsewhere on the board
/Ins_EX1: J1.70; also elsewhere on the board
/Ins_EX2: J1.68; also elsewhere on the board
/Ins_EX3: J1.66; also elsewhere on the board
/Ins_EX4: J1.64; also elsewhere on the board
/Ins_EX5: J1.62; also elsewhere on the board
/Ins_EX6: J1.60; also elsewhere on the board
/Ins_EX7: J1.58; also elsewhere on the board
/Ins_EX8: J1.56; also elsewhere on the board
/Ins_EX9: J1.54; also elsewhere on the board
/Ins_EX10: J1.52; also elsewhere on the board
/N: J1.30; also elsewhere on the board
/OVF: J1.28; also elsewhere on the board
/PC_EX0: J1.146; also elsewhere on the board
/PC_EX1: J1.144; also elsewhere on the board
/PC_EX2: J1.142; also elsewhere on the board
/PC_EX3: J1.140; also elsewhere on the board
/PC_EX4: J1.138; also elsewhere on the board
/PC_EX5: J1.136; also elsewhere on the board
/PC_EX6: J1.134; also elsewhere on the board
/PC_EX7: J1.132; also elsewhere on the board
/PC_EX8: J1.130; also elsewhere on the board
/PC_EX9: J1.128; also elsewhere on the board
/PC_EX10: J1.126; also elsewhere on the board
/PC_EX11: J1.124; also elsewhere on the board
/PC_EX12: J1.122; also elsewhere on the board
/PC_EX13: J1.120; also elsewhere on the board
/PC_EX14: J1.118; also elsewhere on the board
/PC_EX15: J1.116; also elsewhere on the board
/Phi1e: J1.280; also elsewhere on the board
/SelC_MEM0: J1.35, J1.36; also elsewhere on the board
/SelC_MEM1: J1.33, J1.34; also elsewhere on the board
/SelC_MEM2: J1.31, J1.32; also elsewhere on the board
/StoreOp_MEM0: J1.81; also elsewhere on the board
/StoreOp_MEM1: J1.79; also elsewhere on the board
/StoreOp_MEM2: J1.77; also elsewhere on the board
/StoreOp_MEM3: J1.75; also elsewhere on the board
/StoreOp_MEM4: J1.73; also elsewhere on the board
/StoreOp_MEM5: J1.71; also elsewhere on the board
/StoreOp_MEM6: J1.69; also elsewhere on the board
/StoreOp_MEM7: J1.67; also elsewhere on the board
/StoreOp_MEM8: J1.65; also elsewhere on the board
/StoreOp_MEM9: J1.63; also elsewhere on the board
/StoreOp_MEM10: J1.61; also elsewhere on the board
/StoreOp_MEM11: J1.59; also elsewhere on the board
/StoreOp_MEM12: J1.57; also elsewhere on the board
/StoreOp_MEM13: J1.55; also elsewhere on the board
/StoreOp_MEM14: J1.53; also elsewhere on the board
/StoreOp_MEM15: J1.51; also elsewhere on the board
/Y_EX0: J1.180; also elsewhere on the board
/Y_EX1: J1.178; also elsewhere on the board
/Y_EX2: J1.176; also elsewhere on the board
/Y_EX3: J1.174; also elsewhere on the board
/Y_EX4: J1.172; also elsewhere on the board
/Y_EX5: J1.170; also elsewhere on the board
/Y_EX6: J1.168; also elsewhere on the board
/Y_EX7: J1.166; also elsewhere on the board
/Y_EX8: J1.164; also elsewhere on the board
/Y_EX9: J1.162; also elsewhere on the board
/Y_EX10: J1.160; also elsewhere on the board
/Y_EX11: J1.158; also elsewhere on the board
/Y_EX12: J1.156; also elsewhere on the board
/Y_EX13: J1.154; also elsewhere on the board
/Y_EX14: J1.152; also elsewhere on the board
/Y_EX15: J1.150; also elsewhere on the board
/Y_MEM0: J1.113, J1.276; also elsewhere on the board
/Y_MEM1: J1.111, J1.274; also elsewhere on the board
/Y_MEM2: J1.109, J1.272; also elsewhere on the board
/Y_MEM3: J1.107, J1.270; also elsewhere on the board
/Y_MEM4: J1.105, J1.268; also elsewhere on the board
/Y_MEM5: J1.103, J1.266; also elsewhere on the board
/Y_MEM6: J1.101, J1.264; also elsewhere on the board
/Y_MEM7: J1.99, J1.262; also elsewhere on the board
/Y_MEM8: J1.97, J1.260; also elsewhere on the board
/Y_MEM9: J1.95, J1.258; also elsewhere on the board
/Y_MEM10: J1.93, J1.256; also elsewhere on the board
/Y_MEM11: J1.91, J1.254; also elsewhere on the board
/Y_MEM12: J1.89, J1.252; also elsewhere on the board
/Y_MEM13: J1.87, J1.250; also elsewhere on the board
/Y_MEM14: J1.85, J1.248; also elsewhere on the board
/Y_MEM15: J1.83, J1.246; also elsewhere on the board
/Z: J1.26; also elsewhere on the board
GND: J1.3, J1.4, J1.9, J1.10, J1.11, J1.12, J1.13, J1.14, J1.15, J1.16, J1.17, J1.18, J1.19, J1.20, J1.21, J1.22, J1.23, J1.25, J1.27, J1.29, J1.115, J1.117, J1.119, J1.121, J1.123, J1.125, J1.127, J1.129, J1.131, J1.133, J1.135, J1.137, J1.139, J1.141, J1.143, J1.145, J1.147, J1.148, J1.149, J1.151, J1.153, J1.155, J1.157, J1.159, J1.161, J1.163, J1.165, J1.167, J1.169, J1.171, J1.173, J1.175, J1.177, J1.179, J1.181, J1.183, J1.185, J1.187, J1.189, J1.191, J1.193, J1.195, J1.197, J1.199, J1.201, J1.203, J1.205, J1.207, J1.209, J1.211, J1.213, J1.215, J1.217, J1.219, J1.221, J1.223, J1.225, J1.227, J1.229, J1.231, J1.233, J1.235, J1.237, J1.239, J1.241, J1.243, J1.245, J1.247, J1.249, J1.251, J1.253, J1.255, J1.257, J1.259, J1.261, J1.263, J1.265, J1.267, J1.269, J1.271, J1.273, J1.275, J1.277, J1.278, J1.279; also elsewhere on the board
VCC: J1.1, J1.2, J1.5, J1.6, J1.7, J1.8; also elsewhere on the board

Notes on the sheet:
4-bit card identification code: 0b0011
Ctl_EX13 is unused
Ctl_EX0 is unused
Ctl_EX12 is unused

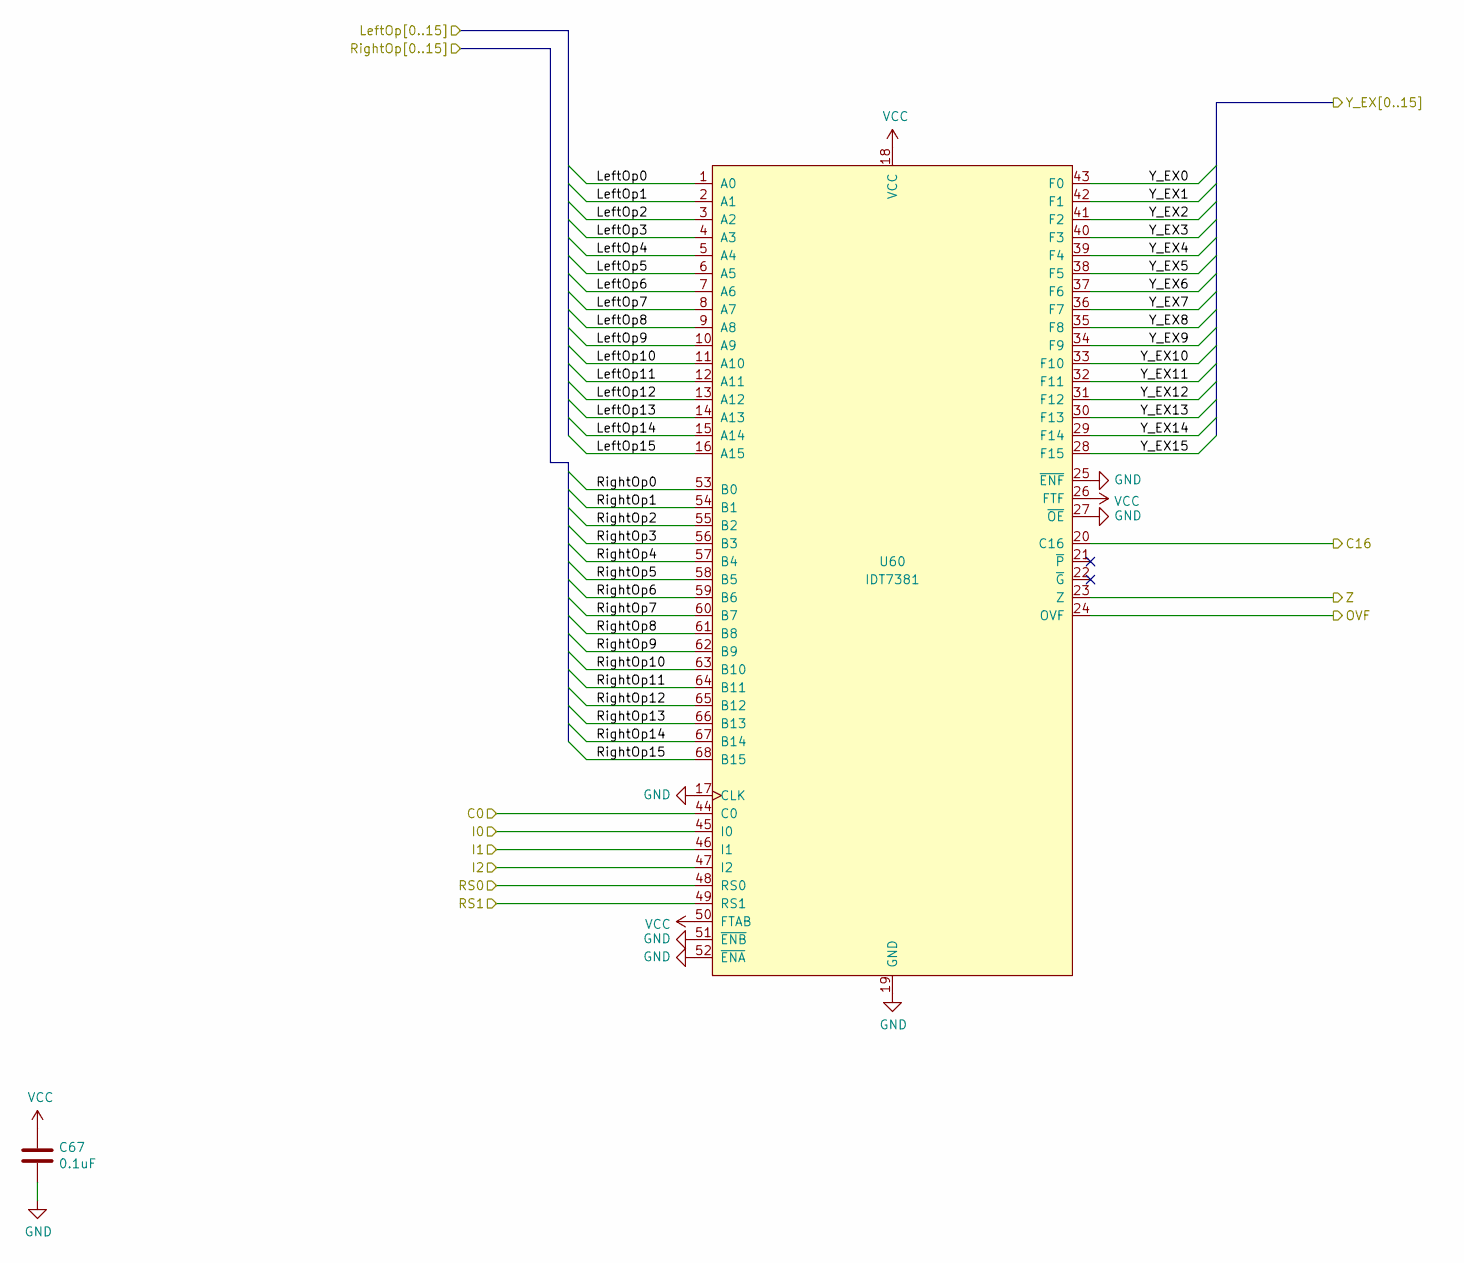
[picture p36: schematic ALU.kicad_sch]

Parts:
C67: 0.1uF; C_0603_1608Metric; Manufacturer# EMK107B7104KAHT; Mouser# 963-EMK107B7104KAHT
U60: IDT7381; PLCC-68_SMD-Socket; Manufacturer# 8468-21B1-RK-TP; Mouser# 517-8468-21B1-RK-TP

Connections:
/A0: U60.1 (A0); also elsewhere on the board
/A1: U60.2 (A1); also elsewhere on the board
/A2: U60.3 (A2); also elsewhere on the board
/A3: U60.4 (A3); also elsewhere on the board
/A4: U60.5 (A4); also elsewhere on the board
/A5: U60.6 (A5); also elsewhere on the board
/A6: U60.7 (A6); also elsewhere on the board
/A7: U60.8 (A7); also elsewhere on the board
/A8: U60.9 (A8); also elsewhere on the board
/A9: U60.10 (A9); also elsewhere on the board
/A10: U60.11 (A10); also elsewhere on the board
/A11: U60.12 (A11); also elsewhere on the board
/A12: U60.13 (A12); also elsewhere on the board
/A13: U60.14 (A13); also elsewhere on the board
/A14: U60.15 (A14); also elsewhere on the board
/A15: U60.16 (A15); also elsewhere on the board
/Ctl_EX6: U60.44 (C0); also elsewhere on the board
/Ctl_EX7: U60.45 (I0); also elsewhere on the board
/Ctl_EX8: U60.46 (I1); also elsewhere on the board
/Ctl_EX9: U60.47 (I2); also elsewhere on the board
/Ctl_EX10: U60.48 (RS0); also elsewhere on the board
/Ctl_EX11: U60.49 (RS1); also elsewhere on the board
/EX/ALU/C16: U60.20 (C16); also elsewhere on the board
/EX/ALU/OVF: U60.24 (OVF); also elsewhere on the board
/EX/ALU/RightOp0: U60.53 (B0); also elsewhere on the board
/EX/ALU/RightOp1: U60.54 (B1); also elsewhere on the board
/EX/ALU/RightOp2: U60.55 (B2); also elsewhere on the board
/EX/ALU/RightOp3: U60.56 (B3); also elsewhere on the board
/EX/ALU/RightOp4: U60.57 (B4); also elsewhere on the board
/EX/ALU/RightOp5: U60.58 (B5); also elsewhere on the board
/EX/ALU/RightOp6: U60.59 (B6); also elsewhere on the board
/EX/ALU/RightOp7: U60.60 (B7); also elsewhere on the board
/EX/ALU/RightOp8: U60.61 (B8); also elsewhere on the board
/EX/ALU/RightOp9: U60.62 (B9); also elsewhere on the board
/EX/ALU/RightOp10: U60.63 (B10); also elsewhere on the board
/EX/ALU/RightOp11: U60.64 (B11); also elsewhere on the board
/EX/ALU/RightOp12: U60.65 (B12); also elsewhere on the board
/EX/ALU/RightOp13: U60.66 (B13); also elsewhere on the board
/EX/ALU/RightOp14: U60.67 (B14); also elsewhere on the board
/EX/ALU/RightOp15: U60.68 (B15); also elsewhere on the board
/EX/ALU/Z: U60.23 (Z); also elsewhere on the board
/Y_EX0: U60.43 (F0); also elsewhere on the board
/Y_EX1: U60.42 (F1); also elsewhere on the board
/Y_EX2: U60.41 (F2); also elsewhere on the board
/Y_EX3: U60.40 (F3); also elsewhere on the board
/Y_EX4: U60.39 (F4); also elsewhere on the board
/Y_EX5: U60.38 (F5); also elsewhere on the board
/Y_EX6: U60.37 (F6); also elsewhere on the board
/Y_EX7: U60.36 (F7); also elsewhere on the board
/Y_EX8: U60.35 (F8); also elsewhere on the board
/Y_EX9: U60.34 (F9); also elsewhere on the board
/Y_EX10: U60.33 (F10); also elsewhere on the board
/Y_EX11: U60.32 (F11); also elsewhere on the board
/Y_EX12: U60.31 (F12); also elsewhere on the board
/Y_EX13: U60.30 (F13); also elsewhere on the board
/Y_EX14: U60.29 (F14); also elsewhere on the board
/Y_EX15: U60.28 (F15); also elsewhere on the board
GND: C67.2, U60.17 (CLK), U60.19 (GND), U60.25 (~ENF), U60.27 (~OE), U60.51 (~ENB), U60.52 (~ENA); also elsewhere on the board
VCC: C67.1, U60.18 (VCC), U60.26 (FTF), U60.50 (FTAB); also elsewhere on the board


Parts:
C69: 0.1uF; C_0603_1608Metric; Manufacturer# EMK107B7104KAHT; Mouser# 963-EMK107B7104KAHT
U62: 74ABT16374; TSSOP-48_6.1x12.5mm_P0.5mm; Manufacturer# SN74ABT16374ADGGR; Mouser# 595-SNABT16374ADGGR

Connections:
/EX/sheet5FD8D6EA/StoreOp_EX0: U62.47 (1D1); also elsewhere on the board
/EX/sheet5FD8D6EA/StoreOp_EX1: U62.46 (1D2); also elsewhere on the board
/EX/sheet5FD8D6EA/StoreOp_EX2: U62.44 (1D3); also elsewhere on the board
/EX/sheet5FD8D6EA/StoreOp_EX3: U62.43 (1D4); also elsewhere on the board
/EX/sheet5FD8D6EA/StoreOp_EX4: U62.41 (1D5); also elsewhere on the board
/EX/sheet5FD8D6EA/StoreOp_EX5: U62.40 (1D6); also elsewhere on the board
/EX/sheet5FD8D6EA/StoreOp_EX6: U62.38 (1D7); also elsewhere on the board
/EX/sheet5FD8D6EA/StoreOp_EX7: U62.37 (1D8); also elsewhere on the board
/EX/sheet5FD8D6EA/StoreOp_EX8: U62.36 (2D1); also elsewhere on the board
/EX/sheet5FD8D6EA/StoreOp_EX9: U62.35 (2D2); also elsewhere on the board
/EX/sheet5FD8D6EA/StoreOp_EX10: U62.33 (2D3); also elsewhere on the board
/EX/sheet5FD8D6EA/StoreOp_EX11: U62.32 (2D4); also elsewhere on the board
/EX/sheet5FD8D6EA/StoreOp_EX12: U62.30 (2D5); also elsewhere on the board
/EX/sheet5FD8D6EA/StoreOp_EX13: U62.29 (2D6); also elsewhere on the board
/EX/sheet5FD8D6EA/StoreOp_EX14: U62.27 (2D7); also elsewhere on the board
/EX/sheet5FD8D6EA/StoreOp_EX15: U62.26 (2D8); also elsewhere on the board
/Phi1e: U62.25 (2CLK), U62.48 (1CLK); also elsewhere on the board
/StoreOp_MEM0: U62.2 (1Q1); also elsewhere on the board
/StoreOp_MEM1: U62.3 (1Q2); also elsewhere on the board
/StoreOp_MEM2: U62.5 (1Q3); also elsewhere on the board
/StoreOp_MEM3: U62.6 (1Q4); also elsewhere on the board
/StoreOp_MEM4: U62.8 (1Q5); also elsewhere on the board
/StoreOp_MEM5: U62.9 (1Q6); also elsewhere on the board
/StoreOp_MEM6: U62.11 (1Q7); also elsewhere on the board
/StoreOp_MEM7: U62.12 (1Q8); also elsewhere on the board
/StoreOp_MEM8: U62.13 (2Q1); also elsewhere on the board
/StoreOp_MEM9: U62.14 (2Q2); also elsewhere on the board
/StoreOp_MEM10: U62.16 (2Q3); also elsewhere on the board
/StoreOp_MEM11: U62.17 (2Q4); also elsewhere on the board
/StoreOp_MEM12: U62.19 (2Q5); also elsewhere on the board
/StoreOp_MEM13: U62.20 (2Q6); also elsewhere on the board
/StoreOp_MEM14: U62.22 (2Q7); also elsewhere on the board
/StoreOp_MEM15: U62.23 (2Q8); also elsewhere on the board
GND: C69.2, U62.1 (1~OE), U62.4 (GND), U62.10 (GND), U62.15 (GND), U62.21 (GND), U62.24 (2~OE), U62.28 (GND), U62.34 (GND), U62.39 (GND), U62.45 (GND); also elsewhere on the board
VCC: C69.1, U62.7 (VCC), U62.18 (VCC), U62.31 (VCC), U62.42 (VCC); also elsewhere on the board


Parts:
C68: 0.1uF; C_0603_1608Metric; Manufacturer# EMK107B7104KAHT; Mouser# 963-EMK107B7104KAHT
U61: 74ABT16374; TSSOP-48_6.1x12.5mm_P0.5mm; Manufacturer# SN74ABT16374ADGGR; Mouser# 595-SNABT16374ADGGR
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

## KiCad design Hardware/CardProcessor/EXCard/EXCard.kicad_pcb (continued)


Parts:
C70: 0.1uF; C_0603_1608Metric; Manufacturer# EMK107B7104KAHT; Digikey# 587-6004-1-ND
U63: 74ABT16374; TSSOP-48_6.1x12.5mm_P0.5mm; Manufacturer# SN74ABT16374ADGGR; Mouser# 595-SNABT16374ADGGR

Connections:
/Phi1e: U63.25 (2CLK), U63.48 (1CLK); also elsewhere on the board
/Y_EX0: U63.47 (1D1); also elsewhere on the board
/Y_EX1: U63.46 (1D2); also elsewhere on the board
/Y_EX2: U63.44 (1D3); also elsewhere on the board
/Y_EX3: U63.43 (1D4); also elsewhere on the board
/Y_EX4: U63.41 (1D5); also elsewhere on the board
/Y_EX5: U63.40 (1D6); also elsewhere on the board
/Y_EX6: U63.38 (1D7); also elsewhere on the board
/Y_EX7: U63.37 (1D8); also elsewhere on the board
/Y_EX8: U63.36 (2D1); also elsewhere on the board
/Y_EX9: U63.35 (2D2); also elsewhere on the board
/Y_EX10: U63.33 (2D3); also elsewhere on the board
/Y_EX11: U63.32 (2D4); also elsewhere on the board
/Y_EX12: U63.30 (2D5); also elsewhere on the board
/Y_EX13: U63.29 (2D6); also elsewhere on the board
/Y_EX14: U63.27 (2D7); also elsewhere on the board
/Y_EX15: U63.26 (2D8); also elsewhere on the board
/Y_MEM0: U63.2 (1Q1); also elsewhere on the board
/Y_MEM1: U63.3 (1Q2); also elsewhere on the board
/Y_MEM2: U63.5 (1Q3); also elsewhere on the board
/Y_MEM3: U63.6 (1Q4); also elsewhere on the board
/Y_MEM4: U63.8 (1Q5); also elsewhere on the board
/Y_MEM5: U63.9 (1Q6); also elsewhere on the board
/Y_MEM6: U63.11 (1Q7); also elsewhere on the board
/Y_MEM7: U63.12 (1Q8); also elsewhere on the board
/Y_MEM8: U63.13 (2Q1); also elsewhere on the board
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

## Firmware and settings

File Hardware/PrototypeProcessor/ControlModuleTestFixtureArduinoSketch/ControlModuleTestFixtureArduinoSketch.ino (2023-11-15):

#include <stdio.h>
#include "TestFramework.h"
#include "ShiftRegisterIO.h"
#include "ControlModuleTestFixtureIO.h"
#include "LEDPattern.h"

const TestFixtureInputPorts testFixtureInputPorts = {
  .PL = 8,
  .SCK = 7,
  .SO = 6
};

const TestFixtureOutputPorts testFixtureOutputPorts = {
  .SI = 2,
  .RCLK = 3,
  .SCK = 4,
  .CLR = 5
};

const LEDOutputPorts ledPorts = {
  .SI = 17,
  .RCLK = 16,
  .SCK = 15,
  .CLR = 14
};

void testInstructionWordCopiedOver(unsigned ledState) {
  TestFixtureOutputs testFixtureOutputs;

  printf("%s: ", __FUNCTION__);
  printf("Check that the lower eleven bits of the instruction word are copied to the next pipeline stage...");

  // Assert the reset line
  testFixtureOutputs = TestFixtureOutputs().ins(0b1111111111111111);
  testFixtureOutputPorts.set(testFixtureOutputs);

  // Pulse the clock
  testFixtureOutputs = testFixtureOutputPorts.tick(testFixtureOutputs);
  
  TestFixtureInputs actualTestFixtureInputs = testFixtureInputPorts.read();
  assertEqual(0b11111111111, actualTestFixtureInputs.Ins_EX, "Expect Ins_EX contains the lower eleven bits of the instruction word");

  printf("passed\n");
}

static const unsigned kOpcodeShift = 11;
static const unsigned kOpcodeHLT = 1;
static const unsigned kOpcodeADD = 7;
static const unsigned kOpcodeJMP = 20;

void testHlt(unsigned ledState) {
  TestFixtureOutputs testFixtureOutputs;

  printf("%s: ", __FUNCTION__);
  printf("Put a HLT through the Control unit and check what it outputs to the text fixture...");

  // Assert the reset line
  testFixtureOutputs = TestFixtureOutputs()
    .ins(kOpcodeHLT << kOpcodeShift)
    .phi1(1)
    .phi2(0);
  testFixtureOutputPorts.set(testFixtureOutputs);

  // Pulse the clock
  testFixtureOutputs = testFixtureOutputPorts.tick(testFixtureOutputs);
  
  TestFixtureInputs actualTestFixtureInputs = testFixtureInputPorts.read();
  assertEqual(0, actualTestFixtureInputs.Ctl_EX & 1, "Expect HLT control line is active");

  printf("passed\n");
}

void testReset(unsigned ledState) {
  TestFixtureOutputs testFixtureOutputs;

  printf("%s: ", __FUNCTION__);
  printf("Testing reset function...");

  // Assert the reset line
  testFixtureOutputs = TestFixtureOutputs()
    .reset(true)
    .phi1(1)
    .phi2(0);
  testFixtureOutputPorts.set(testFixtureOutputs);

  // Pulse the clock
  testFixtureOutputs = testFixtureOutputPorts.tick(testFixtureOutputs);
  
  TestFixtureInputs actualTestFixtureInputs = testFixtureInputPorts.read();
  assertEqual(0b111111111111111111111, actualTestFixtureInputs.Ctl_EX, "Expect that no control signals are asserted.");
  assertEqual(0, actualTestFixtureInputs.Ins_EX, "Expect Ins_EX==0");
  assertEqual(0, actualTestFixtureInputs.stall, "Expect stall==0");
  assertEqual(0, actualTestFixtureInputs.fwd_a, "Expect fwd_a==0");
  assertEqual(1, actualTestFixtureInputs.fwd_ex_to_a, "Expect fwd_ex_to_a==1");
  assertEqual(1, actualTestFixtureInputs.fwd_mem_to_a, "Expect fwd_mem_to_a==1");
  assertEqual(0, actualTestFixtureInputs.fwd_b, "Expect fwd_b==0");
  assertEqual(1, actualTestFixtureInputs.fwd_ex_to_b, "Expect fwd_ex_to_b==1");
  assertEqual(1, actualTestFixtureInputs.fwd_mem_to_b, "Expect fwd_mem_to_b==1");

  printf("passed\n");
}

void testNop(unsigned ledState) {
  TestFixtureOutputs testFixtureOutputs;

  printf("%s: ", __FUNCTION__);
  printf("Put a NOP through the Control unit and check what it outputs to the text fixture...");

  // Assert NOP instruction as input
  testFixtureOutputs = TestFixtureOutputs()
    .ins(0)
    .phi1(1)
    .phi2(0);
  testFixtureOutputPorts.set(testFixtureOutputs);

  // Pulse the clock
  testFixtureOutputs = testFixtureOutputPorts.tick(testFixtureOutputs);  
  
  TestFixtureInputs actualTestFixtureInputs = testFixtureInputPorts.read();
  assertEqual(0, actualTestFixtureInputs.Ins_EX, "Expect Ins_EX==0");
  assertEqual(0, actualTestFixtureInputs.stall, "Expect stall==0");
  assertEqual(0b111111111111111111111, actualTestFixtureInputs.Ctl_EX, "Expect that no control signals are asserted.");

  printf("passed\n");
}

void testAdd(unsigned ledState) {
  TestFixtureOutputs testFixtureOutputs;

  printf("%s: ", __FUNCTION__);
  printf("Put an ADD through the Control unit and check what it outputs to the text fixture...");

  // Assert ADD instruction as input
  testFixtureOutputs = TestFixtureOutputs()
    .selC(3)                 // SelC_MEM
    .ctl(0b1111111)          // Ctl_MEM holds a NOP
    .ins(0b0011100000101000) // opcode=7, c=0, a=1, b=2
    .carry(false)
    .zero(false)
    .overflow(false)
    .negative(false)
    .reset(false)
    .phi1(1)
    .phi2(0);
  testFixtureOutputPorts.set(testFixtureOutputs);

  // Pulse the clock
  testFixtureOutputs = testFixtureOutputPorts.tick(testFixtureOutputs);
  
  TestFixtureInputs actualTestFixtureInputs = testFixtureInputPorts.read();
  assertEqual(0, actualTestFixtureInputs.stall, "Expect stall==0");
  assertEqual(0b000011111110110000111, actualTestFixtureInputs.Ctl_EX, "Expect appropriate control signals for ADD");
  
  printf("passed\n");
}

void testBypassFromMEMtoA(unsigned ledState) {
  TestFixtureOutputs testFixtureOutputs;

  printf("%s: ", __FUNCTION__);
  printf("Bypass MEM to operand A...");

  // Assert ADD instruction as input
  testFixtureOutputs = TestFixtureOutputs()
    .selC(1)                 // SelC_MEM
    .ctl(0b0000001)          // Ctl_MEM has a value that it wants to write back to register 1
    .ins(0b0011100000101000) // opcode=7, c=0, a=1, b=2
    .carry(false)
    .zero(false)
    .overflow(false)
    .negative(false)
    .reset(false)
    .phi1(1)
    .phi2(0);
  testFixtureOutputPorts.set(testFixtureOutputs);

  // Pulse the clock
  testFixtureOutputs = testFixtureOutputPorts.tick(testFixtureOutputs);
  
  TestFixtureInputs actualTestFixtureInputs = testFixtureInputPorts.read();
  assertEqual(0, actualTestFixtureInputs.stall, "Expect stall==0");
  assertEqual(0b000011111110110000111, actualTestFixtureInputs.Ctl_EX, "Expect appropriate control signals for ADD");
  assertEqual(0, actualTestFixtureInputs.stall, "Expect stall==0");
  assertEqual(1, actualTestFixtureInputs.fwd_a, "Expect fwd_a==1");
  assertEqual(1, actualTestFixtureInputs.fwd_ex_to_a, "Expect fwd_ex_to_a==1");
  assertEqual(0, actualTestFixtureInputs.fwd_mem_to_a, "Expect fwd_mem_to_a==0");
  assertEqual(0, actualTestFixtureInputs.fwd_b, "Expect fwd_b==0");
  assertEqual(1, actualTestFixtureInputs.fwd_ex_to_b, "Expect fwd_ex_to_b==1");
  assertEqual(1, actualTestFixtureInputs.fwd_mem_to_b, "Expect fwd_mem_to_b==1");
  
  printf("passed\n");
}

void testBypassFromMEMtoB(unsigned ledState) {
  TestFixtureOutputs testFixtureOutputs;

  printf("%s: ", __FUNCTION__);
  printf("Bypass MEM to operand B...");

  // Assert ADD instruction as input
  testFixtureOutputs = TestFixtureOutputs()
    .selC(1)                 // SelC_MEM
    .ctl(0b0000001)          // Ctl_MEM has a value that it wants to write back to register 1
    .ins(0b0011100001000100) // opcode=7, c=0, a=2, b=1
    .carry(false)
    .zero(false)
    .overflow(false)
    .negative(false)
    .reset(false)
    .phi1(1)
    .phi2(0);
  testFixtureOutputPorts.set(testFixtureOutputs);

  // Pulse the clock
  testFixtureOutputs = testFixtureOutputPorts.tick(testFixtureOutputs);
  
  TestFixtureInputs actualTestFixtureInputs = testFixtureInputPorts.read();
  assertEqual(0, actualTestFixtureInputs.stall, "Expect stall==0");
  assertEqual(0b000011111110110000111, actualTestFixtureInputs.Ctl_EX, "Expect appropriate control signals for ADD");
  assertEqual(0, actualTestFixtureInputs.stall, "Expect stall==0");
  assertEqual(0, actualTestFixtureInputs.fwd_a, "Expect fwd_a==0");
  assertEqual(1, actualTestFixtureInputs.fwd_ex_to_a, "Expect fwd_ex_to_a==1");
  assertEqual(1, actualTestFixtureInputs.fwd_mem_to_a, "Expect fwd_mem_to_a==1");
  assertEqual(1, actualTestFixtureInputs.fwd_b, "Expect fwd_b==1");
  assertEqual(1, actualTestFixtureInputs.fwd_ex_to_b, "Expect fwd_ex_to_b==1");
  assertEqual(0, actualTestFixtureInputs.fwd_mem_to_b, "Expect fwd_mem_to_b==0");
  
  printf("passed\n");
}

void testBypassFromEXtoA(unsigned ledState) {
  TestFixtureOutputs testFixtureOutputs;

  printf("%s: ", __FUNCTION__);
  printf("Bypass EX to operand A...");

  // As part of test setup we have to process an instruction
  // and latch the interstage registers headed to the EX stage.
  // Once we set this state, we check that it is used to
  // correctly command a bypass on the next instruction.
  testFixtureOutputs = TestFixtureOutputs()
    .selC(0)                 // SelC_MEM
    .ctl(0b1111111)          // Ctl_MEM is NOP
    .ins(0b0011100000101000) // opcode=7, c=0, a=1, b=2
    .carry(false)
    .zero(false)
    .overflow(false)
    .negative(false)
    .reset(false)
    .phi1(1)
    .phi2(0);
  testFixtureOutputPorts.set(testFixtureOutputs);
  testFixtureOutputs = testFixtureOutputPorts.tick(testFixtureOutputs);

  // Assert ADD instruction as input
  testFixtureOutputs = TestFixtureOutputs()
    .selC(0)                 // SelC_MEM
    .ctl(0b1111111)          // Ctl_MEM is NOP
    .ins(0b0011100000001000) // opcode=7, c=0, a=0, b=2
    .carry(false)
    .zero(false)
    .overflow(false)
    .negative(false)
    .reset(false)
    .phi1(1)
    .phi2(0);
  testFixtureOutputPorts.set(testFixtureOutputs);

  // Pulse the clock
  testFixtureOutputs = testFixtureOutputPorts.tick(testFixtureOutputs);
  
  TestFixtureInputs actualTestFixtureInputs = testFixtureInputPorts.read();
  assertEqual(0, actualTestFixtureInputs.stall, "Expect stall==0");
  assertEqual(0b000011111110110000111, actualTestFixtureInputs.Ctl_EX, "Expect appropriate control signals for ADD");
  assertEqual(0, actualTestFixtureInputs.stall, "Expect stall==0");
  assertEqual(1, actualTestFixtureInputs.fwd_a, "Expect fwd_a==1");
  assertEqual(0, actualTestFixtureInputs.fwd_ex_to_a, "Expect fwd_ex_to_a==0");
  assertEqual(1, actualTestFixtureInputs.fwd_mem_to_a, "Expect fwd_mem_to_a==1");
  assertEqual(0, actualTestFixtureInputs.fwd_b, "Expect fwd_b==0");
  assertEqual(1, actualTestFixtureInputs.fwd_ex_to_b, "Expect fwd_ex_to_b==1");
  assertEqual(1, actualTestFixtureInputs.fwd_mem_to_b, "Expect fwd_mem_to_b==1");
  
  printf("passed\n");
}

void testBypassFromEXtoB(unsigned ledState) {
  TestFixtureOutputs testFixtureOutputs;

  printf("%s: ", __FUNCTION__);
  printf("Bypass EX to operand B...");

  // As part of test setup we have to process an instruction
  // and latch the interstage registers headed to the EX stage.
  // Once we set this state, we check that it is used to
  // correctly command a bypass on the next instruction.
  testFixtureOutputs = TestFixtureOutputs()
    .selC(0)                 // SelC_MEM
    .ctl(0b1111111)          // Ctl_MEM is NOP
    .ins(0b0011100000101000) // opcode=7, c=0, a=1, b=2
    .carry(false)
    .zero(false)
    .overflow(false)
    .negative(false)
    .reset(false)
    .phi1(1)
    .phi2(0);
  testFixtureOutputPorts.set(testFixtureOutputs);
  testFixtureOutputs = testFixtureOutputPorts.tick(testFixtureOutputs);

  // Assert ADD instruction as input
  testFixtureOutputs = TestFixtureOutputs()
    .selC(0)                 // SelC_MEM
    .ctl(0b1111111)          // Ctl_MEM is NOP
    .ins(0b0011100001000000) // opcode=7, c=0, a=2, b=0
    .carry(false)
    .zero(false)
    .overflow(false)
    .negative(false)
    .reset(false)
    .phi1(1)
    .phi2(0);
  testFixtureOutputPorts.set(testFixtureOutputs);

  // Pulse the clock
  testFixtureOutputs = testFixtureOutputPorts.tick(testFixtureOutputs);
  
  TestFixtureInputs actualTestFixtureInputs = testFixtureInputPorts.read();
  assertEqual(0, actualTestFixtureInputs.stall, "Expect stall==0");
  assertEqual(0b000011111110110000111, actualTestFixtureInputs.Ctl_EX, "Expect appropriate control signals for ADD");
  assertEqual(0, actualTestFixtureInputs.stall, "Expect stall==0");
  assertEqual(0, actualTestFixtureInputs.fwd_a, "Expect fwd_a==0");
  assertEqual(1, actualTestFixtureInputs.fwd_ex_to_a, "Expect fwd_ex_to_a==1");
  assertEqual(1, actualTestFixtureInputs.fwd_mem_to_a, "Expect fwd_mem_to_a==1");
  assertEqual(1, actualTestFixtureInputs.fwd_b, "Expect fwd_b==1");
  assertEqual(0, actualTestFixtureInputs.fwd_ex_to_b, "Expect fwd_ex_to_b==0");
  assertEqual(1, actualTestFixtureInputs.fwd_mem_to_b, "Expect fwd_mem_to_b==1");
  
  printf("passed\n");
}

void testFlushOnStoreOp(unsigned ledState) {
  TestFixtureOutputs testFixtureOutputs;

  printf("%s: ", __FUNCTION__);
  printf("Flush due to dependency on a LOAD instruction...");

  // Assert ADD instruction as input
  // The ADD instruction operands depend on a register
  // value which is being loaded in the MEM stage and
  // so the instruction must stall.
  testFixtureOutputs = TestFixtureOutputs()
    .selC(0)                 // SelC_MEM
    .ctl(0b0001000)          // Ctl_MEM is loading a value into the register that the ADD depends on.
    .ins(0b0011100000000000) // opcode=7, c=0, a=0, b=0
    .carry(false)
    .zero(false)
    .overflow(false)
    .negative(false)
    .reset(false)
    .phi1(0)
    .phi2(1);
  testFixtureOutputPorts.set(testFixtureOutputs);

  // The ID stage is stalling the pipeline this clock cycle.
  TestFixtureInputs actualTestFixtureInputs = testFixtureInputPorts.read();
  assertEqual(1, actualTestFixtureInputs.stall, "RAW hazards should stall the pipeline");

  // Tick the clock so Ctl_EX updates.
  testFixtureOutputs = testFixtureOutputs
    .phi1(1)
    .phi2(0);
  testFixtureOutputPorts.set(testFixtureOutputs);
  
  // Ensure the ID stage did emit a NOP during the stall.
  actualTestFixtureInputs = testFixtureInputPorts.read();
  assertEqual(0b111111111111111111111, actualTestFixtureInputs.Ctl_EX, "During a flush, the control signals should be equivalent to NOP.");
  
  printf("passed\n");
}

void testStallOnFlagsHazard(unsigned ledState) {
  TestFixtureOutputs testFixtureOutputs;

  printf("%s: ", __FUNCTION__);
  printf("Stall to avoid a flags hazard...");

  // Put control signals into Ctl_EX to indicate that flags are
  // being updated in the EX stage in this clock cycle.
  testFixtureOutputs = TestFixtureOutputs()
    .selC(0)
    .ctl(0b1111111)
    .ins(0b0011100000000000)
    .carry(false)
    .zero(false)
    .overflow(false)
    .negative(false)
    .reset(false)
    .phi1(0)
    .phi2(1);
  testFixtureOutputPorts.set(testFixtureOutputs);

  // Tick the clock so Ctl_EX updates.
  testFixtureOutputs = testFixtureOutputs
    .phi1(1)
    .phi2(0);
  testFixtureOutputPorts.set(testFixtureOutputs);

  // The BEQ instruction depends on flags generated by the ALU.
  // If we depend on the immediately previous instruction to
  // generate these flags then the pipeline will stall for one
  // cycle.
  testFixtureOutputs = TestFixtureOutputs()
    .selC(0)                 // SelC_MEM
    .ctl(0b0001000)          // Ctl_MEM is loading a value into the register that the ADD depends on.
    .ins(0b1100000000000000) // opcode=24 (BEQ)
    .carry(false)
    .zero(false)
    .overflow(false)
    .negative(false)
    .reset(false)
    .phi1(0)
    .phi2(1);
  testFixtureOutputPorts.set(testFixtureOutputs);

  // The pipeline is stalling this clock cycle because of the flags hazard.
  TestFixtureInputs actualTestFixtureInputs = testFixtureInputPorts.read();
  assertEqual(1, actualTestFixtureInputs.stall, "Flags hazards should stall the pipeline");

  // Tick the clock so Ctl_EX updates.
  testFixtureOutputs = testFixtureOutputs
    .phi1(1)
    .phi2(0);
  testFixtureOutputPorts.set(testFixtureOutputs);

  // Ensure Ctl_EX indicates the ID stage did emit a NOP during the stall.
  actualTestFixtureInputs = testFixtureInputPorts.read();
  assertEqual(0b111111111111111111111, actualTestFixtureInputs.Ctl_EX, "During a flush, the control signals should be equivalent to NOP.");
  
  printf("passed\n");
}

void testJmp(unsigned ledState) {
  TestFixtureOutputs testFixtureOutputs;

  printf("%s: ", __FUNCTION__);
  printf("Put an JMP through the Control unit and check what it outputs to the text fixture...");

  // Assert JMP instruction as input
  testFixtureOutputs = TestFixtureOutputs()
    .ins(kOpcodeJMP << kOpcodeShift)
    .phi1(1)
    .phi2(0);
  testFixtureOutputPorts.set(testFixtureOutputs);

  // Pulse the clock
  testFixtureOutputs = testFixtureOutputPorts.tick(testFixtureOutputs);
  
  TestFixtureInputs actualTestFixtureInputs = testFixtureInputPorts.read();

  // A branch triggers a flush of the pipeline IF stage, but
  // that's not visible from the control unit test fixture.
  // All we can see is that it does not stall the pipeline.
  assertEqual(0, actualTestFixtureInputs.stall, "Expect stall==0");

  // The control signals for this JMP instruction indicate
  // to the EX unit to use the ALU to compute the target and
  // to jump to it. This is why we must set the ALU mode and
  // we must set the CarryIn bit.
  assertEqual(0b111111110101010111111, actualTestFixtureInputs.Ctl_EX, "Expect appropriate control signals for JMP");
  
  printf("passed\n");
}

void (*allTests[])(unsigned) = {
  testInstructionWordCopiedOver,
  testHlt,
  testReset,
  testNop,
  testAdd,
  testBypassFromMEMtoA,
  testBypassFromMEMtoB,
  testBypassFromEXtoA,
  testBypassFromEXtoB,
  testFlushOnStoreOp,
  testStallOnFlagsHazard,
  testJmp,
};

void doAllTests() {
  // Setup the LED flasher which flashes an LED pattern to indicate test failure.
  static ErrorFlasher<LEDOutputPorts, LEDOutputs> errorFlasher(ledPorts);
  g_errorFlasher = &errorFlasher;

  // We update the chasing LED light pattern during test execution.
  Chaser<LEDOutputPorts, LEDOutputs> chaser(ledPorts);

  // Run all tests, one by one
  for (int i = 0, n = sizeof(allTests)/sizeof(*allTests); i < n; ++i) {
    chaser.step();
    allTests[i](chaser.led);
  }
  for (int i = 0; i < 8; ++i) {
    delay(100);
    chaser.step();
  }

  printf("All tests passed.\n");

  // Setup the LED flasher which flashes an LED pattern to indicate all tests passed.
  static SuccessFlasher<LEDOutputPorts, LEDOutputs> successFlasher(ledPorts);
  successFlasher.runForever();
}

int serial_putc(char c, FILE *) {
  Serial.write(c);
  return c;
}

void setup() {
  Serial.begin(115200);
  fdevopen(&serial_putc, 0);
  printf("Starting...\n");
  pinMode(LED_BUILTIN, OUTPUT);
  digitalWrite(LED_BUILTIN, HIGH);
  testFixtureInputPorts.initializeHardware();
  testFixtureOutputPorts.initializeHardware();
  ledPorts.initializeHardware();
  doAllTests();
}

void loop() {
  // do nothing
}

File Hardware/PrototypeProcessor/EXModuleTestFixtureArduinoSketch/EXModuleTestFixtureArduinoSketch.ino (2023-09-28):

#include <stdio.h>
#include "TestFramework.h"
#include "ShiftRegisterIO.h"
#include "EXModuleTestFixtureIO.h"
#include "LEDPattern.h"

const TestFixtureInputPorts testFixtureInputPorts = {
  .PL = 8,
  .SCK = 7,
  .SO = 6
};

const TestFixtureOutputPorts testFixtureOutputPorts = {
  .SI = 2,
  .RCLK = 3,
  .SCK = 4,
  .CLR = 5
};

const LEDOutputPorts ledPorts = {
  .SI = 17,
  .RCLK = 16,
  .SCK = 15,
  .CLR = 14
};

void testSelC() {
  TestFixtureOutputs testFixtureOutputs;

  printf("%s: ", __FUNCTION__);
  printf("Check that bits of the instruction word are extracted to SelC_MEM...");

  testFixtureOutputs = TestFixtureOutputs().ins(0b11100000000);
  testFixtureOutputPorts.set(testFixtureOutputs);

  // Pulse the clock
  testFixtureOutputs = testFixtureOutputPorts.tick(testFixtureOutputs);  
  
  TestFixtureInputs actualTestFixtureInputs = testFixtureInputPorts.read();
  assertEqual(0b111, actualTestFixtureInputs.SelC_MEM, "Expect that three bits of the instruction bits are extracted to SelC_MEM");

  printf("passed\n");
}

void testControlWordCopiedToNextPipelineStage() {
  TestFixtureOutputs testFixtureOutputs;

  printf("%s: ", __FUNCTION__);
  printf("Check that bits of the control word are copied to the next pipeline stage...");

  testFixtureOutputs = TestFixtureOutputs()
    .ctl(0b111111111111111111111);
  testFixtureOutputPorts.set(testFixtureOutputs);

  // Pulse the clock
  testFixtureOutputs = testFixtureOutputPorts.tick(testFixtureOutputs);  
  
  TestFixtureInputs actualTestFixtureInputs = testFixtureInputPorts.read();
  assertEqual(0b1111111, actualTestFixtureInputs.Ctl_MEM, "Expect that the top seven bits of the control word are passed forward");

  printf("passed\n");
}

static const int kSelStoreOpShift = 1;

void testStoreOp_RegisterB() {
  TestFixtureOutputs testFixtureOutputs;

  printf("%s: ", __FUNCTION__);
  printf("SelStoreOp=0 -> Select RegisterB...");

  testFixtureOutputs = TestFixtureOutputs()
    .b(0xcafe)
    .ctl(0 << kSelStoreOpShift);
  testFixtureOutputPorts.set(testFixtureOutputs);

  // Pulse the clock
  testFixtureOutputs = testFixtureOutputPorts.tick(testFixtureOutputs);  
  
  TestFixtureInputs actualTestFixtureInputs = testFixtureInputPorts.read();
  assertEqual(0xcafe, actualTestFixtureInputs.StoreOp_MEM, "Expect that StoreOp_MEM contains the value of register B");

  printf("passed\n");
}

void testStoreOp_PCPlusOne() {
  TestFixtureOutputs testFixtureOutputs;

  printf("%s: ", __FUNCTION__);
  printf("SelStoreOp=1 -> Select PC...");

  testFixtureOutputs = TestFixtureOutputs()
    .pc(0xcafe)
    .ctl(1 << kSelStoreOpShift);
  testFixtureOutputPorts.set(testFixtureOutputs);

  // Pulse the clock
  testFixtureOutputs = testFixtureOutputPorts.tick(testFixtureOutputs);  
  
  TestFixtureInputs actualTestFixtureInputs = testFixtureInputPorts.read();
  assertEqual(0xcafe, actualTestFixtureInputs.StoreOp_MEM, "Expect that StoreOp_MEM contains the value of PC");

  printf("passed\n");
}

void testStoreOp_Imm() {
  TestFixtureOutputs testFixtureOutputs;

  printf("%s: ", __FUNCTION__);
  printf("SelStoreOp=2 -> Select signed eight-bit immediate value...");

  testFixtureOutputs = TestFixtureOutputs()
    .ins(0xab) // 0b10101011, so high bit is set, and we expect the result to be sign-extended
    .ctl(2 << kSelStoreOpShift);
  testFixtureOutputPorts.set(testFixtureOutputs);

  // Pulse the clock
  testFixtureOutputs = testFixtureOutputPorts.tick(testFixtureOutputs);  
  
  TestFixtureInputs actualTestFixtureInputs = testFixtureInputPorts.read();
  assertEqual(0xffab, actualTestFixtureInputs.StoreOp_MEM, "Expect that StoreOp_MEM contains the value of the signed eight-bit immediate value");

  printf("passed\n");
}

void testStoreOp_ImmUpper() {
  TestFixtureOutputs testFixtureOutputs;

  printf("%s: ", __FUNCTION__);
  printf("SelStoreOp=3 -> Select signed eight-bit immediate value, shifted left...");

  testFixtureOutputs = TestFixtureOutputs()
    .ins(0xab)
    .ctl(3 << kSelStoreOpShift);
  testFixtureOutputPorts.set(testFixtureOutputs);

  // Pulse the clock
  testFixtureOutputs = testFixtureOutputPorts.tick(testFixtureOutputs);  
  
  TestFixtureInputs actualTestFixtureInputs = testFixtureInputPorts.read();
  assertEqual(0xab00, actualTestFixtureInputs.StoreOp_MEM, "Expect that StoreOp_MEM contains the value of the signed eight-bit immediate value, shift left");

  printf("passed\n");
}

void testAdd() {
  TestFixtureOutputs testFixtureOutputs;

  printf("%s: ", __FUNCTION__);
  printf("Add one and one...");

  testFixtureOutputs = TestFixtureOutputs()
    .ins(0)
    .a(1)
    .b(1)
    .ctl(0b110110<<6);
  testFixtureOutputPorts.set(testFixtureOutputs);

  // Pulse the clock
  testFixtureOutputs = testFixtureOutputPorts.tick(testFixtureOutputs);  
  
  TestFixtureInputs actualTestFixtureInputs = testFixtureInputPorts.read();
  assertEqual(2, actualTestFixtureInputs.Y_EX, "Expect that Y_EX==2");
  assertEqual(0, actualTestFixtureInputs.N, "Expect that N==0");
  assertEqual(0, actualTestFixtureInputs.C, "Expect that C==0");
  assertEqual(0, actualTestFixtureInputs.Z, "Expect that Z==0");
  assertEqual(0, actualTestFixtureInputs.V, "Expect that V==0");
  printf("passed\n");
}

void testAddWithCarryOutput() {
  TestFixtureOutputs testFixtureOutputs;

  printf("%s: ", __FUNCTION__);
  printf("Add with carry output...");

  testFixtureOutputs = TestFixtureOutputs()
    .ins(0)
    .a(0xffff)
    .b(1)
    .ctl(0b110110<<6);
  testFixtureOutputPorts.set(testFixtureOutputs);

  // Pulse the clock
  testFixtureOutputs = testFixtureOutputPorts.tick(testFixtureOutputs);  
  
  TestFixtureInputs actualTestFixtureInputs = testFixtureInputPorts.read();
  assertEqual(0, actualTestFixtureInputs.Y_EX, "Expect that Y_EX==0");
  assertEqual(0, actualTestFixtureInputs.N, "Expect that N==0");
  assertEqual(1, actualTestFixtureInputs.C, "Expect that C==1");
  assertEqual(1, actualTestFixtureInputs.Z, "Expect that Z==1");
  assertEqual(0, actualTestFixtureInputs.V, "Expect that V==0");
  printf("passed\n");
}

void testAddWithSignedOverflow() {
  TestFixtureOutputs testFixtureOutputs;

  printf("%s: ", __FUNCTION__);
  printf("Add with signed overflow...");

  testFixtureOutputs = TestFixtureOutputs()
    .ins(0)
    .a(0x7fff)
    .b(1)
    .ctl(0b110110<<6);
  testFixtureOutputPorts.set(testFixtureOutputs);

  // Pulse the clock
  testFixtureOutputs = testFixtureOutputPorts.tick(testFixtureOutputs);  
  
  TestFixtureInputs actualTestFixtureInputs = testFixtureInputPorts.read();
  assertEqual(0x8000, actualTestFixtureInputs.Y_EX, "Expect that Y_EX==0x8000");
  assertEqual(1, actualTestFixtureInputs.N, "Expect that N==1");
  assertEqual(0, actualTestFixtureInputs.C, "Expect that C==0");
  assertEqual(0, actualTestFixtureInputs.Z, "Expect that Z==0");
  assertEqual(1, actualTestFixtureInputs.V, "Expect that V==1");
  printf("passed\n");
}

static const int kSelRightOpShift = 3;
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

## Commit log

2021-12-24 Fix bug where Assignments with a StructInitializer were not compiled
    The expressions were rewritten in terms of a sequence of assignments
    which were not being subsequently compiled to assembly code. Now they
    are.
2021-12-24 Add a test to compile a simple Fibonacci program to Turtle16
    Compile a simple Fibonacci program to Turtle16 assembly code.
    BUG: The compiler prefers to use the narrowest type for literal integers
    that can hold the value. This is the wrong decision on Turtle16 which
    naturally operates on a 16-bit word.
2021-12-27 Fix bug in Register File where SEML and SEMR were pulled low
    The SEML and SEMR inputs of the two dual port SRAMs in the register file
    were both being pulled low. This causes reads and writes to always be
    directed to the eight semaphores instead of the registers. These semaphores
    are not memory and this leads to incorrect operation of the CPU.
    [RegisterFile.sch]
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2022-03-22 Fix bug where assigning 255 to a u16 would sign-extend it to 65535.
    Remove the LIU assembly instruction because the immediate value is always
    sign-extended and this is confusing.
    Change the way we compile li16 so that it always corrects the sign-extended
    bits when necessary.
    Fix broken unit tests in Turtle16SimulatorCore
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2022-03-24 Provide an implementation of the hlt() compiler intrinsic function
    Previously, compile would fail when attempting to compile a program
    actually using this intrinsic function because no function body was
    ever defined. Now, the function body is inserted into the program code.
    Add test_EndToEndIntegration_Hlt
2022-03-26 Fix bug where register allocator fails to find the leading ENTER instr.
    This is a bug with the integration of the register allocator. The register
    allocator expects the first instruction of a subroutine to be an ENTER
    instruction. However, the compiler puts a label declaration first. Fix this
    by changing the Subroutine node so it carries it's own name with it. Insert
    the label declaration later when the Subroutine node is erased.
2022-03-26 Fix a bug when inserted spill code changes the live ranges
    If the register allocator successfully inserts spill code changes which
    changes the live ranges, and proceeds to exit without running again,
    then the recorded allocations will be incorrect. To fix this, rerun the
    live range and allocations procedure every time after spilling.
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2022-04-01 Fix bug in compilation of the Tack LA instruction
    The destination register operand was not correctly converted from the
    Tack register to the corresponding virtual assembly register.
    Add tests:
    * testLA
    * testRebindAFunctionPointerAtRuntime_1
    * testRebindAFunctionPointerAtRuntime_2
2022-04-03 Fix bug where StatementTracer fails to resolve identifier in match
    The statement tracer should trace all clauses of the match statement.
    It should not attempt to resolve the match expression.
2022-04-07 Convert to KiCad 6 project format
    This change also resolves ERC, DRC, and library errors introduced by
    migrating the project to KiCad 6.
    [ALU.kicad_sch, ALU.sch, ALUResultRegister.kicad_sch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]
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2022-04-13 Fix TSSOP-48 footprints on MainBoard PCB
    For some reason, these changed to 8mm footprints instead of the correct
    6mm, perhaps during the KiCad 6 migration.
    [ALUResultRegister.kicad_sch, ALUResultRegister_MEM_WB.kicad_sch, BufferALUResultAsAddr.kicad_sch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]
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2022-04-13 Fix clock inputs on schematic for EX
    [ALU.kicad_sch, ALUResultRegister.kicad_sch, Ctl_13_23_Register.kicad_sch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]
2022-04-13 Fix clock on the EXModule PCB too
    [ALU.kicad_sch, ALUResultRegister.kicad_sch, Ctl_13_23_Register.kicad_sch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]
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2022-04-15 Use 74HC173 for Bank select register because it can reset to zero
    Having the memory bank reset to a known value when power is applied is
    going to be very convenient
    [MEMModule.kicad_pcb, MEMModule.kicad_sch, RAM.kicad_sch]
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2022-04-16 ControlModule: redesign and layout the PCB
    [ControlModule.kicad_pcb, ControlModule.kicad_sch, HazardControl.kicad_sch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]
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2022-04-19 MainBoard: Fix power connector footprint
    [ALUResultRegister.kicad_sch, ALUResultRegister_MEM_WB.kicad_sch, Clock.kicad_sch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]
2022-04-19 MainBoard: Fix footprints for 16374
    [MainBoard.kicad_pcb]
2022-04-19 PCIFModule: fix footprints for 16374
    [PCIFModule.kicad_pcb]
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2022-04-19 MainBoard: fix the footprint on the 7028 and 16374
    [ALUResultRegister.kicad_sch, ALUResultRegister_MEM_WB.kicad_sch, Ctl_13_23_Register.kicad_sch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]
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2022-04-24 MainBoard, ControlModule: route reset signal to HazardControl
    [ControlModule.kicad_pcb, ControlModule.kicad_sch, HazardControl.kicad_sch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]
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2022-05-24 ClockModule: Add delay to clock to fix clock skew issue
    [Clock.kicad_sch, ClockModule.kicad_pcb, ClockModule.kicad_sch]
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2022-09-05 Update ProgrammableLogicDecoder to account for new condition code N
    BUGS: This change necessitates a corresponding hardware change which has
    not been made yet. We still need to route the N condition code through the
    CPU. We now also need to update the schematics to account for changes in
    the pin out of the ATF22V10s which implement instruction decoding.
2022-09-25 Update ControlModule and EXModule to incorporate new N condition code.
    BUGS: The main board schematics and PCB have not been updated yet
    [ALU.kicad_sch, ALUResultRegister.kicad_sch, ControlModule.kicad_pcb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]
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2023-03-22 Add MEMModuleTestFixture board for testing the standalone MEM module
    The standalone MEM module board can be inserted into this test fixture,
    where an Arduino can use shift registers to drive the inputs and read the
    outputs. This permits the Arduino to run a suite of (WIP) integration tests
    on the MEM module. The goal is to be able to fully exercise and validate
    its operation independently of the rest of the computer.
    [MEMModuleTestFixture.kicad_pcb, MEMModuleTestFixture.kicad_sch, MEMPrototypeInputs.kicad_sch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]
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2023-03-25 Backplane: Fix several unconnected signals
    Several signals and control lines were not connected on the backplane PCB
    in Rev A and these are all fixed now.
    Also, update to KiCad 7
    [Backplane.kicad_sch, BypassPrototypeInputs.kicad_sch, BypassPrototypeOutputs.kicad_sch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]
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2023-03-25 EXModuleTestFixture: add new test fixture PCB for EXModule
    Insert the EXModule board into this one and use the on-board Arduino to
    drive the board through a series of verification tests.
    [BypassPrototypeInputs.kicad_sch, BypassPrototypeOutputs.kicad_sch, EXModuleTestFixture.kicad_pcb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]
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2023-03-25 Remove obsolete MiniITXAdapterPlate project
    This adapter plate was designed to work with an older version of the main
    board PCB and is now obsolete. In any case, I no longer intend to build the
    Turtle16 computer inside a Mini-ITX computer case.
    [MiniITX.kicad_pcb]
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2023-03-30 Begin work on MEMModuleTestFixtureArduinoSketch
    This is a test suite which runs on MEMModuleTestFixture to drive MEMModule
    and verify correct operation of the hardware. Begin with two simple tests
    and we'll expand from there.
    testReset: Puts MEM through the reset cycle
    testNop: Puts through control signals same as a NOP instruction
    [MEMModuleTestFixtureArduinoSketch.ino]
2023-04-02 MEMModule: Arduino sketch reorganized into multiple files
    Reorganize the test suite into multiple source files and headers.
    The test framework pieces are are written with an eye toward being able to
    reuse across different test fixtures for other modules.
    [BusIO.cpp, MEMModuleTestFixtureArduinoSketch.ino, MEMModuleTestFixtureIO.cpp]
2023-04-02 MEMModuleTestFixture: Fix bug where we miss a bit shifting in the inputs
    [MEMModuleTestFixtureIO.cpp]
2023-04-02 MEMModule: fix silkscreen error on Ctl_WB connector
    [MEMModule.kicad_pcb]
2023-04-02 MainBoard: Replace Through Hole LEDs with SMD LEDs
    [Clock.kicad_sch, RAM.kicad_sch]
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2023-04-02 Bring back the ROM-less versions of MEMModule and MainBoard
    The ROM-less versions of MEMModule and MainBoard now live in the repo again
    in their own, separate projects. These boards are not really reivsions of
    MEMModule and MainBoard. The term revision should be reserved for fixes
    and improvements. The changes here make these variant hardware devices
    which I may very well want to build some day soon.
    [ALU.kicad_sch, ALUResultRegister.kicad_sch, ALUResultRegister_MEM_WB.kicad_sch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]
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2023-04-03 MEMModule: These methods in the test software ought to be const
    The Arduino IDE doesn't catch this but a const object should not be able to
    call non-const methods. Fix by simply marking the methods are const.
    [BusIO.cpp, MEMModuleTestFixtureIO.cpp]
2023-04-03 MEMModuleTestFixture: Fix schematic part number for the 74HCT05
    [MEMModuleTestFixture.kicad_pcb, TestFixtureOutputs.kicad_sch]
2023-04-07 MEMModule: Fix bug in the bank register reset signal
    The bank register expects an active-high reset signal but was wired to
    receive an active-low signal. Fix this issue by routing /RST_sync through
    an inverter first.
    BUG: The MainBoard PCB layout has not been updated yet.
    [ALU.kicad_sch, ALUResultRegister.kicad_sch, ALUResultRegister_MEM_WB.kicad_sch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]
2023-04-07 EXModuleTestFixture: LEDs should be on a separate shift register chain
    Lessons learned from MEMModuleTestFixture include the lesson that status
    LEDs should be updated separately from test fixture outputs. This allows
    test progress to be reported independently of the tests themselves.
    [EXModuleTestFixture.kicad_pcb, EXModuleTestFixture.kicad_sch, EXPrototypeInputs.kicad_sch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]
2023-04-07 ControlModule: Add test fixture PCB
    [ControlModuleTestFixture.kicad_pcb, ControlModuleTestFixture.kicad_sch, IDPrototypeInputs.kicad_sch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]
2023-04-08 MEMModule, MainBoard: Update PCB layouts again
    Update PCB layouts to account for recent bug fix in the bank register reset
    signal. The layouts were produced with the auto-router and I allowed the
    optimizer to run for a good long while.
    [MEMModule.kicad_pcb, MainBoard.kicad_pcb]
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2023-09-26 ControlModule: hazard control should use Ctl_Mid instead of Ctl_EX
    BUG: The monolithic mainboard has not been updated yet.
    [ControlModule.kicad_pcb, ControlModule.kicad_sch, HazardControl.kicad_sch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]
2023-09-26 Update schematics for the MainBoard to include the ControleModule fix from 704c0dce
    [ALU.kicad_sch, ALUResultRegister.kicad_sch, ALUResultRegister_MEM_WB.kicad_sch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]
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2023-10-02 MainBoard: fixed footprints which were accidentally overlapping
    [MainBoard.kicad_pcb]
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2023-10-03 MEMModule: ROM ought to be controlled by RAMEN_R signal
    The right side of the RAM is connected to the instruction fetch unit.
    The left side of the RAM is connected to the system bus.
    The ROM should only be enabled in the instruction fetch unit when the right
    side of RAM is not selected. Tying it to RAMEN_L is a bug.
    [MEMModule.kicad_pcb, Memory.kicad_sch, ROM.kicad_sch]
2023-10-03 MainBoard: apply the MEMModule bug fix to RAM control logic
    [ALU.kicad_sch, ALUResultRegister.kicad_sch, ALUResultRegister_MEM_WB.kicad_sch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]
2023-10-04 MEMModule: fix bug where SelC_WB was labelled incorrectly on the silkscreen
    [MEMModule.kicad_pcb]
2023-10-04 MEMModule: fix typo in the schematic
    [System Bus Connector.kicad_sch]
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2023-10-09 ClockModule: The Phi1 clock will tick during reset even when RDY is low.
    Previously, pulling RDY low during the reset cycle would prevent the Phi1
    clock from ticking and thus prevent the pipeline from being flushed. Now,
    the Phi1 clock will tick during the reset cycle regardless of the state of
    the RDY signal.
    Note that the MainBoard PCB does not yet incorporate these changes.
    [Clock.kicad_sch, ClockModule.kicad_pcb]
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2023-10-09 ClockModule: fix bug in generation of Phi1_1 signal
    [Clock.kicad_sch, ClockModule.kicad_pcb]
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2023-10-09 ControlModule: Replace 8mm TSSOP-48 footprints with 6.1mm
    [ControlModule.kicad_pcb, ControlModule.kicad_sch, HazardControl.kicad_sch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]
2023-10-09 MainBoard: update MainBoard to ensure correct TSSOP-48 footprints too
    [IDPrototypeInputs.kicad_sch, ID_EX_ControlWord.kicad_sch, ID_EX_InstructionWord.kicad_sch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]
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2023-10-12 MEMModule: Add test fixture test suite for MEMModule
    [MEMModuleTestFixtureArduinoSketch.ino]
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2023-10-14 ClockModule: apply bodge for Phi1_1 bug
    Cannot latch Phi1_0 in U6 register because it would never meet setup
    timing requirements of the register.
    [Clock.kicad_sch]
2023-10-14 ClockModule: apply second bodge for Phi1_1 bug
    Must delay the clock signal before it goes into U7A, else a clock
    glitch occurs when the Resume button is pressed. If we replace the
    input of U7A with the Phi2 clock signal then the glitch goes away.
    Phi2 is already buffered with inverters which would provide such
    a delay anyway.
    Phi1 and Phi2 are slighly out of phase as a result, but the difference
    seems like it would be acceptable.
    [Clock.kicad_sch]
2023-10-14 ClockModule: clean up bodges for Rev D
    [Clock.kicad_sch, ClockModule.kicad_sch]
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2023-10-15 ClockModule: fix bug where 245 was wired wrong
    [Clock.kicad_sch, ClockModule.kicad_pcb]
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2023-10-29 MEMModule: incorporate fix to the bank register in Rev D
    [ALUResultRegister_MEM_WB.kicad_sch, BufferALUResultAsAddr.kicad_sch, BufferMemoryControlSignals.kicad_sch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]
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2023-10-31 ControlModule: Fix ID stall bug
    Fix the bug where the control unit activates all control signals during a
    STALL instead of deactivating all control signals.
    [ControlModule.kicad_pcb, ControlModule.kicad_sch, HazardControl.kicad_sch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]
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2023-11-05 RegisterFileModule: Fix write-back timing bug
    Fix the bug where the /WR signal to the SRAMs was arriving at an invalid
    time. The signal arrival is now delayed by a series of logic gates. The
    signal is deasserted before other inputs change by gating it against the
    Phi2 clock.
    Note that the main board schematic and PCB has not yet been updated.
    [RegisterFile.kicad_sch, RegisterFileModule.kicad_pcb, RegisterFileModule.kicad_sch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]
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2023-11-06 MainBoard: Update schematics and PCB placement for ControlModule changes
    This includes the fix for the STALL bug and the control signal ordering
    bug. The PCB trace routing has been cleared and is not updated yet.
    [ALU.kicad_sch, ALUResultRegister.kicad_sch, ALUResultRegister_MEM_WB.kicad_sch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]
2023-11-06 MainBoard: Update schematics and PCB placement for Register File fix
    This includes changes to fix the register file timing issue with the
    /WBEN signal.
    [ALU.kicad_sch, ALUResultRegister.kicad_sch, Ctl_13_23_Register.kicad_sch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]
2023-11-06 MainBoard: Update schematics and PCB for pull-up resistor change in MEM
    This fixes an issue with /MemStore and /MemLoad by giving them pull-up
    resistors instead of pull-down. These are active-low signals so pulling
    them High when not in-use is the better thing to do.
    PCB trace routing has still not been redone yet.
    [MainBoard.kicad_pcb, System Bus Connector.kicad_sch]
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2023-11-08 MEMModule: Add jumper for single-step mode
    This works around an issue where MEM never asserts signals to the bus in
    single-step mode. Now, we can set the jumper to force MEM to assert these
    signals as-if the computer is ready, even when it's not.
    [MEM.kicad_sch, MEMModule.kicad_pcb, MEMPrototypeOutputs.kicad_sch]
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2023-11-15 ControlModule: Update with fix for Rev E
    * The Rev D control module had a bug where it would incorrectly determine
    flag hazards and jumps.
    * HazardControl2.pld updated for Rev D and Rev E of the control module
    * Updated the control module test suite with tests to exercise the above
    NOTE: The MainBoard project has not yet been updated with these changes.
    [ControlModule.kicad_pcb, ControlModule.kicad_sch, HazardControl.kicad_sch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]
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2023-11-18 ControlModule: Fix second issue in Rev D with Ctl_Mid/Ctl_EX
    Two more signals in Hazard Control were using signals from Ctl_Mid when
    they should have instead been using signals from Ctl_EX. This fixes an
    issue where the control module is unable to correctly detect a RAW hazard
    in the EX stage.
    NOTE: The processor board has not yet been updated with this change.
    [ControlModule.kicad_pcb, HazardControl.kicad_sch]
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2023-11-19 ProcessorBoard: Update with changes to Control module Ctl_Mid/Ctl_EX issue
    This fixes the second issue in Rev D with Ctl_Mid/Ctl_EX.
    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
    [ALU.kicad_sch, ALUResultRegister.kicad_sch, ALUResultRegister_MEM_WB.kicad_sch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]
2023-11-19 ProcessorBoard: Replace Clock with ClockDistribution
    The processor board replaces the Clock with a Clock Distribution module.
    The clock signals now come in on the bus connector. Also, the outline of
    the processor card PCB has been reduced to 8" x 8".
    NOTE: The new PCB has not been routed yet.
    [Clock.kicad_sch, ClockDistribution.kicad_sch, ProcessorBoard.kicad_sch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]
2023-11-20 ProcessorBoard: MEM no longer uses RDY signal
    The open-drain RDY signal has been removed from the processor. Instead, the
    process outputs /HLT to the system bus where it can be picked up by the
    clock on the main board.
    NOTE: This is a major difference between ProcessorBoard and MEMModule
    right now.
    [BufferALUResultAsAddr.kicad_sch, BufferMemoryControlSignals.kicad_sch, BufferStoreOpAsBusIO.kicad_sch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]
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2023-11-20 ProcessorBoard: update to include M/S bug fix in register file
    [ALU.kicad_sch, ALUResultRegister.kicad_sch, ALUResultRegister_MEM_WB.kicad_sch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]
2023-11-20 ProcessorBoard and MEMModule are updated to put 7028 SRAM into /S mode
    This will avoid issues with writes being inhibited by the onboard write
    arbitration logic. The programmer will be advised to avoid writing to
    memory as it is executing. However, this ought to work now per the data
    sheet which states that a simultaneous write and read to the same cell will
    work so long as certain timing constraints are obeyed, and we ought to be
    doing that now.
    This is the same change which was necessary to fix the register file.
    NOTE: The MEMModule and ProcessorBoard still have divergent MEM units. The
    ProcessorBoard removes the open-drain RDY signal and accepts clock inputs
    through the bus connector. T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
    [MEMModule.kicad_pcb, ProcessorBoard.kicad_pcb, RAM.kicad_sch]
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2023-11-21 Added ROMDaughterBoard PCB
    ROMs are on a daughter board so they can be easily swapped. The entire
    module could also be replaced in the future with a cartridge slot or a
    ZIF socket.
    [ROMDaughterBoard.kicad_pcb, ROMDaughterBoard.kicad_sch]
2023-11-21 ProcessorBoard: Replace Instruction ROM with a header for a daughter board
    ROMs will be relocated to a daughter board to allow the memories and their
    sockets to be swapped easily.
    [ALU.kicad_sch, ALUResultRegister.kicad_sch, ClockDistribution.kicad_sch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]
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2023-11-22 ProcessorBoard: Replace µF with uF because some software gets confused.
    [ALUResultRegister_MEM_WB.kicad_sch, BufferALUResultAsAddr.kicad_sch, BufferMemoryControlSignals.kicad_sch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]
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2023-11-23 Added new MainBoard PCB.
    The new MainBoard PCB contains the clock, reset logic, and bus termination.
    The processor and all peripherals connect to a ribbon cable which
    terminates at the main board.
    [Clock.kicad_sch, MainBoard.kicad_pcb, MainBoard.kicad_sch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]
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2023-11-27 MainBoard: schematics no longer mention /SINGLE mode
    [Clock.kicad_sch]
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2023-11-27 Added ProcessorBoardTestFixture
    This is a test fixture for ProcessorBoard which has the same form factor
    as the main board. It tests the processor through the system memory bus
    when an appropriate program has been loaded into the processor,
    corresponding to the test suite.
    [LEDOutputs.kicad_sch, ProcessorBoardTestFixture.kicad_pcb, ProcessorBoardTestFixture.kicad_sch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]
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2023-11-28 ProcessorBoardTestFixture: Add header for controlling instruction fetch
    This allows the test fixture to control the program running on the
    processor board during testing.
    [InstructionROMInterface.kicad_sch, LEDOutputs.kicad_sch, ProcessorBoardTestFixture.kicad_pcb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]
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2025-06-30 Make sure all KiCAD projects paths are correct, and project files are updated to KiCAD 7
    [ALU.kicad_sch, ALUResultRegister.kicad_sch, Ctl_13_23_Register.kicad_sch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]
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2025-07-05 Reannotate schematic by hand since extracting to new sheets broke existing annotations
    [ALU.kicad_sch, ALUResultRegister.kicad_sch, ALUResultRegister_MEM_WB.kicad_sch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]
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2025-07-05 Update symbols and footprints from library to resolve ERC and DRC warnings
    [ALU.kicad_sch, ALUResultRegister.kicad_sch, ALUResultRegister_MEM_WB.kicad_sch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]
2025-07-05 Automatically reannotate project and fix a few silkscreen-related issues
    [ALU.kicad_sch, ALUResultRegister.kicad_sch, ALUResultRegister_MEM_WB.kicad_sch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]
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2025-07-05 Replace MEMModule with a connector to a separate PCB
    [ALU.kicad_sch, ALUResultRegister.kicad_sch, BypassModule.kicad_sch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]
2025-07-05 Replace EXModule with a connector to a separate PCB
    [ALU.kicad_sch, ALUResultRegister.kicad_sch, Ctl_13_23_Register.kicad_sch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]
2025-07-05 Replace Bypass module with a connector to a separate PCB
    [BypassModule.kicad_sch, MainBoard.kicad_sch]
2025-07-05 Replace ControlModule with a connector to a separate PCB
    [ControlModule.kicad_sch, HazardControl.kicad_sch, HazardControlComparators.kicad_sch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]
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2025-07-05 Fix the broken edge cuts on the EX module
    [EXModule.kicad_pcb]
2025-07-05 Lock down PCB objects that are already placed correctly
    [EXModule.kicad_pcb]
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2025-07-05 Add a keepout zone to prevent PCB traces and vias in the area which will be chamfered
    [EXModule.kicad_pcb]
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2025-07-06 EXModule: fix DRC errors related to unused signals on Ctl_EX
    [CardEdgeEX.kicad_sch]
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2025-07-07 EXModule: add a keepout zone to prevent vias in the card edge connector
    [EXModule.kicad_pcb]
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2025-07-13 MainBoard: more changes to the PCB route, and fix broken labels on clock test points
    [Clock.kicad_sch]
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2025-07-23 Annotate schematics such that Turtle16Computer can perform ERC and DRC
    - Turtle16Computer must be fully annotated to perform ERC on the schematic.
    Also, the PCB cannot be updated without full annotations either. However,
    KiCad projects for individual PCBs must also remain annotated and capable
    of updating the PCB and performing ERC and DRC.
    - Manually set KiCad project fields to "" in kicad_sch files
    - Manually replace the UUID of EXCard so it no longer collides with the
    UUI of the Turtle16Computer project.
    [ALU.kicad_sch, ALUResultRegister.kicad_sch, ALUResultRegister_MEM_WB.kicad_sch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]
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2025-07-29 MainBoard: Add series termination resistors and additional bulk capacitors
    Clock and control signals generated on the main board now have series
    termination resistors. These are specified now as zero ohm resistors, and
    can be easily swapped for different values if needed.
    There are pads for bulk capacitors next to each card slot. These are
    specfied as Do Not Populate, and can be easily populated if needed.
    [BypassModule.kicad_sch, Clock.kicad_sch, ClockDistribution.kicad_sch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]
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2025-07-31 Fix incorrect keyway dimensions for Samtec MEC5 card edge
    The top of the rounded edge of the keyway should be 5.5mm from the bottom
    edge, not 6.5mm. Fix this in the footprint and then update all of the card
    PCBs accordingly.
    [BypassCard.kicad_pcb, ControlCard.kicad_pcb, EXCard.kicad_pcb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]
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2025-08-01 CardTestFixture: add new test fixture project, but PCB is not routed yet
    [Arduino.kicad_sch, BlinkenLights.kicad_sch, CardSlot.kicad_sch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]
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2025-08-01 CardTestFixture: update LEDs and resistor values to avoid exceeding the 125mA limit
    [BlinkenLights.kicad_sch, CardTestFixture.kicad_pcb]
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

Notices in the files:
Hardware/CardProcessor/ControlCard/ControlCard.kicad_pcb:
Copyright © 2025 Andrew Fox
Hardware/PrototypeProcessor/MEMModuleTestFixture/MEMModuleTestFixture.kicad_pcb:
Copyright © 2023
